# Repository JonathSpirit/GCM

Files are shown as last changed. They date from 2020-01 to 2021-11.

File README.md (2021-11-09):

# GCM - GCardMother

Copyright (C) 2021 Guillaume Guillet\
Licensed under CERN-OHL-W v2 or later

<table border="0px">
<tr>
<td>
This source describes Open Hardware and is licensed under the CERN-OHL-W v2 or later.
</td>
</tr>
<tr>
<td>
You may redistribute and modify this documentation and make products
using it under the terms of the CERN-OHL-W v2 (https:/cern.ch/cern-ohl).
This documentation is distributed WITHOUT ANY EXPRESS OR IMPLIED
WARRANTY, INCLUDING OF MERCHANTABILITY, SATISFACTORY QUALITY
AND FITNESS FOR A PARTICULAR PURPOSE. Please see the CERN-OHL-W v2
for applicable conditions.
</td>
</tr>
</table>

Made with [Kicad](https://kicad.org/)

## Description
G_CardMother is a homemade without any microcontroller motherboard for 8bits processor compatible with the [MOM1_SPS1 standard](https://github.com/JonathSpirit/GComputer_standard) like [GP8B](https://github.com/JonathSpirit/GP8B)

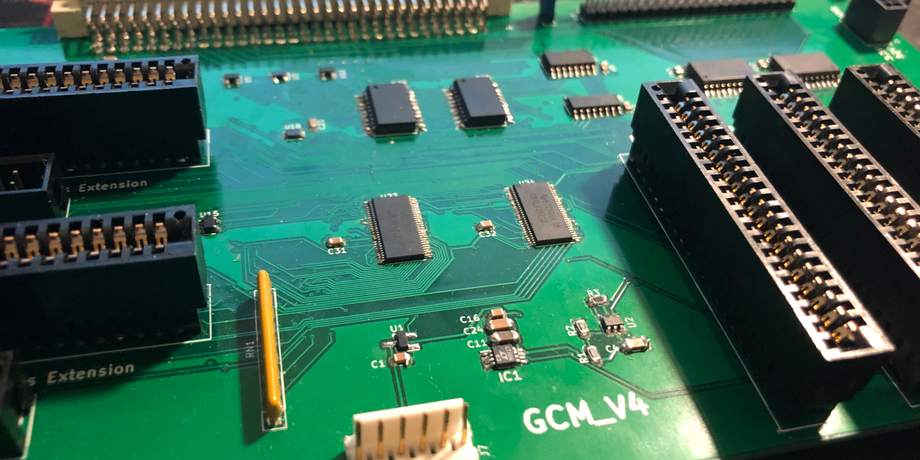
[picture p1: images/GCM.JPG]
GCM_image
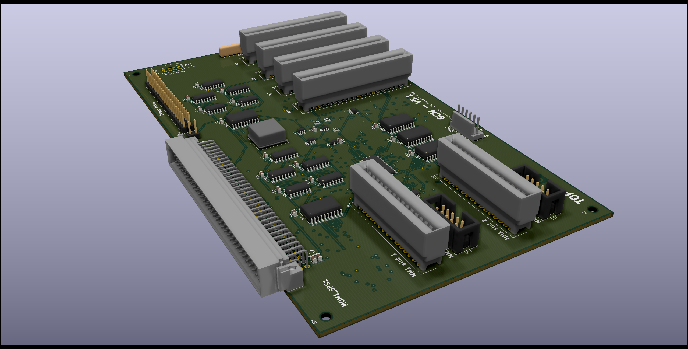
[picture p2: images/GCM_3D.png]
GCM_3D_image
 
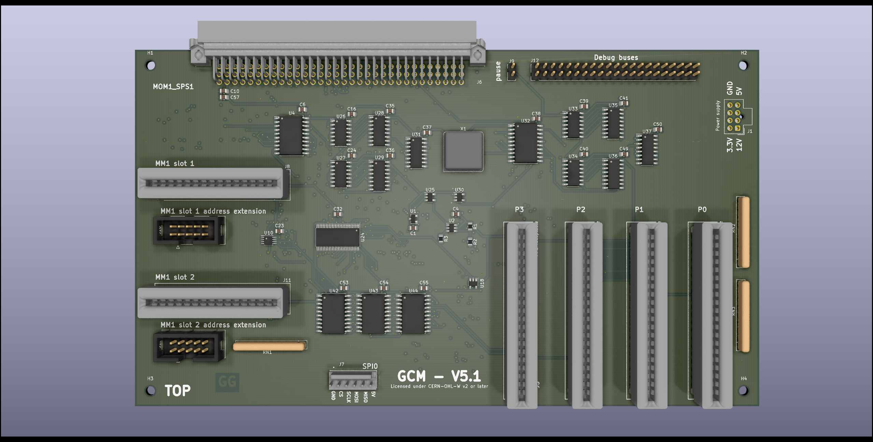
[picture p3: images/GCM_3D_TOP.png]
GCM_3D_TOP_image
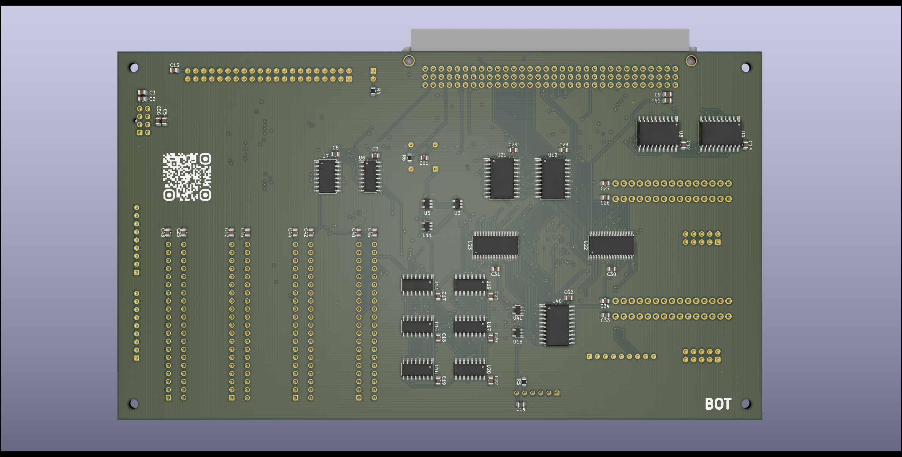
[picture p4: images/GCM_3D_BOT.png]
GCM_3D_BOT_image
 

## Stats





\
\
\


## Block diagram

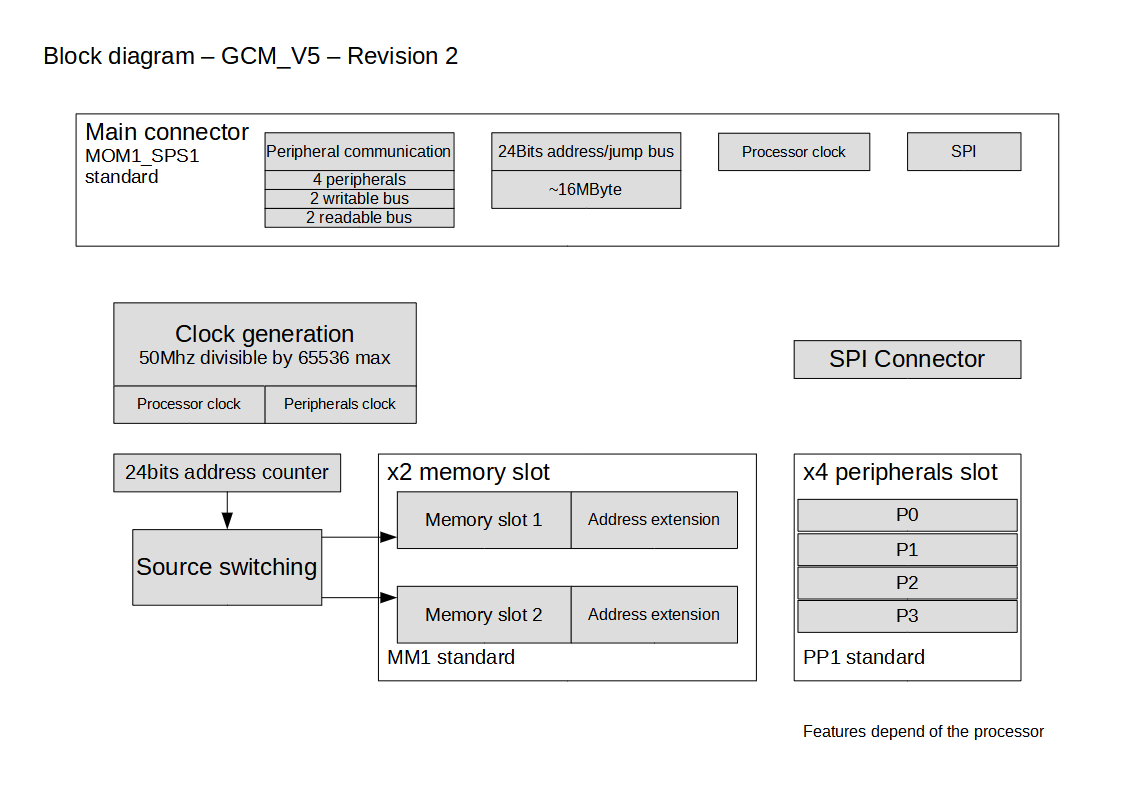
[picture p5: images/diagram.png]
Image of diagram


## Main features

- Follow the [MOM1_SPS1](https://github.com/JonathSpirit/GComputer_standard) standard.

- A max frequency of 50Mhz divisible by multiples of two (up to a division of 65536).
  For the processor and a seperated line for peripherals.

- 4 [PP1](https://github.com/JonathSpirit/GComputer_standard) peripherals slot.

- 2 [MM1](https://github.com/JonathSpirit/GComputer_standard) memory slot with address extension.

- Code execution from the memory slot 1 and switchable with the memory slot 2.

- Redirection of the writing buses (can be used as buffer).

- Accessible debug pins.

## Motherboard standard
This motherboard, follow the [MOM1_SPS1](https://github.com/JonathSpirit/GComputer_standard) standard

## Compatibility
Should be compatible with all processor following the [SPS1](https://github.com/JonathSpirit/GComputer_standard) standard

| Processor | Compatibility |
| --- | --- |
| [GP8B_V4.x](https://github.com/JonathSpirit/GP8B/tree/V4.0)  |   |
| [GP8B_V5.0](https://github.com/JonathSpirit/GP8B/tree/V5.0)  |   |
| [GP8B_V5.1+](https://github.com/JonathSpirit/GP8B/tree/V5.1)  |   |





## Documents
[Block diagram (.pdf)](documents/blockDiagram/GCM_blockDiagram.pdf)

[Schematics (.pdf)](documents/GCM_schematics.pdf)

[Materials (.pdf)](documents/GCM_materials.pdf)

[Datasheet (.pdf)](documents/GCM_datasheet.pdf)

## Contributing / Questions
Please see [Contributing file](CONTRIBUTING.md)

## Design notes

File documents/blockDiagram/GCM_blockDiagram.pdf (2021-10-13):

## x4 peripherals slot

### PP1 standard

## Clock generation

50Mhz divisible by 65536 max | SPI Connector

P0

## Block diagram – GCM_V5 – Revision 2

P1
P2
P3

## x2 memory slot

### MM1 standard

Memory slot 1 | Address extension
Memory slot 2 | Address extension

## Source switching

### 24bits address counter

## Main connector

MOM1_SPS1
standard
Peripheral communication | 24Bits address/jump bus | Processor clock
4 peripherals

2 readable bus

2 writable bus

SPI

| ~16MByte

Features depend of the processor

Processor clock Peripherals clock

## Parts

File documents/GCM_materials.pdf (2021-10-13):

1

GCM_materials.fods

GCM | V5.1
Author : Guillaume Guillet | Revision 1 | Licensed under CERN-OHL-W v2 or later
Type | Value | Q | References | Package | Manufacturer | Store | Store ID | Unit price* | Price
C | 10nF | 33 | C1, C6 to C8, C12, C13, C16 to C24, C28 to C32, C35 to C41, C49, C50, C52 to C55 | C_0805_2012Metric | KEMET | Mouser | 80-C0805C103J5R | 0.033 | 1.089
| 100nF | 20 | C3 to C5, C9 to C11, C14, C15, C25 to C27, C33, C34, C42 to C48 | C_0805_2012Metric | KEMET | Mouser | 80-C0805C104M3R | 0.032 | 0.64
| 1uF | 4 | C2, C51, C56, C57 | C_0805_2012Metric | KEMET | Mouser | 80-C0805C105K3R7210 | 0.132 | 0.528
X1 | ECS-2200BX-500 | 1 | X1 | Oscillator_DIP-8 | ECS | Mouser | 520-2200BX-500 | 2.92 | 2.92
U | 74AHC273 | 6 | U4, U32, U40, U42 to U44 | SOIC-20W_7.5x12.8mm_Pitch1.27mm | Texas Instruments | Mouser | 595-SN74AHC273DWR | 0.403 | 2.418
| LM810 | 1 | U1 | SOT-23-3 | Texas Instruments | Mouser | 926-LM810M3463NOPB | 0.696 | 0.696
| LTC6994-1 | 1 | U2 | SOT-23-6 | Analog Devices | Mouser | 584-C6994IS6-1TRMPBF | 3.65 | 3.65
| CD74AC161M | 6 | U13, U14, U16, U17, U19, U20 | SOP-16_3.9x9.9mm_P1.27mm | Texas Instruments | Mouser | 595-CD74AC161M | 0.751 | 4.506
| CD74AC151 | 6 | U28, U29, U31, U35 to U37 | SOP-16_3.9x9.9mm_P1.27mm | Texas Instruments | Mouser | 595-CD74AC151M96 | 0.823 | 4.938
| SN74LV393A | 4 | U26, U27, U33, U34 | SOIC-14_3.9x8.7mm_P1.27mm | Texas Instruments | Mouser | 595-SN74LV393ADR | 0.796 | 3.184
| CD74AC238 | 1 | U6 | SOP-16_3.9x9.9mm_P1.27mm | Texas Instruments | Mouser | 595-CD74AC238M96 | 0.549 | 0.549
| 74AHC244 | 3 | U8, U9, U12 | SOIC-20W_7.5x12.8mm_Pitch1.27mm | Texas Instruments | Mouser | 595-SN74AHC244DWR | 0.448 | 1.344
| 74AHCT244 | 1 | U21 | SOIC-20W_7.5x12.8mm_Pitch1.27mm | Texas Instruments | Mouser | 595-SN74AHCT244DWR | 0.448 | 0.448
| 74AHC138 | 1 | U7 | SOIC-16W_5.3x10.2mm_P1.27mm | Texas Instruments | Mouser | 595-SN74AHC138NSR | 0.494 | 0.494
| 74AHC1G04 | 4 | U5, U11, U18, U41 | SOT-23-5 | Texas Instruments | Mouser | 595-SN74AHC1G04DBVR | 0.266 | 1.064
| 74AHCT1G04 | 1 | U15 | SOT-23-5 | Texas Instruments | Mouser | 595-SN74AHCT1G04DBVR | 0.311 | 0.311
| 74AHC1G32 | 3 | U3, U25, U30 | SOT-23-5 | Texas Instruments | Mouser | 595-SN74AHC1G32DBVR | 0.266 | 0.798
| 74LVC1G74 | 1 | U10 | SM-8 | Texas Instruments | Mouser | 595-SN74LVC1G74DCTR | 0.604 | 0.604
| 74CBTLV16212 | 3 | U22 to U24 | TSSOP-56 | Texas Instruments | Mouser | 595-SN74CBTLV16212GR | 2.03 | 6.09
R | 523k | 1 | R1 | R_0805_2012Metric | Panasonic | Mouser | 667-ERJ-PB6D5233V | 0.256 | 0.256
| 1M | 1 | R2 | R_0805_2012Metric | Panasonic | Mouser | 667-ERJ-6RED1004V | 0.192 | 0.192

# Project :

2

GCM_materials.fods

| 305k | 1 | R3 | R_0805_2012Metric | Panasonic | Mouser | 667-ERA-6AED3093V | 0.229 | 0.229
| 10k | 3 | R4 to R6 | R_0805_2012Metric | Yageo | Mouser | 603-RT0805FRE0710KL | 0.11 | 0.33
RN | 8x10k | 3 | RN1 to RN3 | R_Array_SIP9 | Bourns | Mouser | 652-4609X-1LF-10K | 0.247 | 0.741
J | TE_Eurocard_96pole | 1 | J6 | Eurocard_5650473-5 Receptacle | TE connectivity | Mouser | 571-5650461-5 | 5.38 | 5.38
| Nano-Fit power connectors | 1 | J1 | Molex_1053102116 | Molex | Mouser | 538-105310-1108 | 1.6 | 1.6
| 5530843-2 | 2 | J8, J11 | TE_5530843-2 | TE connectivity | Mouser | 571-5530843-2 | 2.33 | 4.66
| 5-5530843-4 | 4 | J2 to J5 | 5-5530843-4 | TE connectivity | Mouser | 571-5-5530843-4 | 2.84 | 11.36
| 3-641124-6 | 1 | J7 | 3-641124-6 | TE connectivity | Mouser | 571-3-641124-6 | 1.36 | 1.36
| Header10p | 2 | J10, J13 | Header_10p_2.54 | Wurth Electronics | Mouser | 710-61201021621 | 0.411 | 0.822
| Conn_01x02_Male | 1 | J9 | PinHeader_1x02_P2.54mm_Vertical | TE connectivity | Mouser | 571-1037412 | 0.234 | 0.234
| Conn_02x21_Male | 1 | J12 | PinHeader_2x21_P2.54mm_Vertical | TE connectivity | Mouser | 571-9-146258-0 | 3.22 | 3.22
- | PCB_GCM_V5.x | 1 | - | - | G.Guillet | - | | | 0
Total price : | 66.655
*Depend of the quantity | Price is in CHF

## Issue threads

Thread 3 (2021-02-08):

Component J9 in the BOM is wrong

JonathSpirit, 2021-02-08:
The component J9, ref 571-6404524 from Mouser is wrong

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

Wanted :
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

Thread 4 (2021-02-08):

Component J12 must be a male connector

JonathSpirit, 2021-02-08:
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

(wrong footprint)

JonathSpirit, 2021-02-16:
And J9 too

JonathSpirit, 2021-02-16:
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

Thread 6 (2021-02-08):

Need another footprint for J7

JonathSpirit, 2021-02-08:
The actual footprint doesn't match the component in the BOM

JonathSpirit, 2021-02-16:
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

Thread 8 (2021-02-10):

Back a little the MM1 connectors

JonathSpirit, 2021-02-10:
the connectors are a little too close to the edge

JonathSpirit, 2021-02-16:
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

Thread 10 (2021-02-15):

Need 1uF or more power decoupling next to the nano-fit power connector

JonathSpirit, 2021-02-15:
I think that the motherboard need better and bigger decoupling capacitor next to the power connector

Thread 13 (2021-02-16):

For U22 U23 U24, replace the decoupling capacitor

JonathSpirit, 2021-02-16:
capa must be placed between pin 17 and 8

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

JonathSpirit, 2021-02-16:
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

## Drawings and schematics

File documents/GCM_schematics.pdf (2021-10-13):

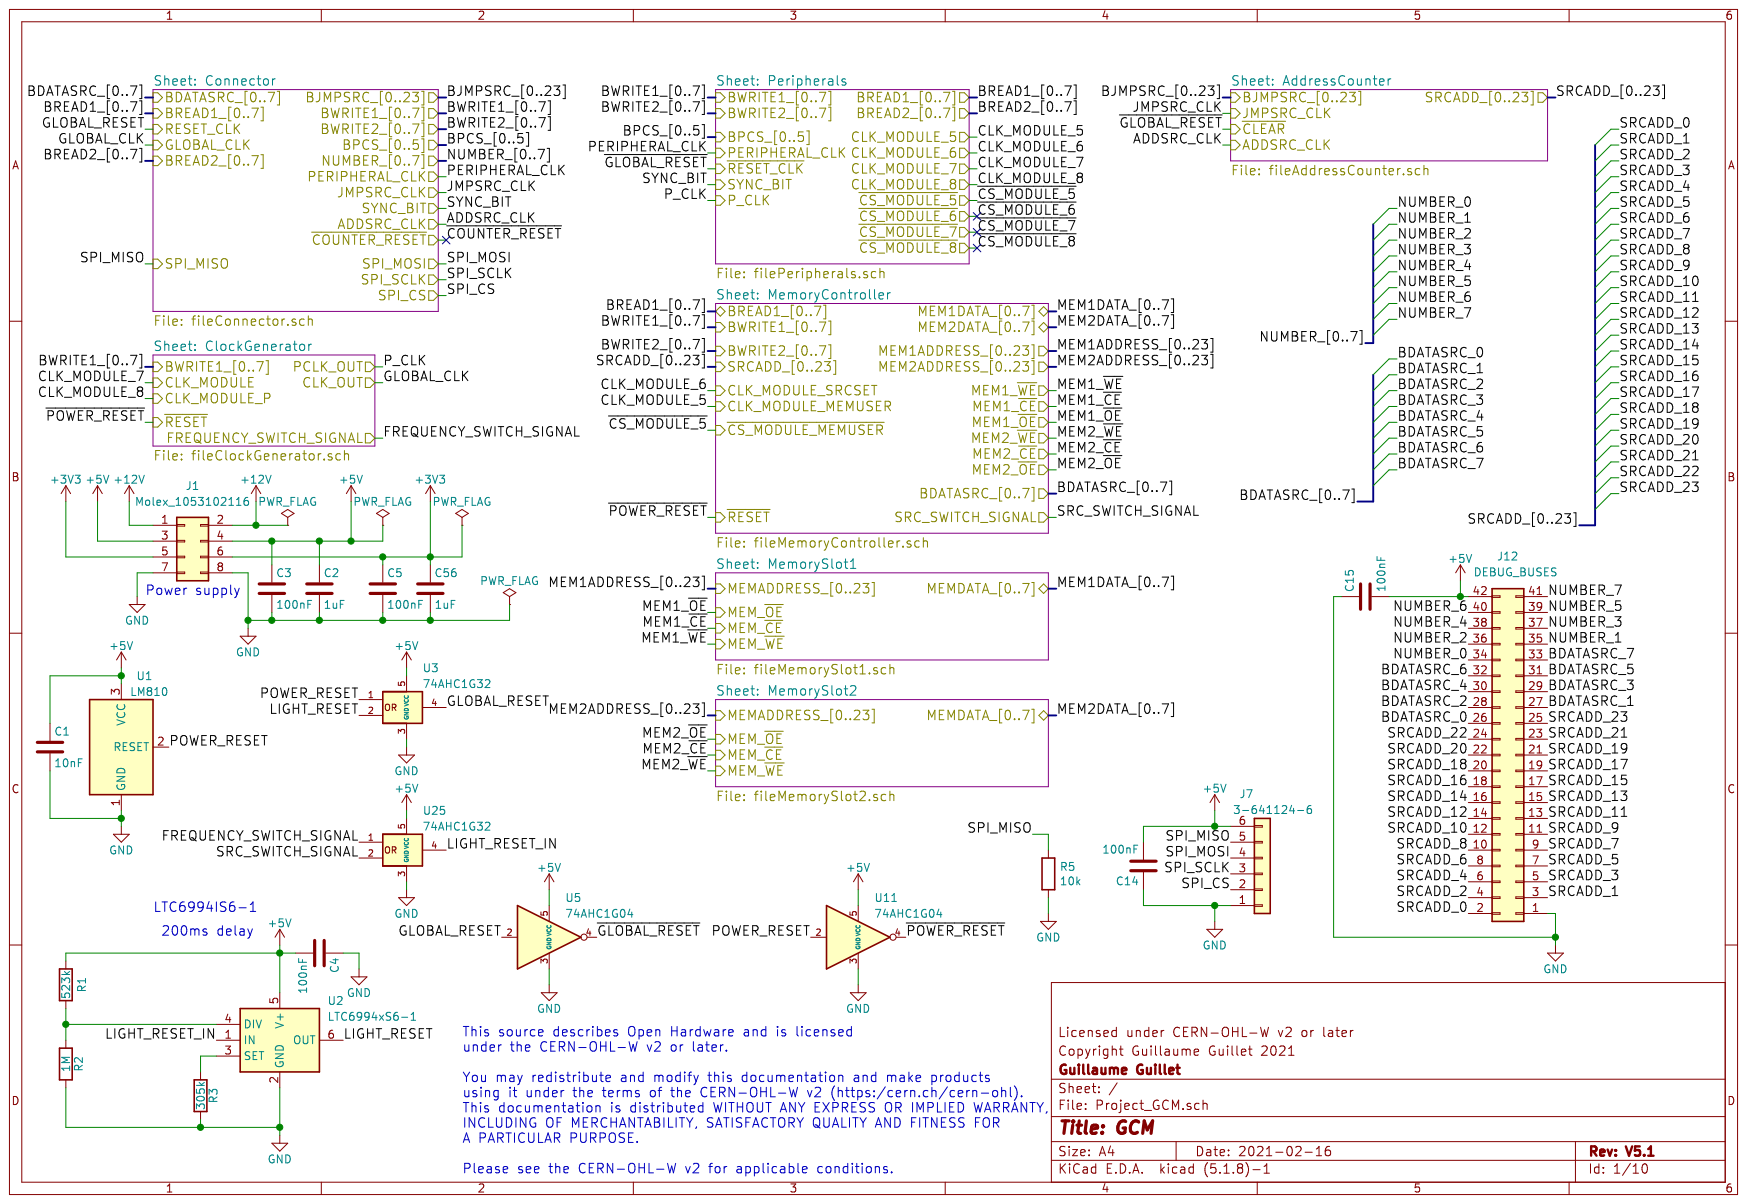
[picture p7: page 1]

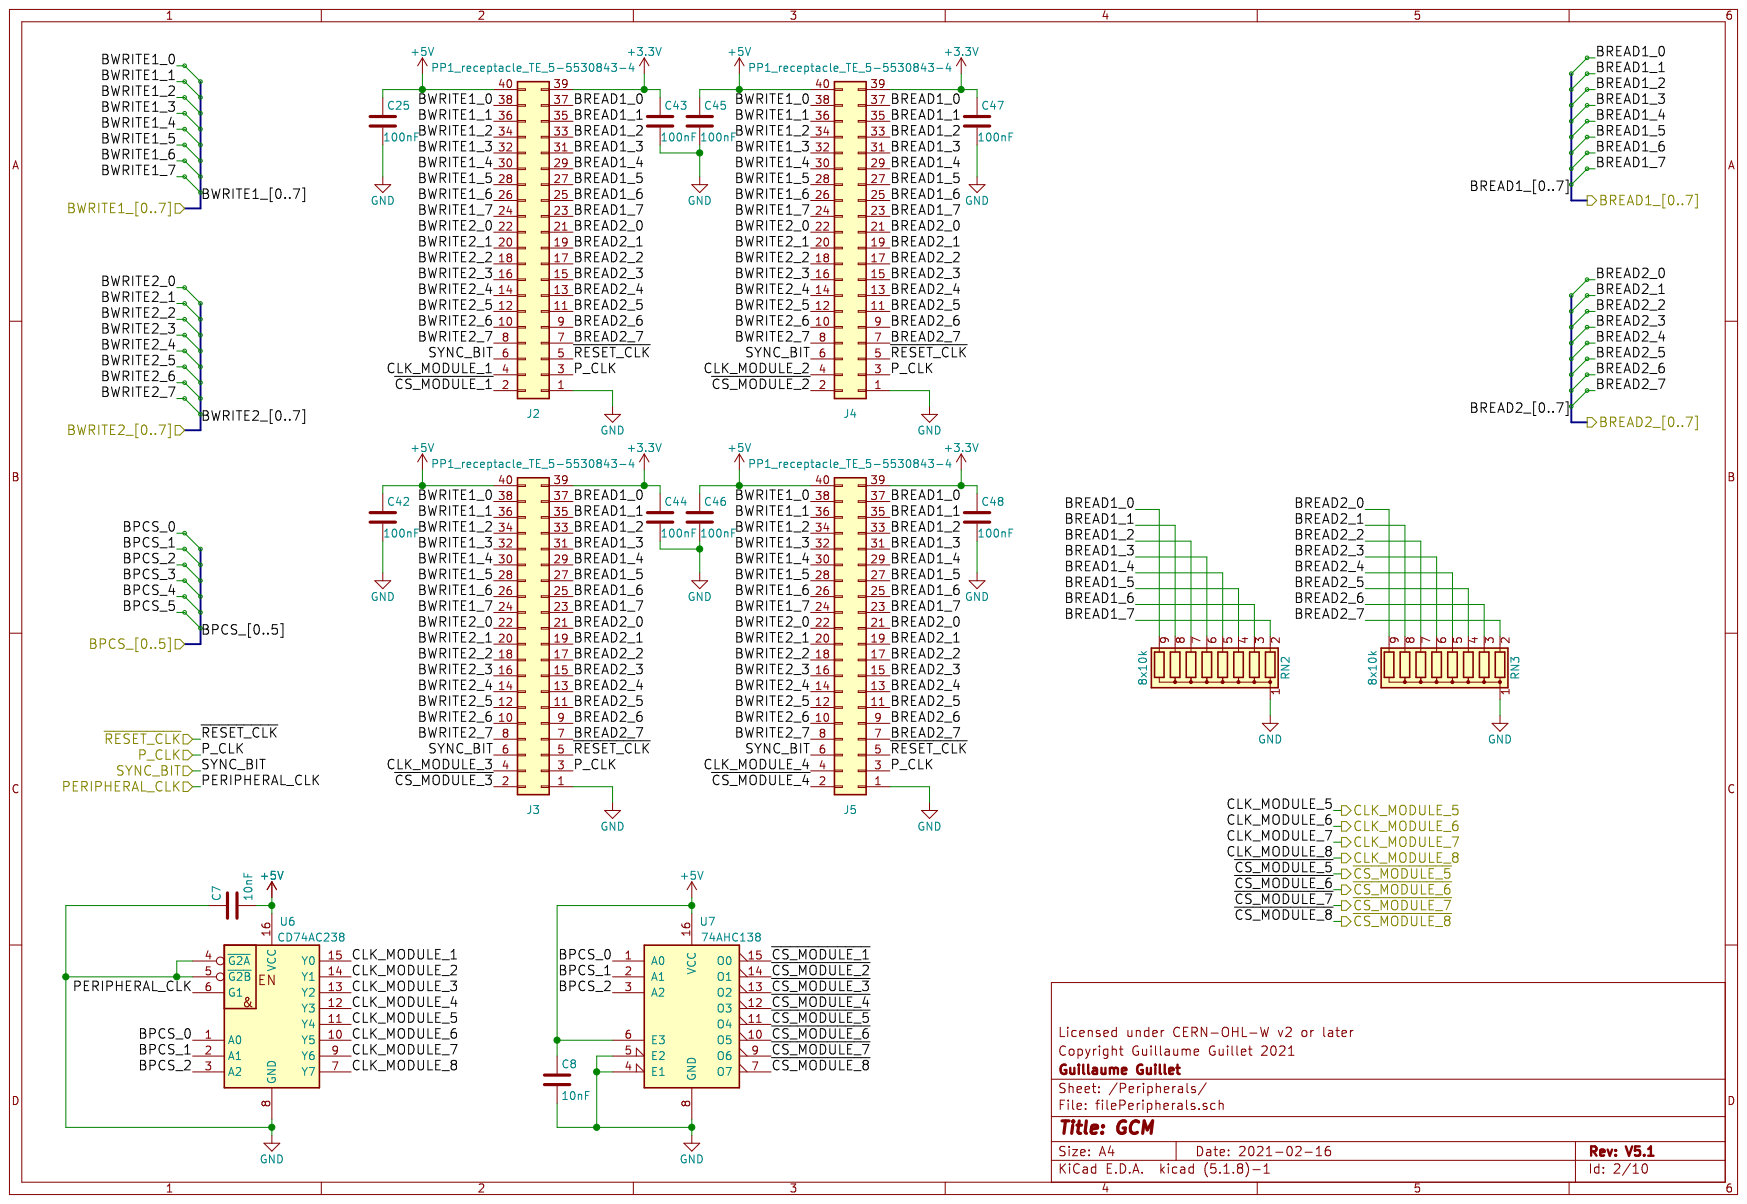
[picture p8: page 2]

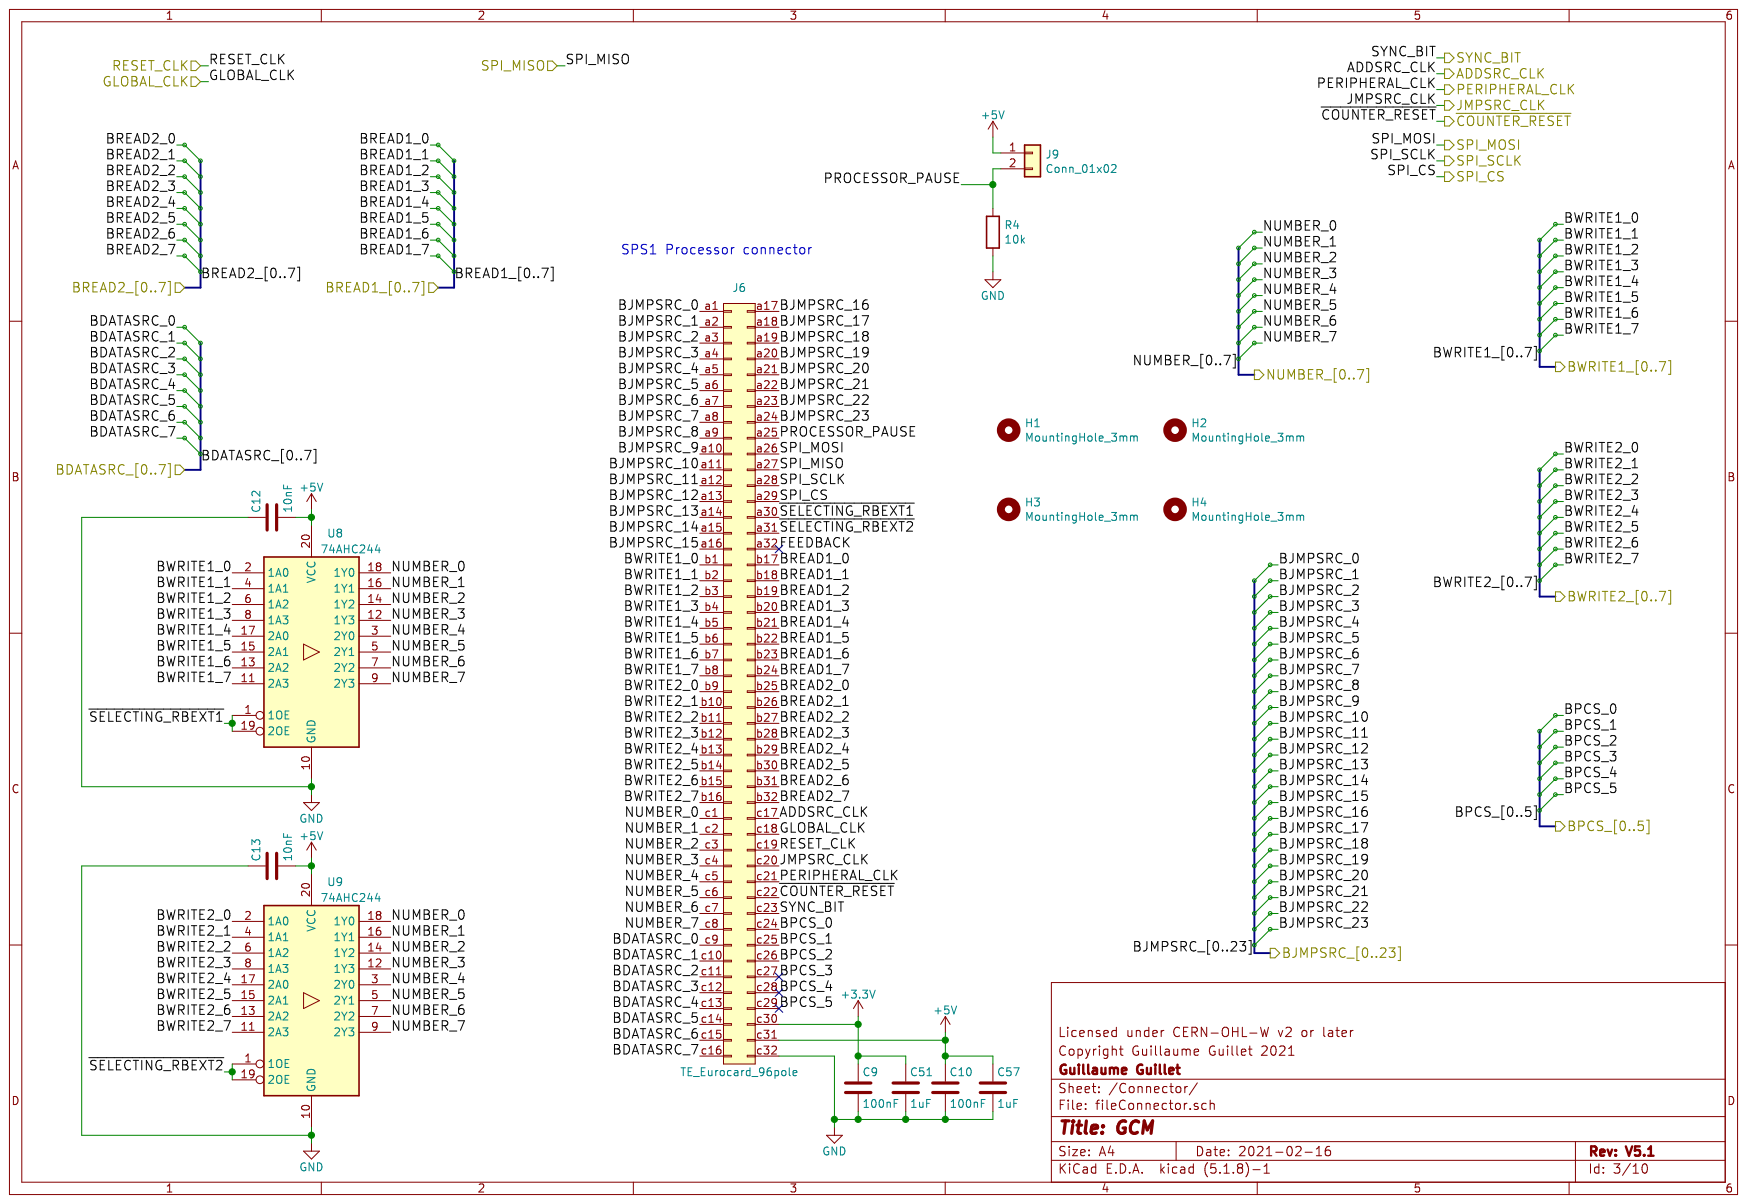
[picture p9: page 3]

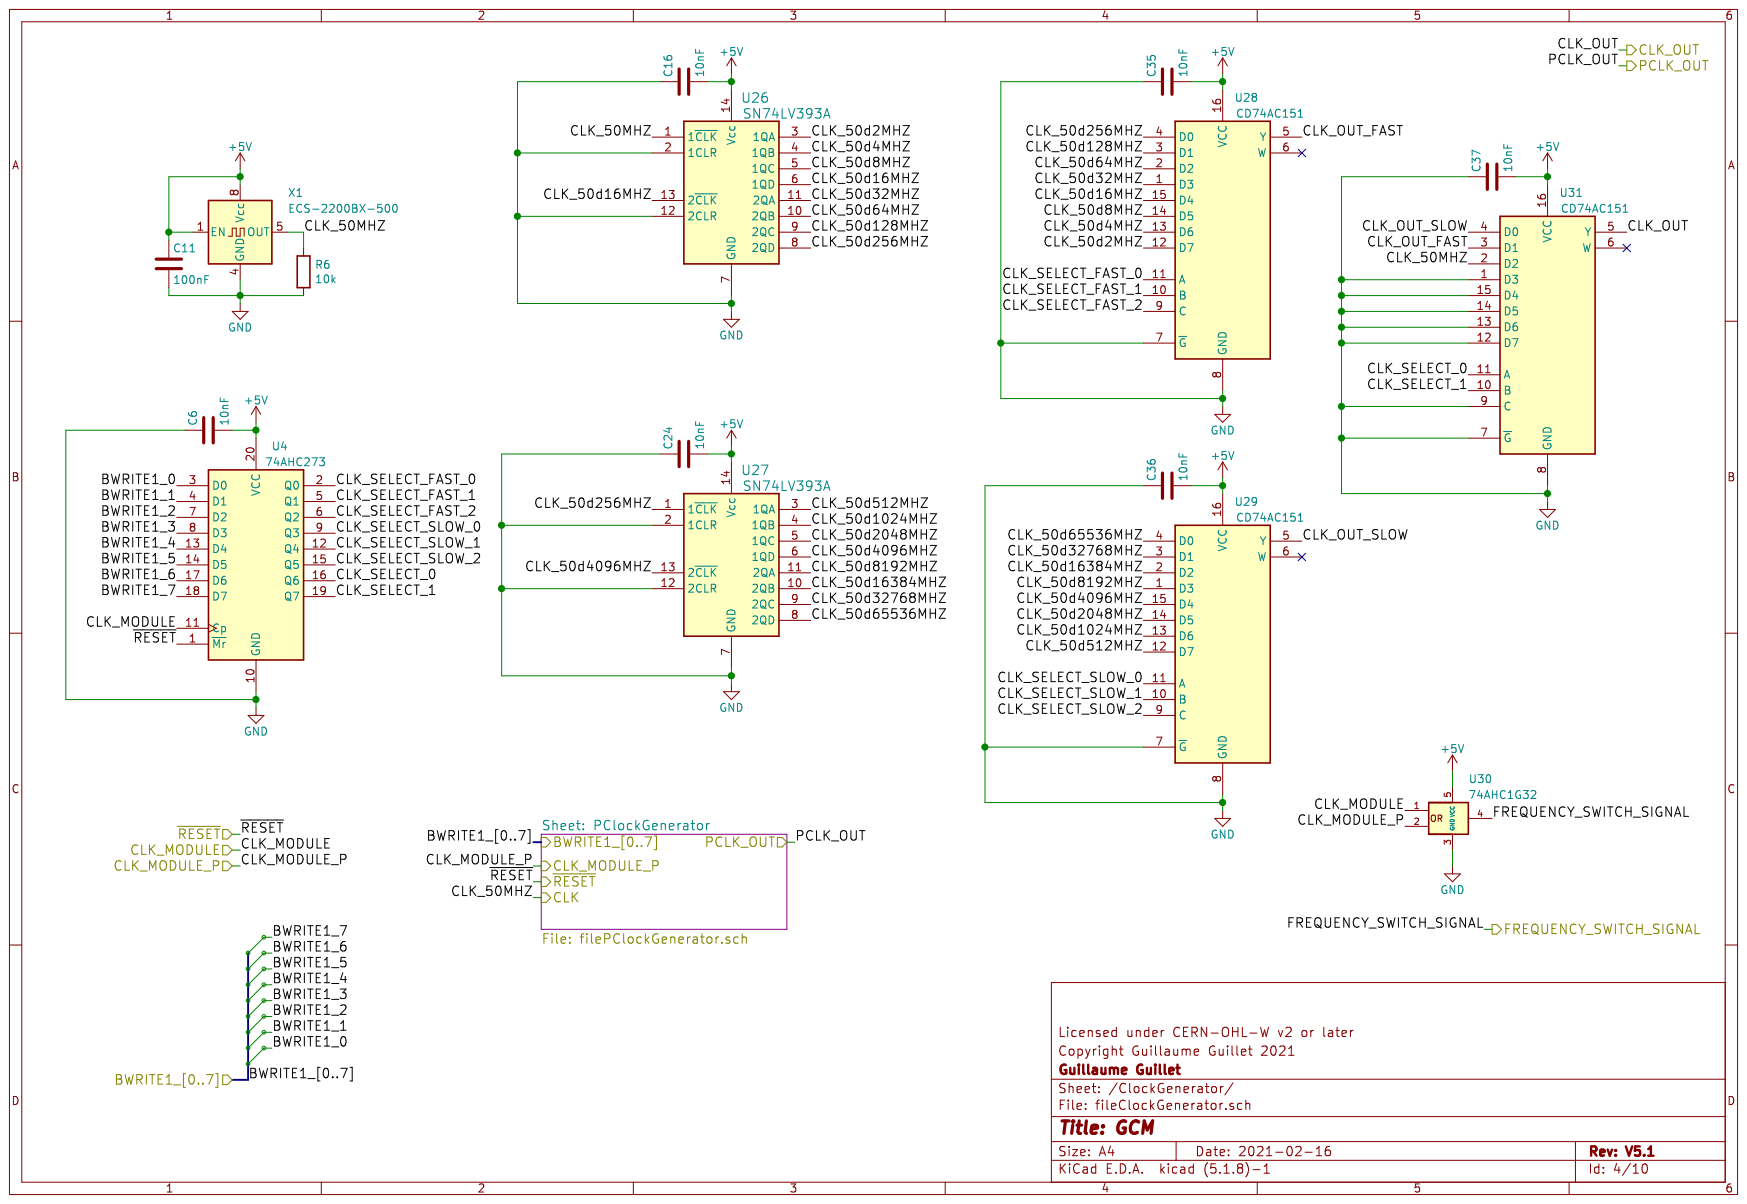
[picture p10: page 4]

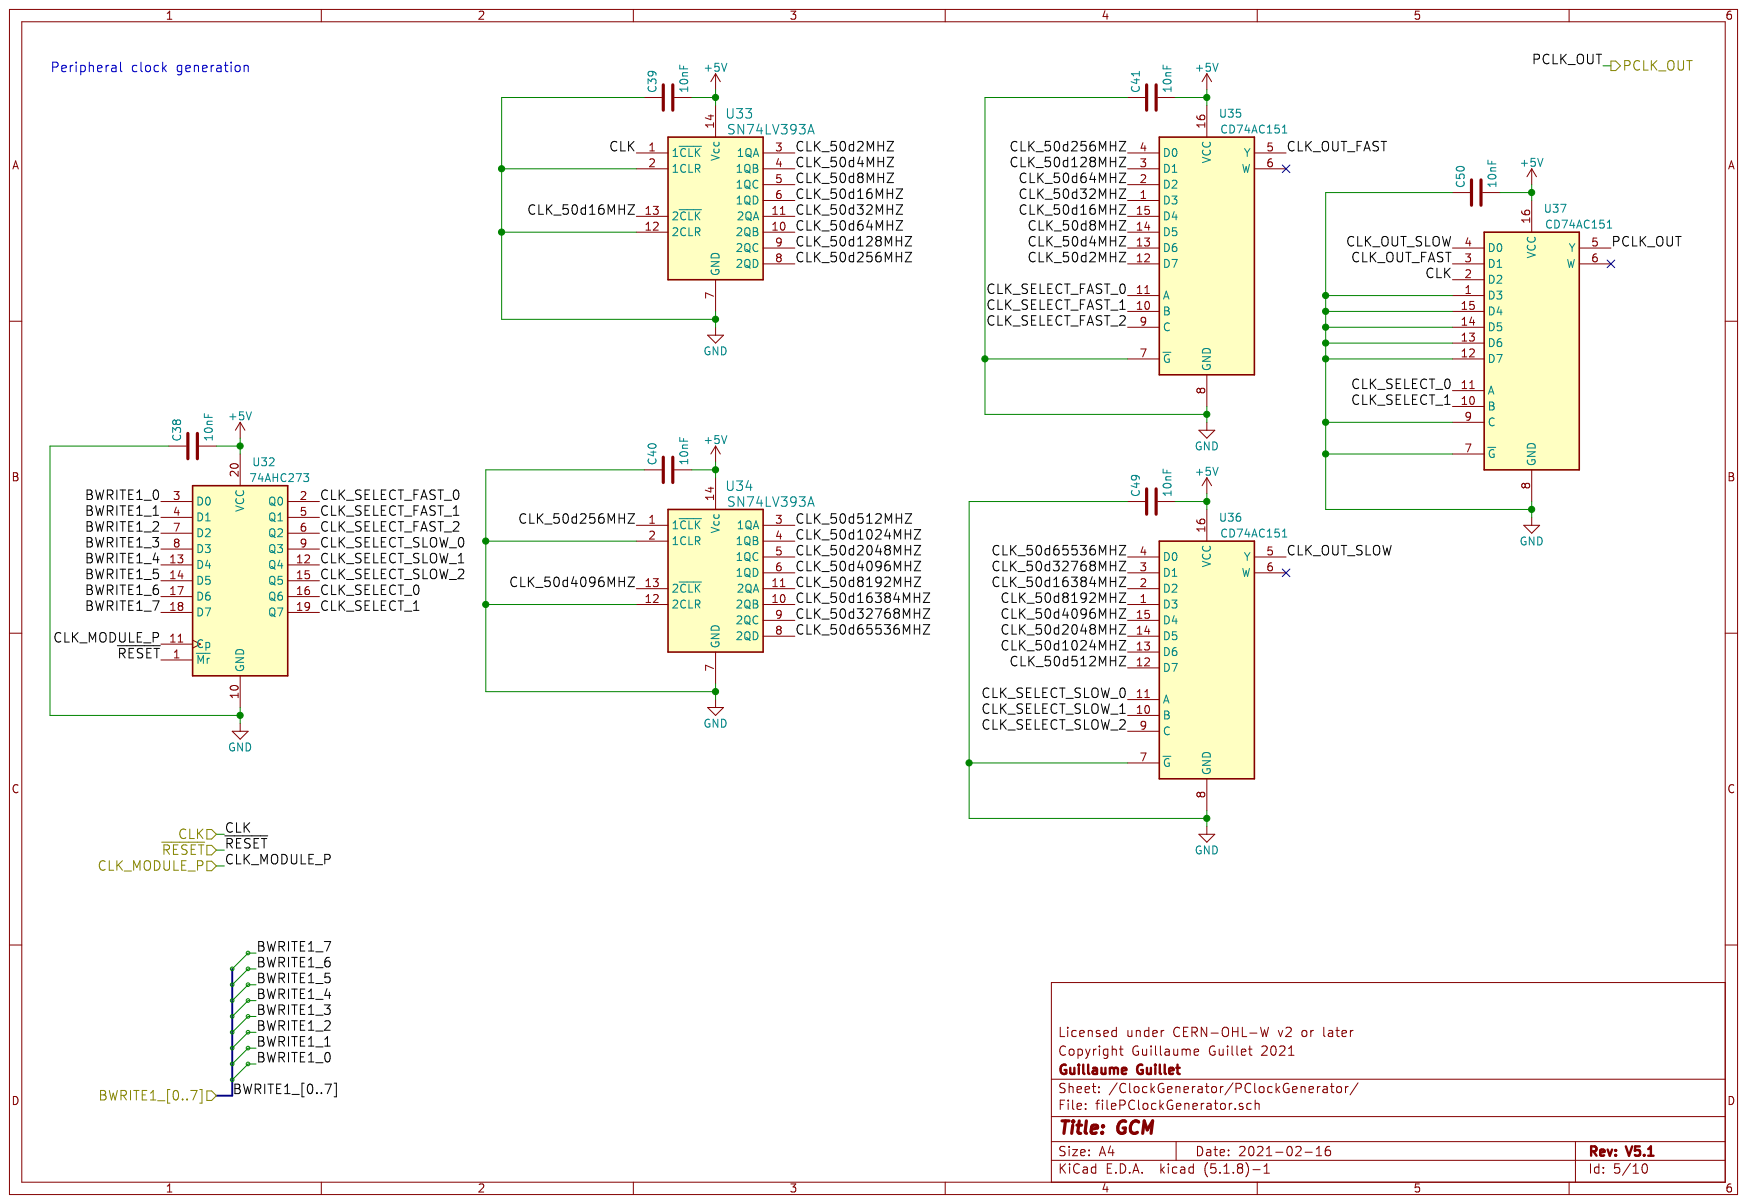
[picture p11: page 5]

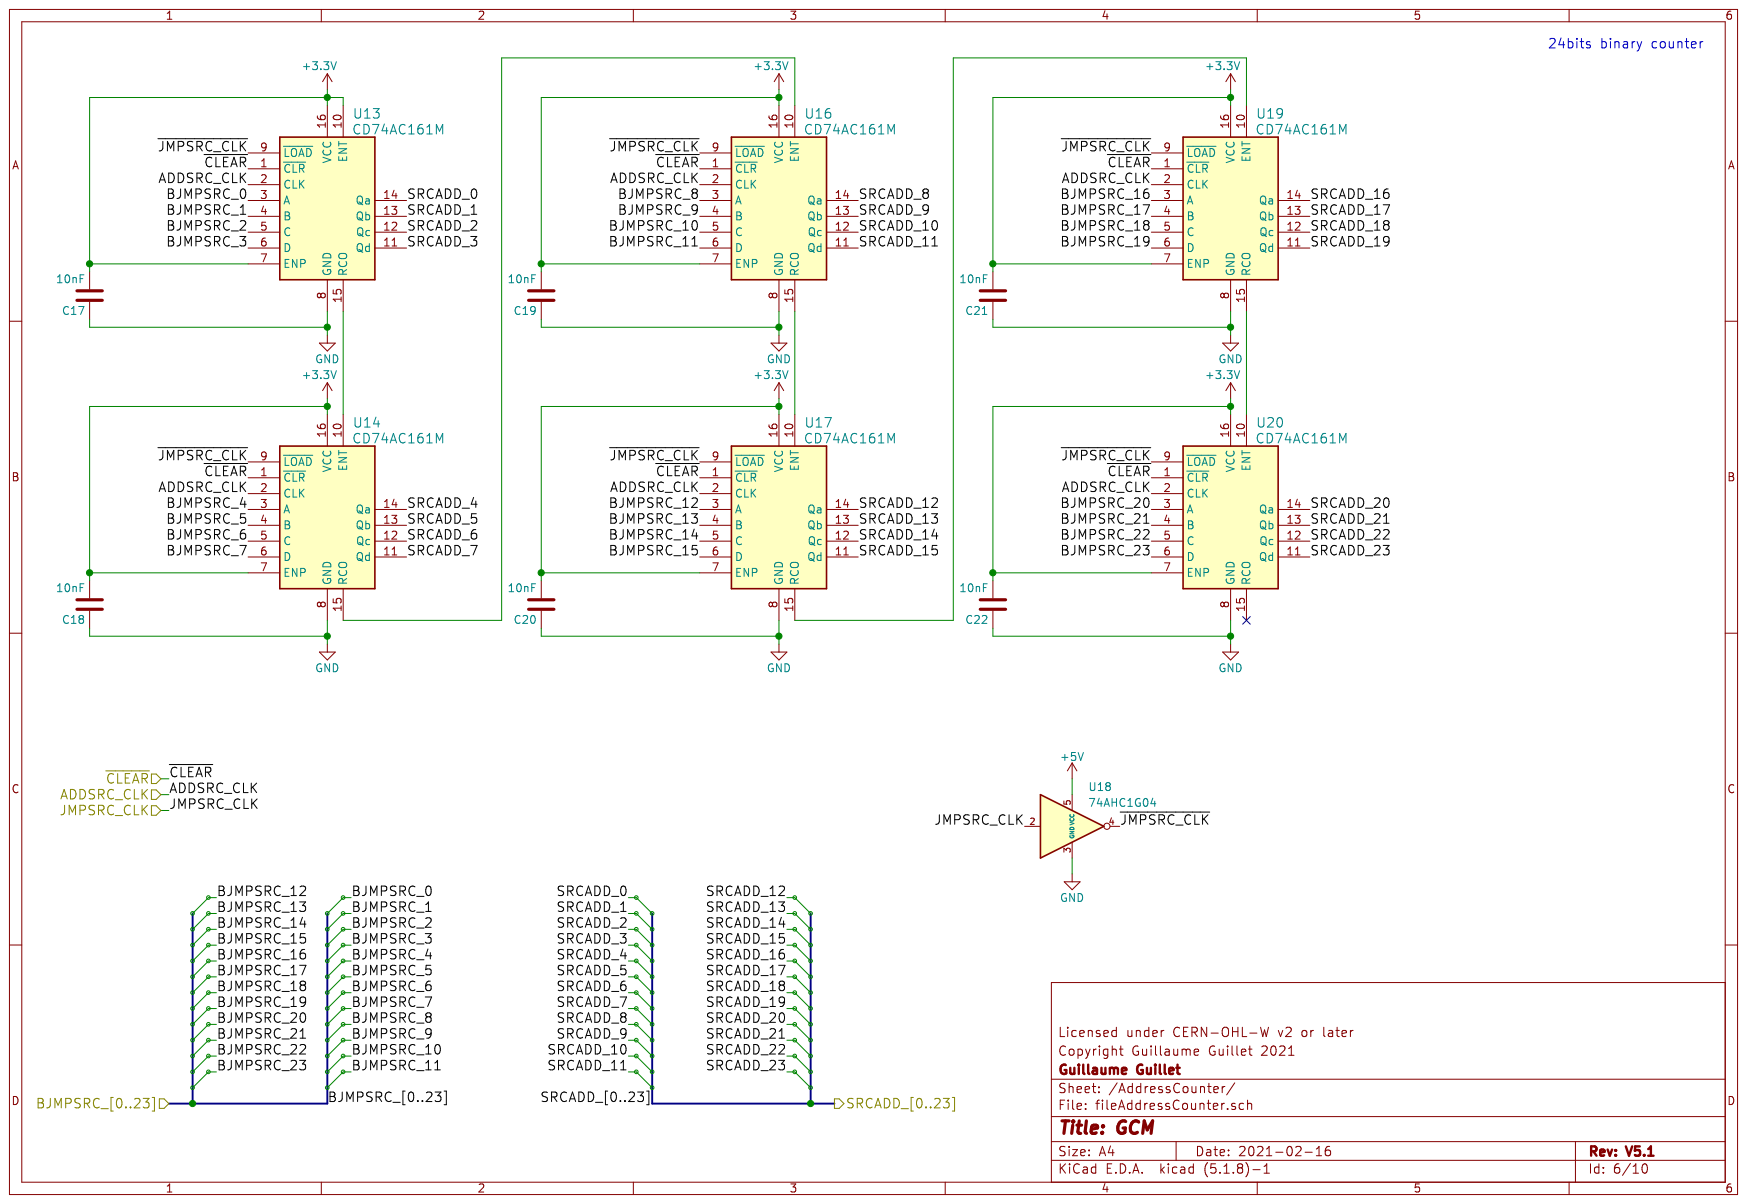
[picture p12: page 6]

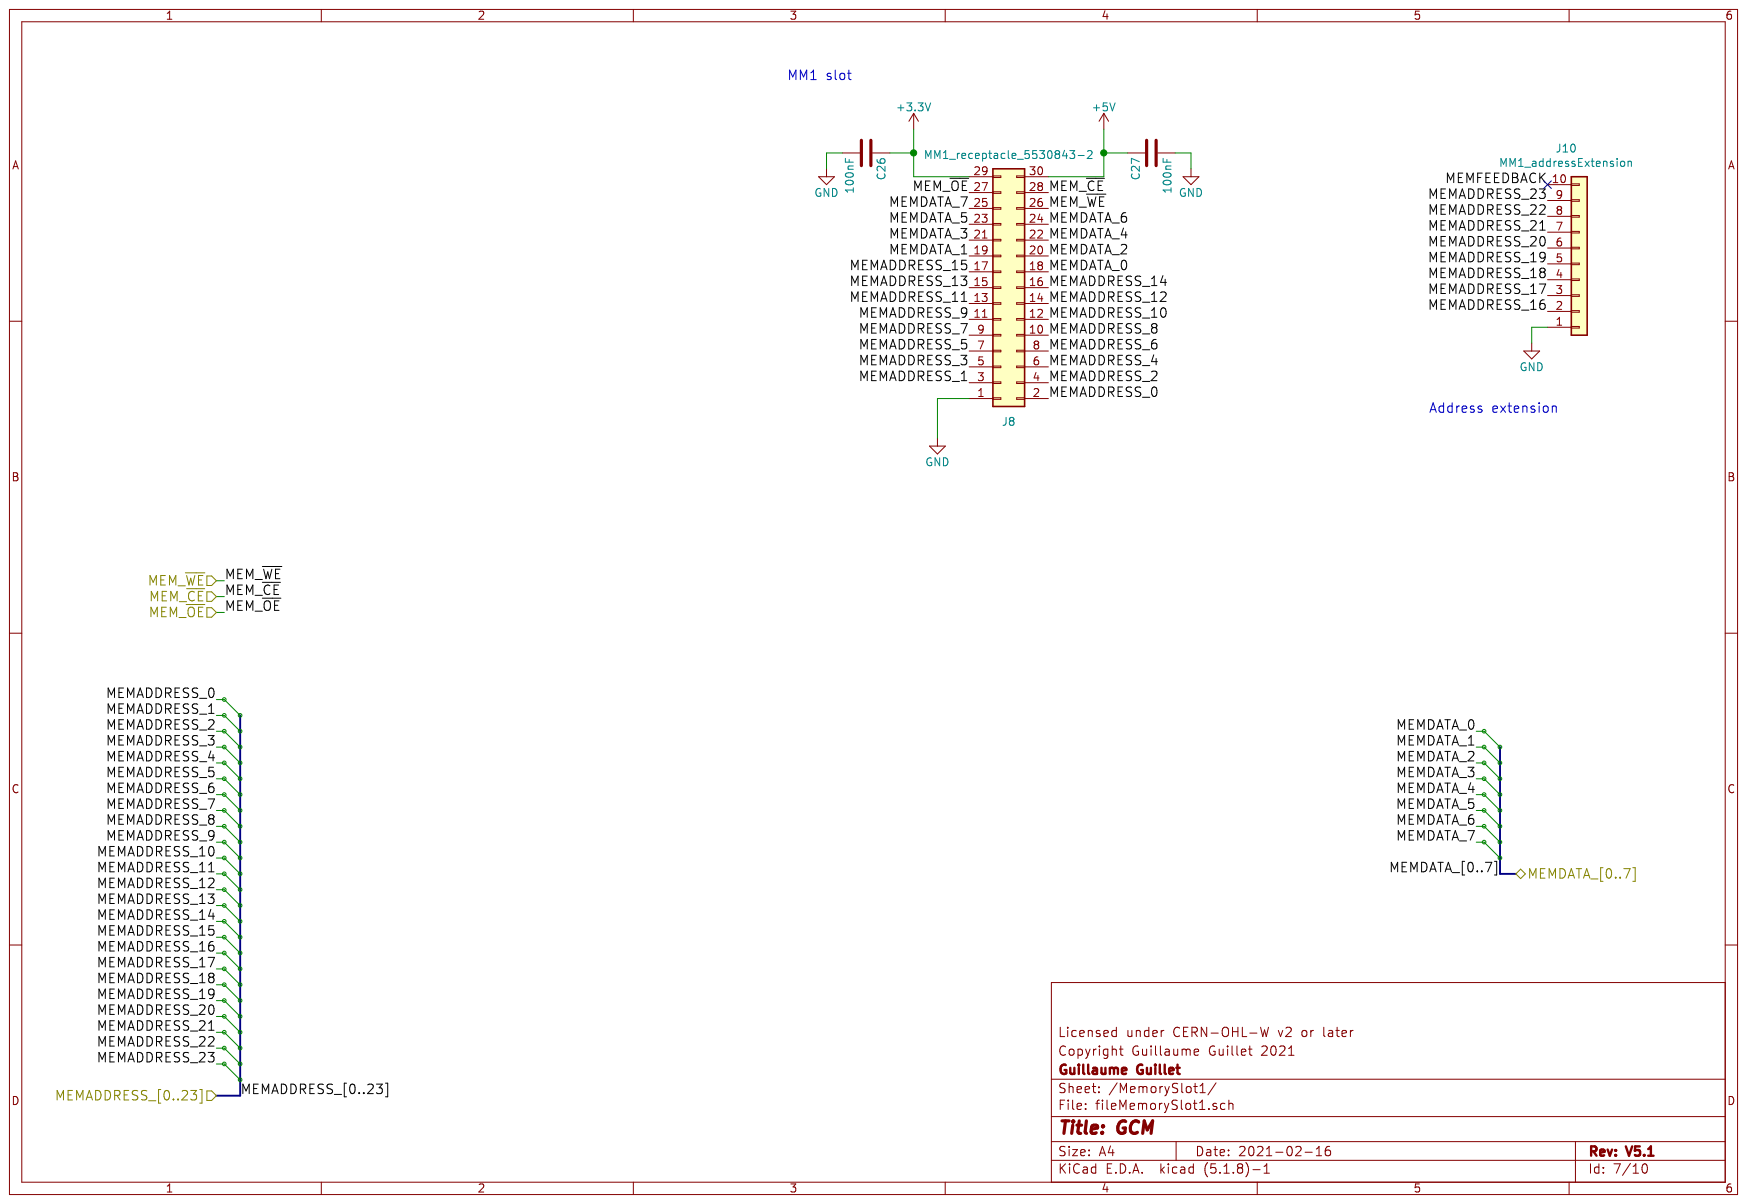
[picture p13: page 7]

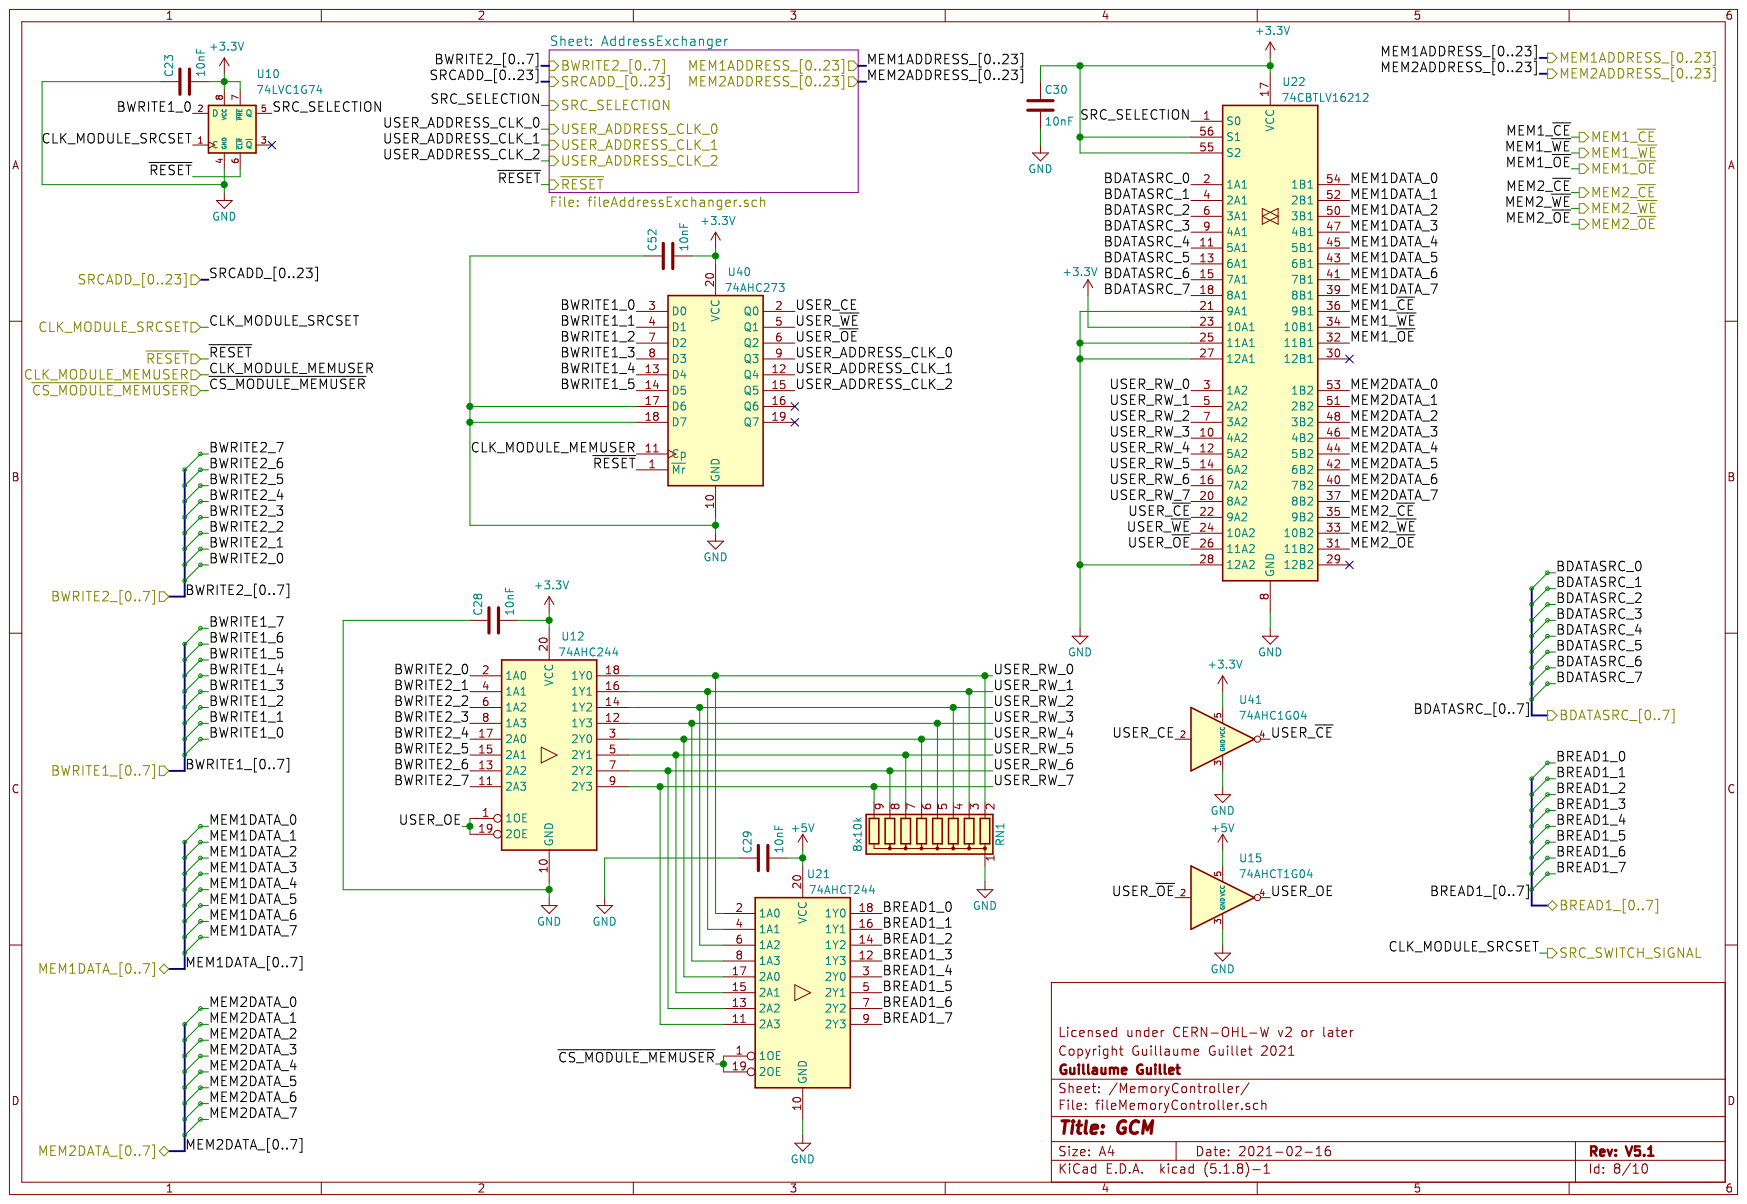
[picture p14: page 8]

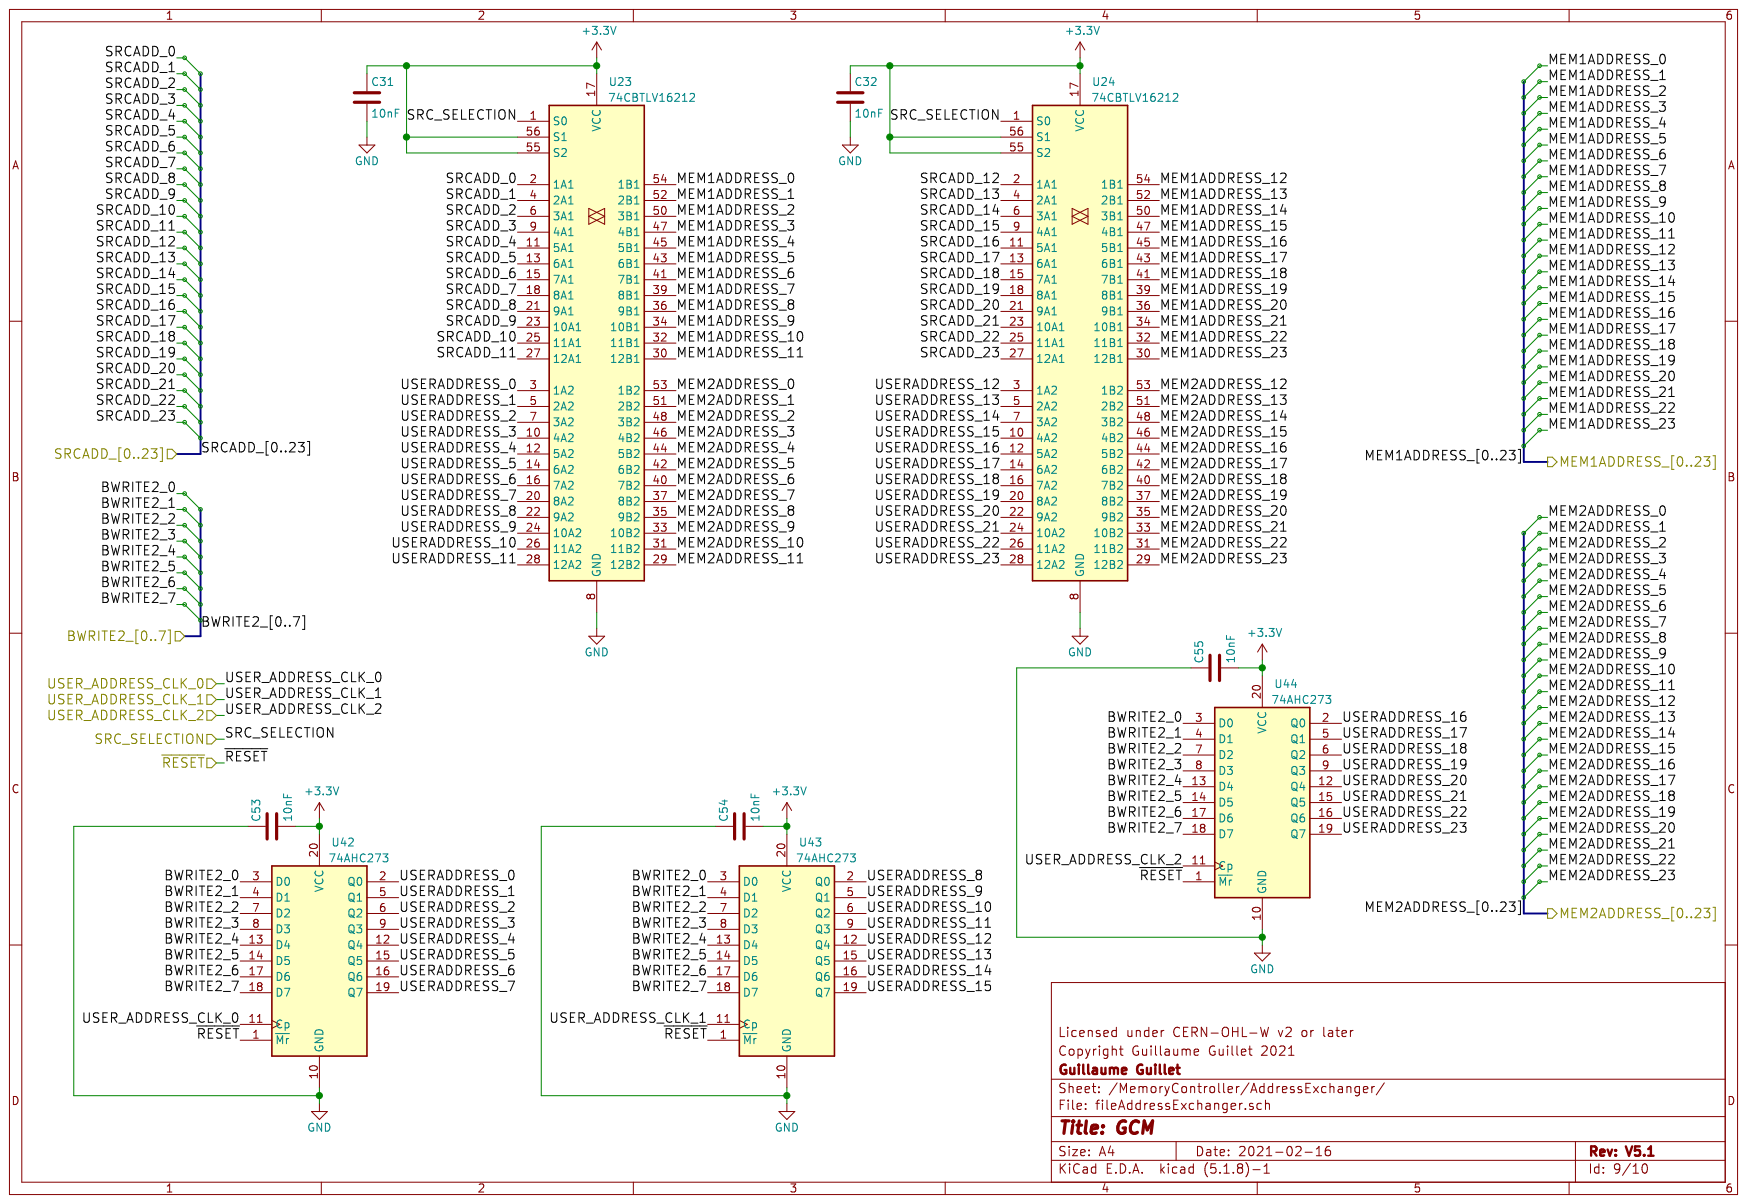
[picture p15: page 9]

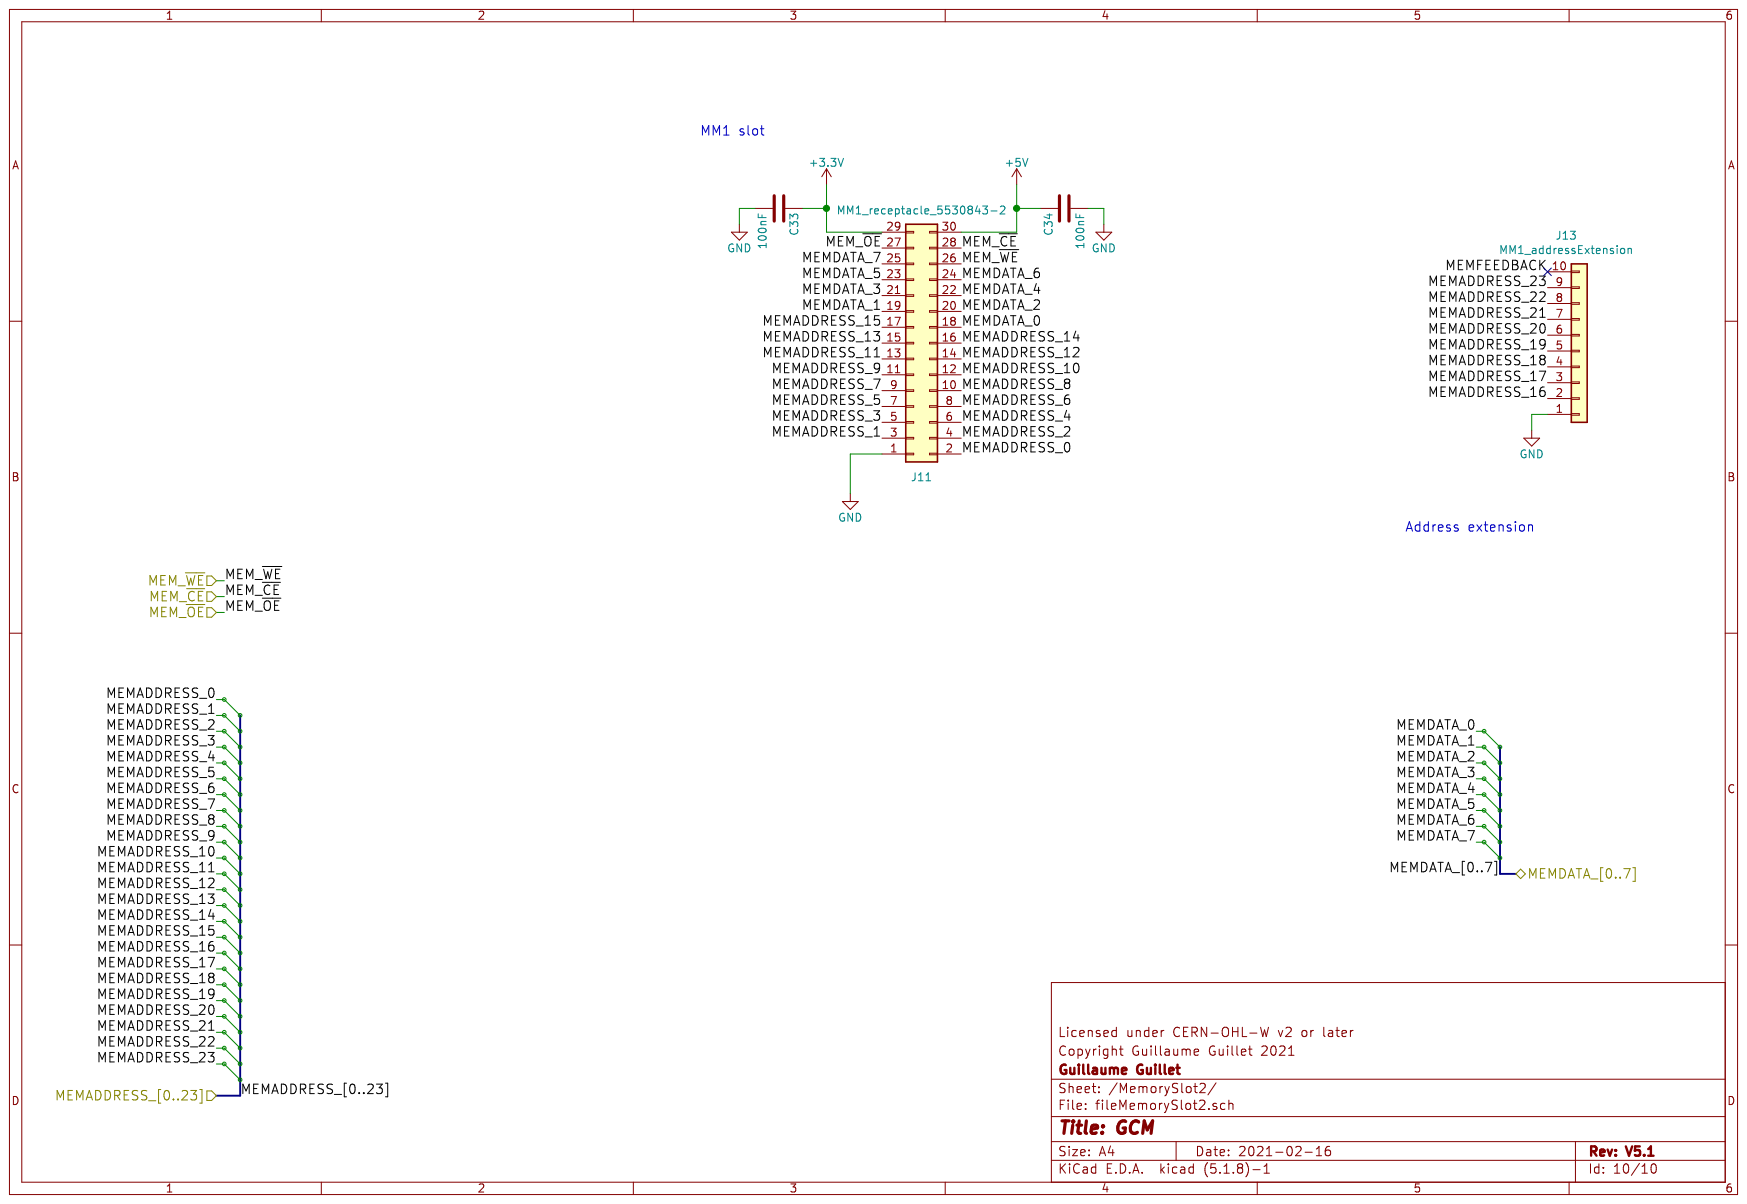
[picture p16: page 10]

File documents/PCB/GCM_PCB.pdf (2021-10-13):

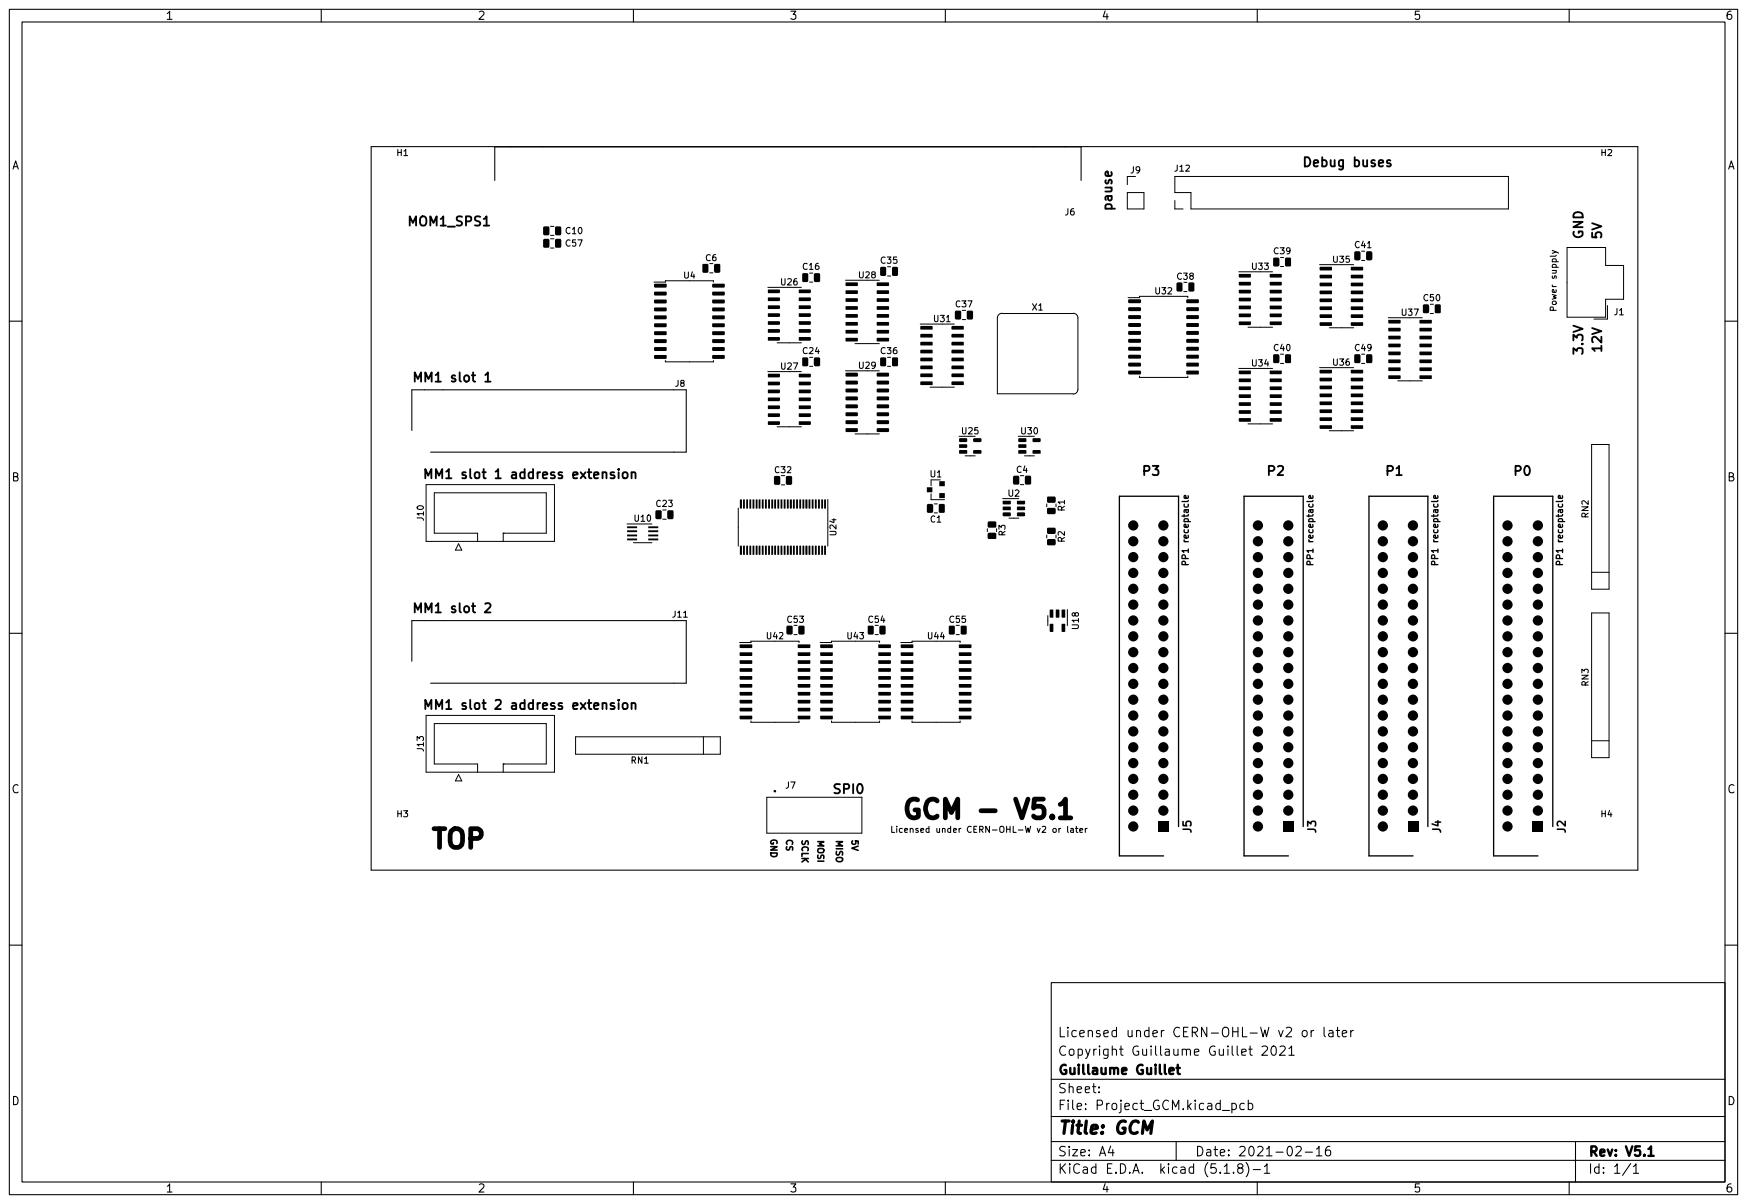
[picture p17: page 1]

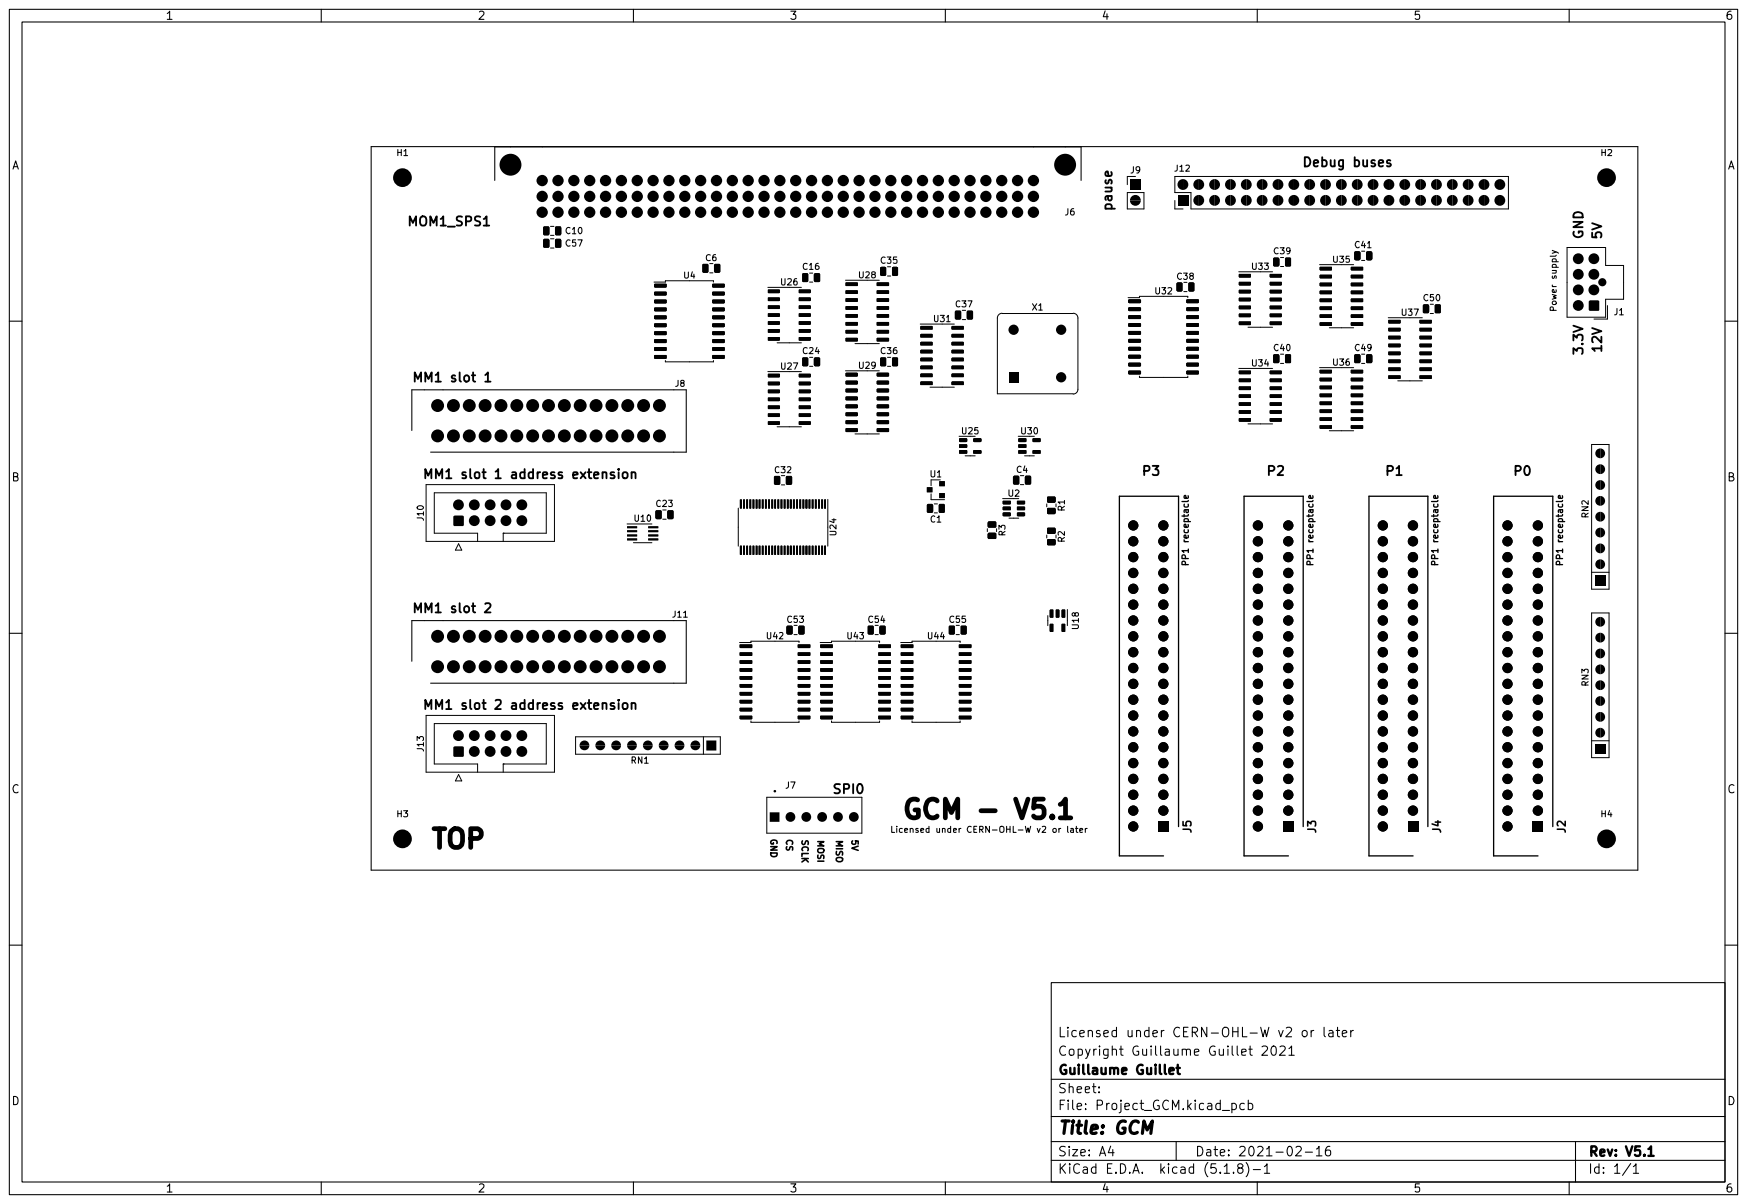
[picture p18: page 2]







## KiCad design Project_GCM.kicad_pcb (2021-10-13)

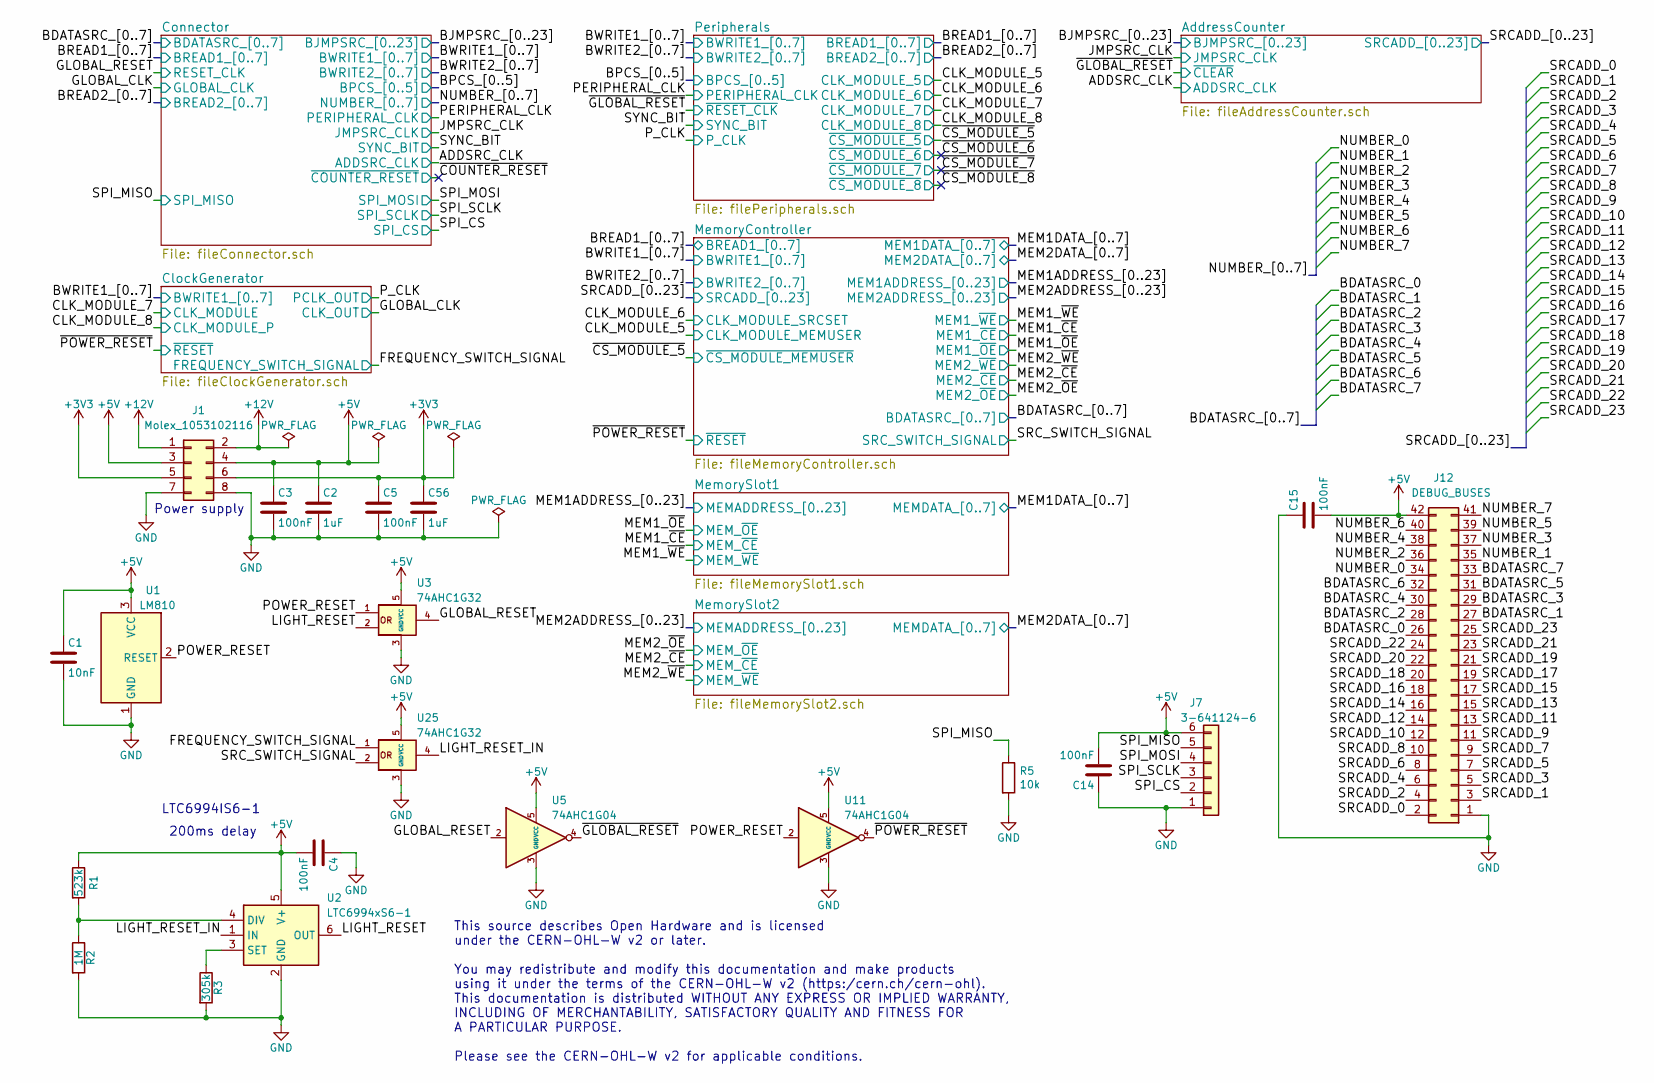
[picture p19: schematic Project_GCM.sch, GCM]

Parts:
C1: 10nF; C_0805_2012Metric
C2, C56: 1uF; C_0805_2012Metric
C3, C4, C5, C14, C15: 100nF; C_0805_2012Metric
J1: Molex_1053102116; Molex_Nano-Fit_105310-xx08_2x04_P2.50mm_Vertical
J7: 3-641124-6; TE_3-641124-6
J12: DEBUG_BUSES; PinHeader_2x21_P2.54mm_Vertical
R1: 523k; R_0805_2012Metric
R2: 1M; R_0805_2012Metric
R3: 305k; R_0805_2012Metric
R5: 10k; R_0805_2012Metric
U1: LM810; SOT-23
U2: LTC6994xS6-1; TSOT-23-6
U3, U25: 74AHC1G32; SOT-23-5
U5, U11: 74AHC1G04; SOT-23-5

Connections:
+5V: C1.1, C2.1, C3.1, C4.2, C14.2, C15.2, J1.3, J1.4, J7.6, J12.42, R1.1, U1.3 (VCC), U2.5 (V+), U3.5 (VCC), U5.5 (VCC), U11.5 (VCC), U25.5 (VCC); also elsewhere on the board
+12V: J1.1, J1.2
/BDATASRC_0: J12.26; also elsewhere on the board
/BDATASRC_1: J12.27; also elsewhere on the board
/BDATASRC_2: J12.28; also elsewhere on the board
/BDATASRC_3: J12.29; also elsewhere on the board
/BDATASRC_4: J12.30; also elsewhere on the board
/BDATASRC_5: J12.31; also elsewhere on the board
/BDATASRC_6: J12.32; also elsewhere on the board
/BDATASRC_7: J12.33; also elsewhere on the board
/CLK_MODULE_6: U25.2; also elsewhere on the board
/FREQUENCY_SWITCH_SIGNAL: U25.1; also elsewhere on the board
/GLOBAL_RESET: U3.4, U5.2; also elsewhere on the board
/LIGHT_RESET: U2.6 (OUT), U3.2
/LIGHT_RESET_IN: U2.1 (IN), U25.4
/NUMBER_0: J12.34; also elsewhere on the board
/NUMBER_1: J12.35; also elsewhere on the board
/NUMBER_2: J12.36; also elsewhere on the board
/NUMBER_3: J12.37; also elsewhere on the board
/NUMBER_4: J12.38; also elsewhere on the board
/NUMBER_5: J12.39; also elsewhere on the board
/NUMBER_6: J12.40; also elsewhere on the board
/NUMBER_7: J12.41; also elsewhere on the board
/POWER_RESET: U1.2 (RESET), U3.1, U11.2
/SPI_CS: J7.2; also elsewhere on the board
/SPI_MISO: J7.5, R5.1; also elsewhere on the board
/SPI_MOSI: J7.4; also elsewhere on the board
/SPI_SCLK: J7.3; also elsewhere on the board
/SRCADD_0: J12.2; also elsewhere on the board
/SRCADD_1: J12.3; also elsewhere on the board
/SRCADD_2: J12.4; also elsewhere on the board
/SRCADD_3: J12.5; also elsewhere on the board
/SRCADD_4: J12.6; also elsewhere on the board
/SRCADD_5: J12.7; also elsewhere on the board
/SRCADD_6: J12.8; also elsewhere on the board
/SRCADD_7: J12.9; also elsewhere on the board
/SRCADD_8: J12.10; also elsewhere on the board
/SRCADD_9: J12.11; also elsewhere on the board
/SRCADD_10: J12.12; also elsewhere on the board
/SRCADD_11: J12.13; also elsewhere on the board
/SRCADD_12: J12.14; also elsewhere on the board
/SRCADD_13: J12.15; also elsewhere on the board
/SRCADD_14: J12.16; also elsewhere on the board
/SRCADD_15: J12.17; also elsewhere on the board
/SRCADD_16: J12.18; also elsewhere on the board
/SRCADD_17: J12.19; also elsewhere on the board
/SRCADD_18: J12.20; also elsewhere on the board
/SRCADD_19: J12.21; also elsewhere on the board
/SRCADD_20: J12.22; also elsewhere on the board
/SRCADD_21: J12.23; also elsewhere on the board
/SRCADD_22: J12.24; also elsewhere on the board
/SRCADD_23: J12.25; also elsewhere on the board
/~GLOBAL_RESET: U5.4; also elsewhere on the board
/~POWER_RESET: U11.4; also elsewhere on the board
GND: C1.2, C2.2, C3.2, C4.1, C5.2, C14.1, C15.1, C56.2, J1.7, J1.8, J7.1, J12.1, R2.2, R3.2, R5.2, U1.1 (GND), U2.2 (GND), U3.3 (GND), U5.3 (GND), U11.3 (GND), U25.3 (GND); also elsewhere on the board
unnamed: R1.2, R2.1, U2.4 (DIV)
unnamed: R3.1, U2.3 (SET)

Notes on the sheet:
200ms delay
LTC6994IS6-1
This source describes Open Hardware and is licensed under the CERN-OHL-W v2 or later. You may redistribute and modify this documentation and make products using it under the terms of the CERN-OHL-W v2 (https:/cern.ch/cern-ohl). This documentation is distributed WITHOUT ANY EXPRESS OR IMPLIED WARRAN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
Power supply

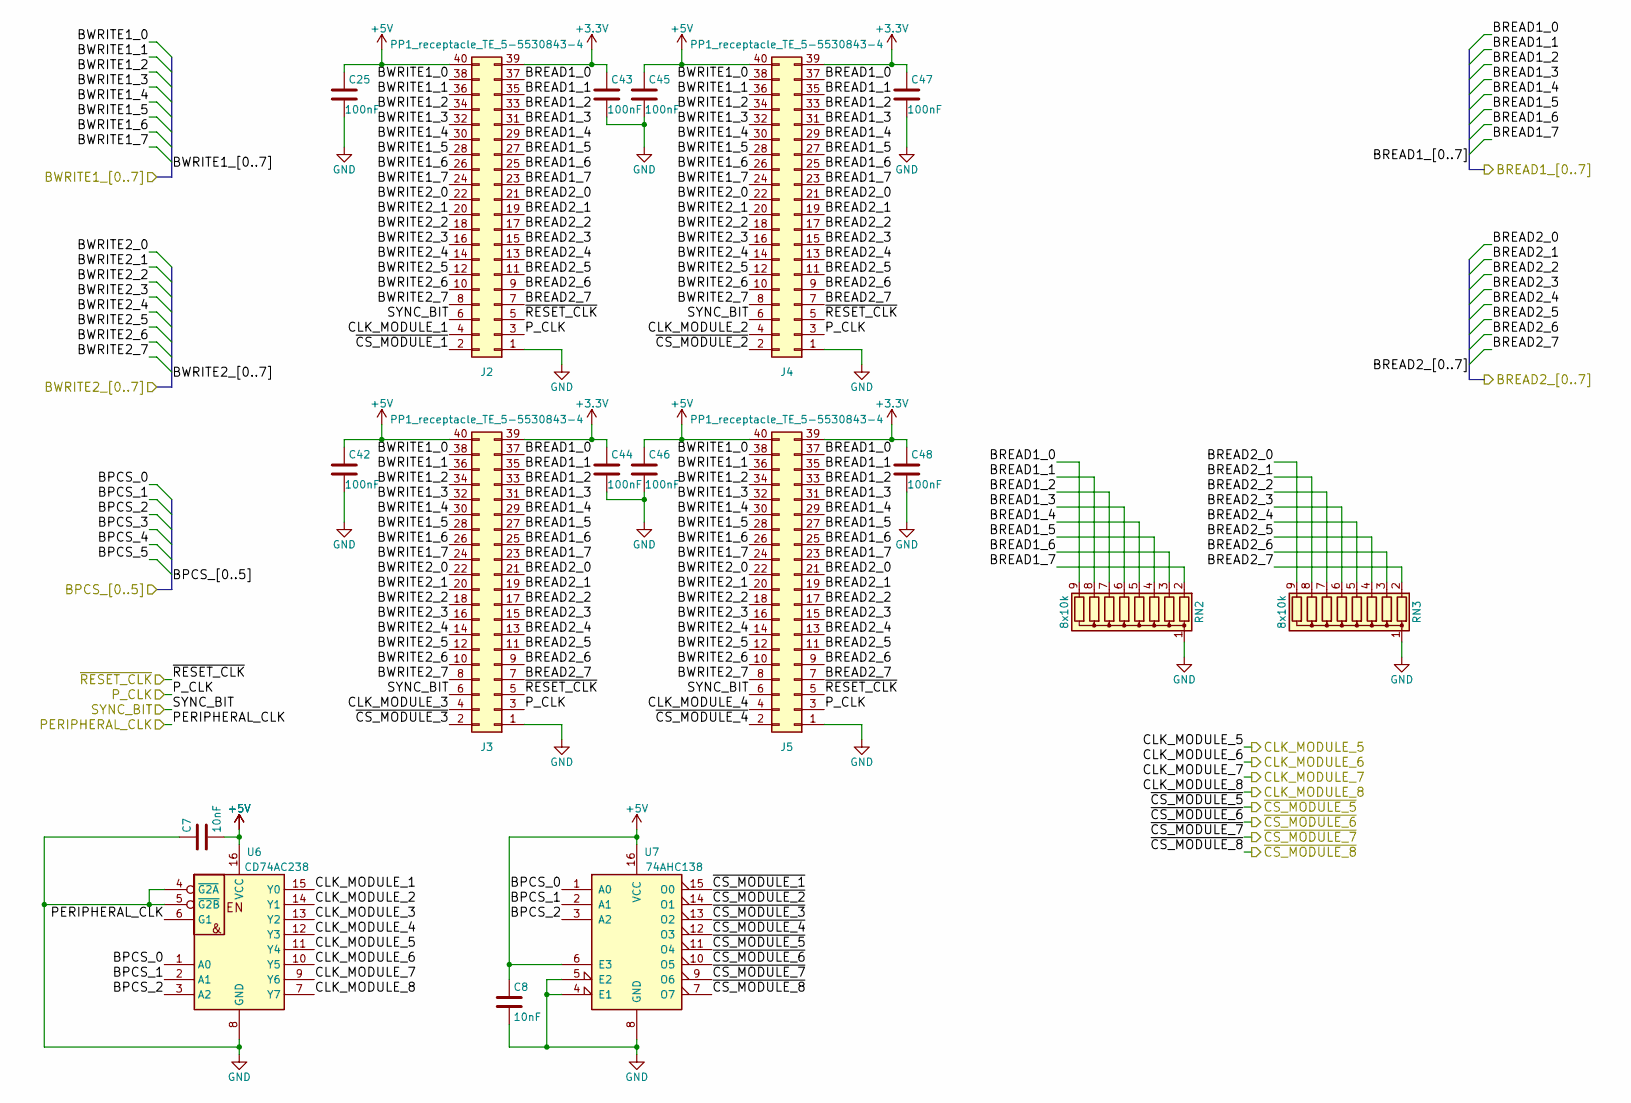
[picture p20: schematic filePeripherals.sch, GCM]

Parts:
C7, C8: 10nF; C_0805_2012Metric
C25, C42, C43, C44, C45, C46, C47, C48: 100nF; C_0805_2012Metric
J2, J3, J4, J5: PP1_receptacle_TE_5-5530843-4; TE_5-5530843-4
RN2, RN3: 8x10k; R_Array_SIP9
U6: CD74AC238; SOP-16_3.9x9.9mm_P1.27mm
U7: 74AHC138; SOIC-16W_5.3x10.2mm_P1.27mm

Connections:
+5V: C7.2, C8.1, C25.1, C42.1, C45.1, C46.1, J2.40, J3.40, J4.40, J5.40, U6.16 (VCC), U7.6 (E3), U7.16 (VCC); also elsewhere on the board
/CLK_MODULE_5: U6.11 (Y4); also elsewhere on the board
/CLK_MODULE_6: U6.10 (Y5); also elsewhere on the board
/CLK_MODULE_7: U6.9 (Y6); also elsewhere on the board
/CLK_MODULE_8: U6.7 (Y7); also elsewhere on the board
/ClockGenerator/BWRITE1_0: J2.38, J3.38, J4.38, J5.38; also elsewhere on the board
/ClockGenerator/BWRITE1_1: J2.36, J3.36, J4.36, J5.36; also elsewhere on the board
/ClockGenerator/BWRITE1_2: J2.34, J3.34, J4.34, J5.34; also elsewhere on the board
/ClockGenerator/BWRITE1_3: J2.32, J3.32, J4.32, J5.32; also elsewhere on the board
/ClockGenerator/BWRITE1_4: J2.30, J3.30, J4.30, J5.30; also elsewhere on the board
/ClockGenerator/BWRITE1_5: J2.28, J3.28, J4.28, J5.28; also elsewhere on the board
/ClockGenerator/BWRITE1_6: J2.26, J3.26, J4.26, J5.26; also elsewhere on the board
/ClockGenerator/BWRITE1_7: J2.24, J3.24, J4.24, J5.24; also elsewhere on the board
/Connector/BPCS_0: U6.1 (A0), U7.1 (A0); also elsewhere on the board
/Connector/BPCS_1: U6.2 (A1), U7.2 (A1); also elsewhere on the board
/Connector/BPCS_2: U6.3 (A2), U7.3 (A2); also elsewhere on the board
/Connector/BREAD1_0: J2.37, J3.37, J4.37, J5.37, RN2.9 (R8); also elsewhere on the board
/Connector/BREAD1_1: J2.35, J3.35, J4.35, J5.35, RN2.8 (R7); also elsewhere on the board
/Connector/BREAD1_2: J2.33, J3.33, J4.33, J5.33, RN2.7 (R6); also elsewhere on the board
/Connector/BREAD1_3: J2.31, J3.31, J4.31, J5.31, RN2.6 (R5); also elsewhere on the board
/Connector/BREAD1_4: J2.29, J3.29, J4.29, J5.29, RN2.5 (R4); also elsewhere on the board
/Connector/BREAD1_5: J2.27, J3.27, J4.27, J5.27, RN2.4 (R3); also elsewhere on the board
/Connector/BREAD1_6: J2.25, J3.25, J4.25, J5.25, RN2.3 (R2); also elsewhere on the board
/Connector/BREAD1_7: J2.23, J3.23, J4.23, J5.23, RN2.2 (R1); also elsewhere on the board
/Connector/BREAD2_0: J2.21, J3.21, J4.21, J5.21, RN3.9 (R8); also elsewhere on the board
/Connector/BREAD2_1: J2.19, J3.19, J4.19, J5.19, RN3.8 (R7); also elsewhere on the board
/Connector/BREAD2_2: J2.17, J3.17, J4.17, J5.17, RN3.7 (R6); also elsewhere on the board
/Connector/BREAD2_3: J2.15, J3.15, J4.15, J5.15, RN3.6 (R5); also elsewhere on the board
/Connector/BREAD2_4: J2.13, J3.13, J4.13, J5.13, RN3.5 (R4); also elsewhere on the board
/Connector/BREAD2_5: J2.11, J3.11, J4.11, J5.11, RN3.4 (R3); also elsewhere on the board
/Connector/BREAD2_6: J2.9, J3.9, J4.9, J5.9, RN3.3 (R2); also elsewhere on the board
/Connector/BREAD2_7: J2.7, J3.7, J4.7, J5.7, RN3.2 (R1); also elsewhere on the board
/Connector/BWRITE2_0: J2.22, J3.22, J4.22, J5.22; also elsewhere on the board
/Connector/BWRITE2_1: J2.20, J3.20, J4.20, J5.20; also elsewhere on the board
/Connector/BWRITE2_2: J2.18, J3.18, J4.18, J5.18; also elsewhere on the board
/Connector/BWRITE2_3: J2.16, J3.16, J4.16, J5.16; also elsewhere on the board
/Connector/BWRITE2_4: J2.14, J3.14, J4.14, J5.14; also elsewhere on the board
/Connector/BWRITE2_5: J2.12, J3.12, J4.12, J5.12; also elsewhere on the board
/Connector/BWRITE2_6: J2.10, J3.10, J4.10, J5.10; also elsewhere on the board
/Connector/BWRITE2_7: J2.8, J3.8, J4.8, J5.8; also elsewhere on the board
/PERIPHERAL_CLK: U6.6 (G1); also elsewhere on the board
/P_CLK: J2.3, J3.3, J4.3, J5.3; also elsewhere on the board
/Peripherals/CLK_MODULE_1: J2.4, U6.15 (Y0)
/Peripherals/CLK_MODULE_2: J4.4, U6.14 (Y1)
/Peripherals/CLK_MODULE_3: J3.4, U6.13 (Y2)
/Peripherals/CLK_MODULE_4: J5.4, U6.12 (Y3)
/Peripherals/~CS_MODULE_1: J2.2, U7.15 (O0)
/Peripherals/~CS_MODULE_2: J4.2, U7.14 (O1)
/Peripherals/~CS_MODULE_3: J3.2, U7.13 (O2)
/Peripherals/~CS_MODULE_4: J5.2, U7.12 (O3)
/SYNC_BIT: J2.6, J3.6, J4.6, J5.6; also elsewhere on the board
/~CS_MODULE_5: U7.11 (O4); also elsewhere on the board
/~CS_MODULE_6: U7.10 (O5)
/~CS_MODULE_7: U7.9 (O6)
/~CS_MODULE_8: U7.7 (O7)
/~GLOBAL_RESET: J2.5, J3.5, J4.5, J5.5; also elsewhere on the board
GND: C7.1, C8.2, C25.2, C42.2, C43.2, C44.2, C45.2, C46.2, C47.2, C48.2, J2.1, J3.1, J4.1, J5.1, RN2.1 (common), RN3.1 (common), U6.4 (~G2A), U6.5 (~G2B), U6.8 (GND), U7.4 (E1), U7.5 (E2), U7.8 (GND); also elsewhere on the board

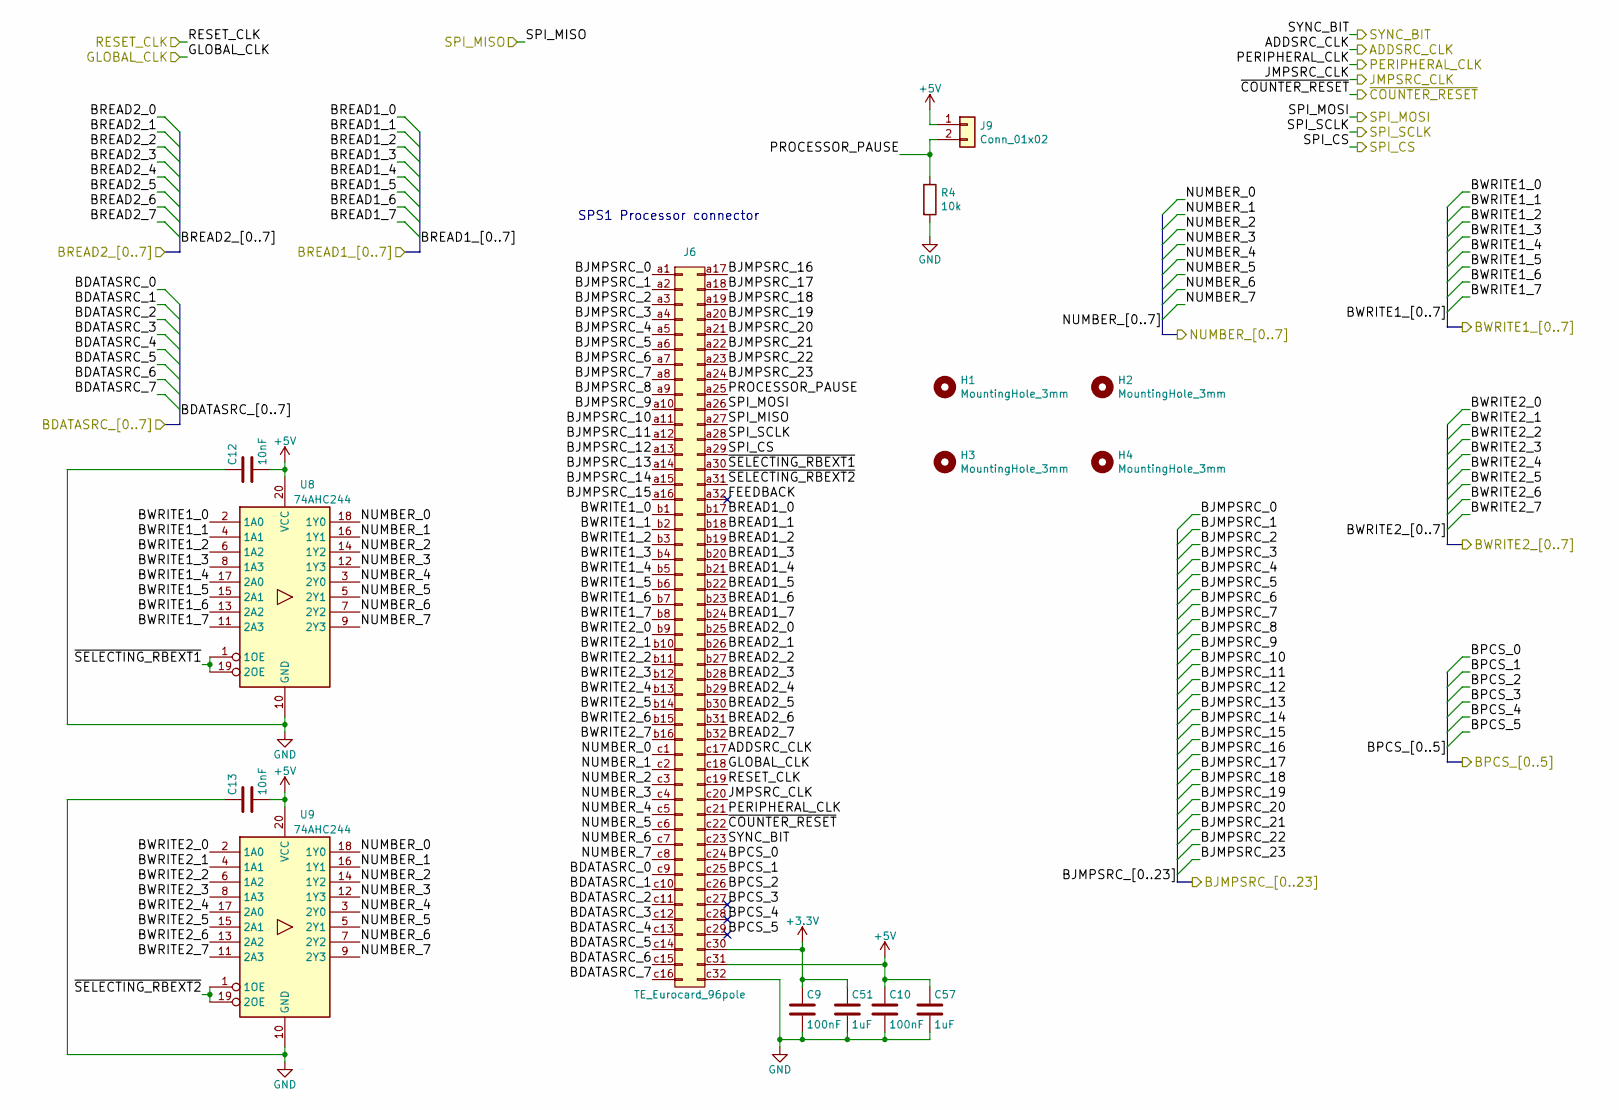
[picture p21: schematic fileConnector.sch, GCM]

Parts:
C9, C10: 100nF; C_0805_2012Metric
C12, C13: 10nF; C_0805_2012Metric
C51, C57: 1uF; C_0805_2012Metric
H1, H2, H3, H4: MountingHole_3mm
J6: TE_Eurocard_96pole; Eurocard_5536475-1_Inv
J9: Conn_01x02; PinHeader_1x02_P2.54mm_Vertical
R4: 10k; R_0805_2012Metric
U8, U9: 74AHC244; SOIC-20W_7.5x12.8mm_P1.27mm

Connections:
+5V: C10.1, C12.2, C13.2, C57.1, J6.c31, J9.1, U8.20 (VCC), U9.20 (VCC); also elsewhere on the board
/ADDSRC_CLK: J6.c17; also elsewhere on the board
/AddressCounter/BJMPSRC_0: J6.a1; also elsewhere on the board
/AddressCounter/BJMPSRC_1: J6.a2; also elsewhere on the board
/AddressCounter/BJMPSRC_2: J6.a3; also elsewhere on the board
/AddressCounter/BJMPSRC_3: J6.a4; also elsewhere on the board
/AddressCounter/BJMPSRC_4: J6.a5; also elsewhere on the board
/AddressCounter/BJMPSRC_5: J6.a6; also elsewhere on the board
/AddressCounter/BJMPSRC_6: J6.a7; also elsewhere on the board
/AddressCounter/BJMPSRC_7: J6.a8; also elsewhere on the board
/AddressCounter/BJMPSRC_8: J6.a9; also elsewhere on the board
/AddressCounter/BJMPSRC_9: J6.a10; also elsewhere on the board
/AddressCounter/BJMPSRC_10: J6.a11; also elsewhere on the board
/AddressCounter/BJMPSRC_11: J6.a12; also elsewhere on the board
/AddressCounter/BJMPSRC_12: J6.a13; also elsewhere on the board
/AddressCounter/BJMPSRC_13: J6.a14; also elsewhere on the board
/AddressCounter/BJMPSRC_14: J6.a15; also elsewhere on the board
/AddressCounter/BJMPSRC_15: J6.a16; also elsewhere on the board
/AddressCounter/BJMPSRC_16: J6.a17; also elsewhere on the board
/AddressCounter/BJMPSRC_17: J6.a18; also elsewhere on the board
/AddressCounter/BJMPSRC_18: J6.a19; also elsewhere on the board
/AddressCounter/BJMPSRC_19: J6.a20; also elsewhere on the board
/AddressCounter/BJMPSRC_20: J6.a21; also elsewhere on the board
/AddressCounter/BJMPSRC_21: J6.a22; also elsewhere on the board
/AddressCounter/BJMPSRC_22: J6.a23; also elsewhere on the board
/AddressCounter/BJMPSRC_23: J6.a24; also elsewhere on the board
/BDATASRC_0: J6.c9; also elsewhere on the board
/BDATASRC_1: J6.c10; also elsewhere on the board
/BDATASRC_2: J6.c11; also elsewhere on the board
/BDATASRC_3: J6.c12; also elsewhere on the board
/BDATASRC_4: J6.c13; also elsewhere on the board
/BDATASRC_5: J6.c14; also elsewhere on the board
/BDATASRC_6: J6.c15; also elsewhere on the board
/BDATASRC_7: J6.c16; also elsewhere on the board
/ClockGenerator/BWRITE1_0: J6.b1, U8.2 (1A0); also elsewhere on the board
/ClockGenerator/BWRITE1_1: J6.b2, U8.4 (1A1); also elsewhere on the board
/ClockGenerator/BWRITE1_2: J6.b3, U8.6 (1A2); also elsewhere on the board
/ClockGenerator/BWRITE1_3: J6.b4, U8.8 (1A3); also elsewhere on the board
/ClockGenerator/BWRITE1_4: J6.b5, U8.17 (2A0); also elsewhere on the board
/ClockGenerator/BWRITE1_5: J6.b6, U8.15 (2A1); also elsewhere on the board
/ClockGenerator/BWRITE1_6: J6.b7, U8.13 (2A2); also elsewhere on the board
/ClockGenerator/BWRITE1_7: J6.b8, U8.11 (2A3); also elsewhere on the board
/Connector/BPCS_0: J6.c24; also elsewhere on the board
/Connector/BPCS_1: J6.c25; also elsewhere on the board
/Connector/BPCS_2: J6.c26; also elsewhere on the board
/Connector/BPCS_3: J6.c27
/Connector/BPCS_4: J6.c28
/Connector/BPCS_5: J6.c29
/Connector/BREAD1_0: J6.b17; also elsewhere on the board
/Connector/BREAD1_1: J6.b18; also elsewhere on the board
/Connector/BREAD1_2: J6.b19; also elsewhere on the board
/Connector/BREAD1_3: J6.b20; also elsewhere on the board
/Connector/BREAD1_4: J6.b21; also elsewhere on the board
/Connector/BREAD1_5: J6.b22; also elsewhere on the board
/Connector/BREAD1_6: J6.b23; also elsewhere on the board
/Connector/BREAD1_7: J6.b24; also elsewhere on the board
/Connector/BREAD2_0: J6.b25; also elsewhere on the board
/Connector/BREAD2_1: J6.b26; also elsewhere on the board
/Connector/BREAD2_2: J6.b27; also elsewhere on the board
/Connector/BREAD2_3: J6.b28; also elsewhere on the board
/Connector/BREAD2_4: J6.b29; also elsewhere on the board
/Connector/BREAD2_5: J6.b30; also elsewhere on the board
/Connector/BREAD2_6: J6.b31; also elsewhere on the board
/Connector/BREAD2_7: J6.b32; also elsewhere on the board
/Connector/BWRITE2_0: J6.b9, U9.2 (1A0); also elsewhere on the board
/Connector/BWRITE2_1: J6.b10, U9.4 (1A1); also elsewhere on the board
/Connector/BWRITE2_2: J6.b11, U9.6 (1A2); also elsewhere on the board
/Connector/BWRITE2_3: J6.b12, U9.8 (1A3); also elsewhere on the board
/Connector/BWRITE2_4: J6.b13, U9.17 (2A0); also elsewhere on the board
/Connector/BWRITE2_5: J6.b14, U9.15 (2A1); also elsewhere on the board
/Connector/BWRITE2_6: J6.b15, U9.13 (2A2); also elsewhere on the board
/Connector/BWRITE2_7: J6.b16, U9.11 (2A3); also elsewhere on the board
/Connector/FEEDBACK: J6.a32
/Connector/PROCESSOR_PAUSE: J6.a25, J9.2, R4.1
/Connector/~SELECTING_RBEXT1: J6.a30, U8.1 (1OE), U8.19 (2OE)
/Connector/~SELECTING_RBEXT2: J6.a31, U9.1 (1OE), U9.19 (2OE)
/GLOBAL_CLK: J6.c18; also elsewhere on the board
/GLOBAL_RESET: J6.c19; also elsewhere on the board
/JMPSRC_CLK: J6.c20; also elsewhere on the board
/NUMBER_0: J6.c1, U8.18 (1Y0), U9.18 (1Y0); also elsewhere on the board
/NUMBER_1: J6.c2, U8.16 (1Y1), U9.16 (1Y1); also elsewhere on the board
/NUMBER_2: J6.c3, U8.14 (1Y2), U9.14 (1Y2); also elsewhere on the board
/NUMBER_3: J6.c4, U8.12 (1Y3), U9.12 (1Y3); also elsewhere on the board
/NUMBER_4: J6.c5, U8.3 (2Y0), U9.3 (2Y0); also elsewhere on the board
/NUMBER_5: J6.c6, U8.5 (2Y1), U9.5 (2Y1); also elsewhere on the board
/NUMBER_6: J6.c7, U8.7 (2Y2), U9.7 (2Y2); also elsewhere on the board
/NUMBER_7: J6.c8, U8.9 (2Y3), U9.9 (2Y3); also elsewhere on the board
/PERIPHERAL_CLK: J6.c21; also elsewhere on the board
/SPI_CS: J6.a29; also elsewhere on the board
/SPI_MISO: J6.a27; also elsewhere on the board
/SPI_MOSI: J6.a26; also elsewhere on the board
/SPI_SCLK: J6.a28; also elsewhere on the board
/SYNC_BIT: J6.c23; also elsewhere on the board
/~COUNTER_RESET: J6.c22
GND: C9.2, C10.2, C12.1, C13.1, C51.2, C57.2, J6.c32, R4.2, U8.10 (GND), U9.10 (GND); also elsewhere on the board

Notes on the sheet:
SPS1 Processor connector

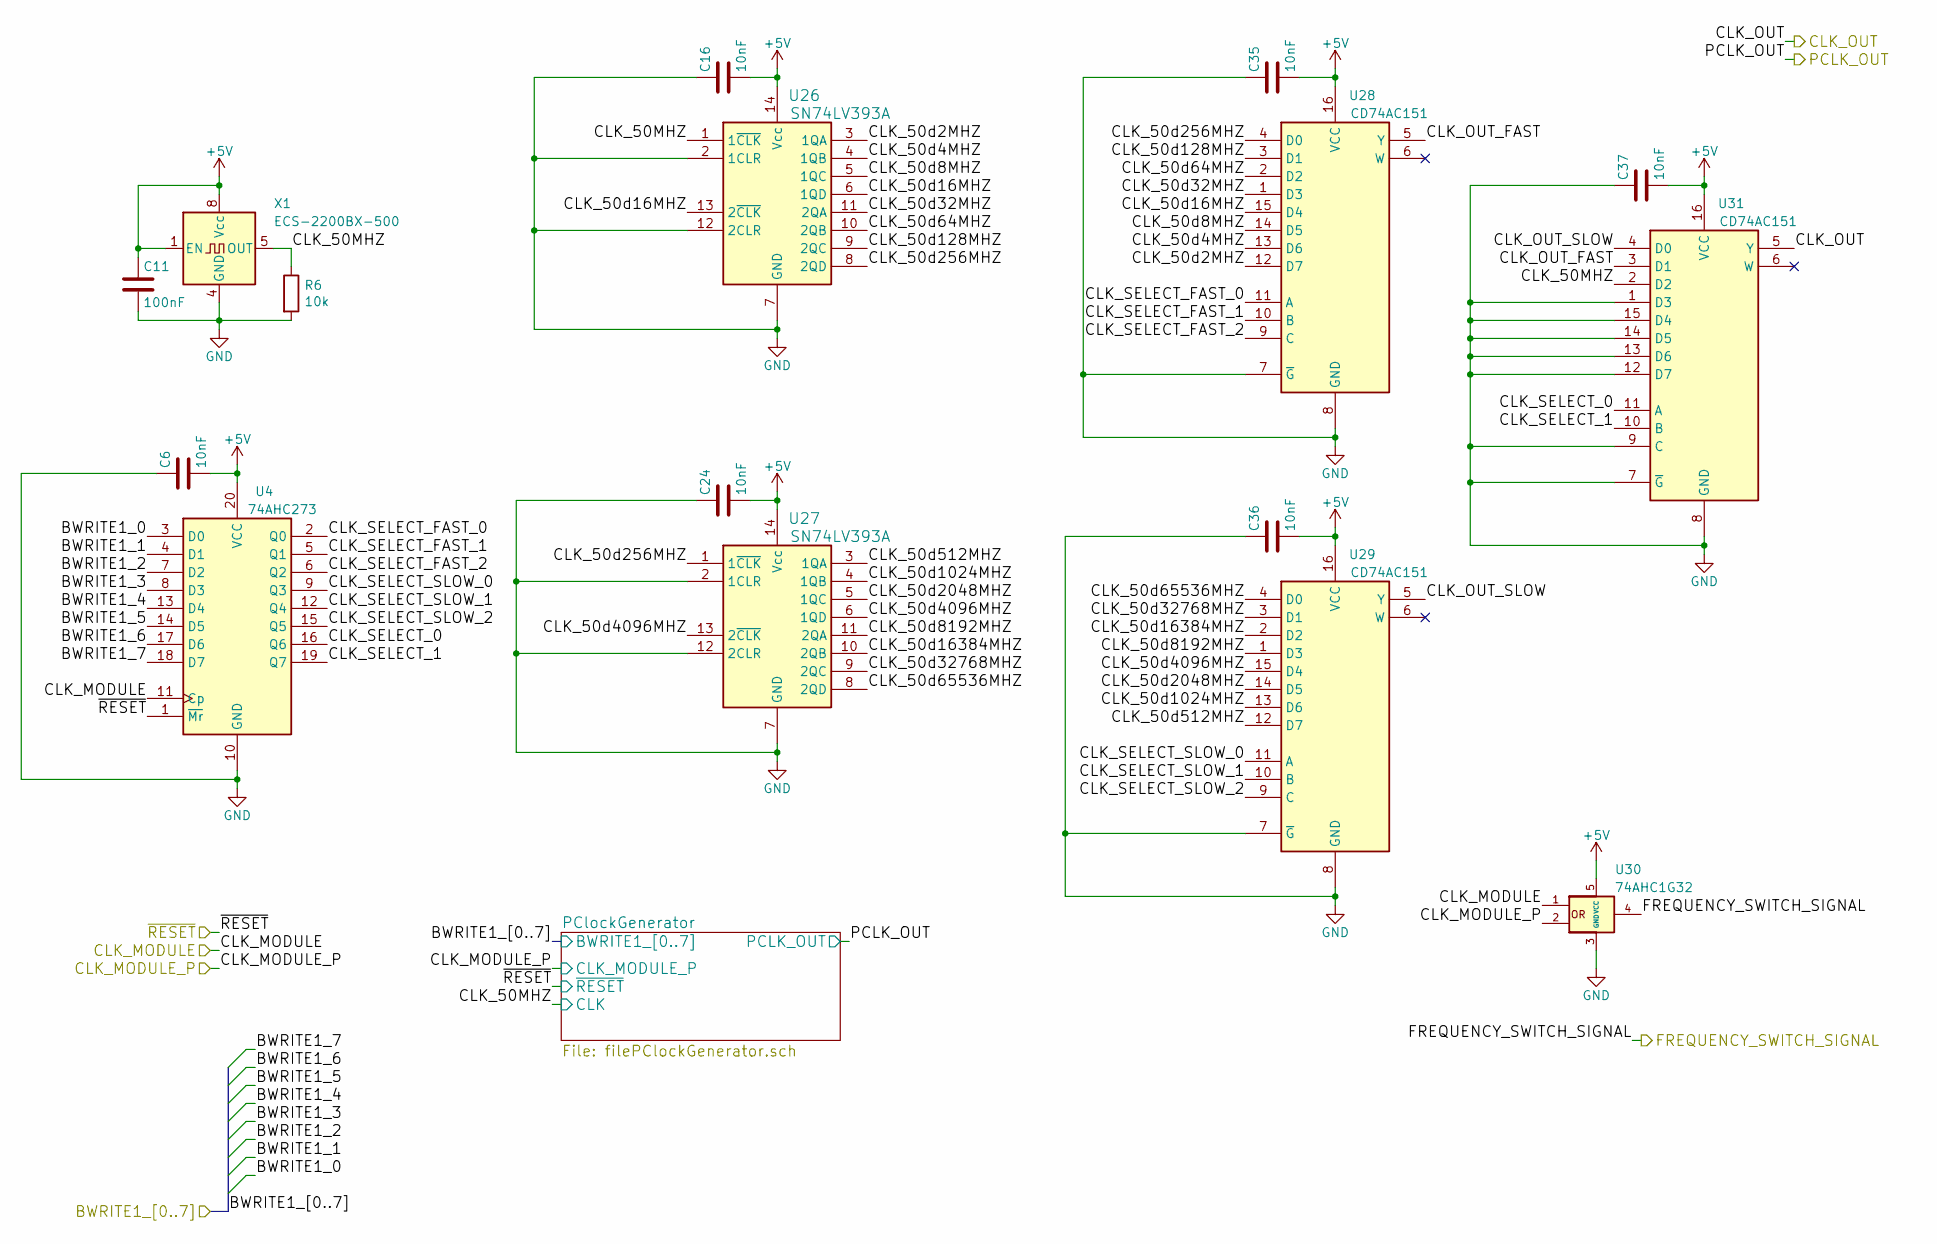
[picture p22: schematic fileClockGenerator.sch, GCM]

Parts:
C6, C16, C24, C35, C36, C37: 10nF; C_0805_2012Metric
C11: 100nF; C_0805_2012Metric
R6: 10k; R_0805_2012Metric
U4: 74AHC273; SOIC-20W_7.5x12.8mm_P1.27mm
U26, U27: SN74LV393A; SOIC-14_3.9x8.7mm_P1.27mm
U28, U29, U31: CD74AC151; SOP-16_3.9x9.9mm_P1.27mm
U30: 74AHC1G32; SOT-23-5
X1: ECS-2200BX-500; Oscillator_DIP-8

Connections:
+5V: C6.2, C11.1, C16.2, C24.2, C35.2, C36.2, C37.2, U4.20 (VCC), U26.14 (Vcc), U27.14 (Vcc), U28.16 (VCC), U29.16 (VCC), U30.5 (VCC), U31.16 (VCC), X1.1 (EN), X1.8 (Vcc); also elsewhere on the board
/CLK_MODULE_7: U4.11 (Cp), U30.1; also elsewhere on the board
/CLK_MODULE_8: U30.2; also elsewhere on the board
/ClockGenerator/BWRITE1_0: U4.3 (D0); also elsewhere on the board
/ClockGenerator/BWRITE1_1: U4.4 (D1); also elsewhere on the board
/ClockGenerator/BWRITE1_2: U4.7 (D2); also elsewhere on the board
/ClockGenerator/BWRITE1_3: U4.8 (D3); also elsewhere on the board
/ClockGenerator/BWRITE1_4: U4.13 (D4); also elsewhere on the board
/ClockGenerator/BWRITE1_5: U4.14 (D5); also elsewhere on the board
/ClockGenerator/BWRITE1_6: U4.17 (D6); also elsewhere on the board
/ClockGenerator/BWRITE1_7: U4.18 (D7); also elsewhere on the board
/ClockGenerator/CLK_50MHZ: R6.1, U26.1 (1~CLK), U31.2 (D2), X1.5 (OUT); also elsewhere on the board
/ClockGenerator/CLK_50d2MHZ: U26.3 (1QA), U28.12 (D7)
/ClockGenerator/CLK_50d4MHZ: U26.4 (1QB), U28.13 (D6)
/ClockGenerator/CLK_50d8MHZ: U26.5 (1QC), U28.14 (D5)
/ClockGenerator/CLK_50d16MHZ: U26.6 (1QD), U26.13 (2~CLK), U28.15 (D4)
/ClockGenerator/CLK_50d32MHZ: U26.11 (2QA), U28.1 (D3)
/ClockGenerator/CLK_50d64MHZ: U26.10 (2QB), U28.2 (D2)
/ClockGenerator/CLK_50d128MHZ: U26.9 (2QC), U28.3 (D1)
/ClockGenerator/CLK_50d256MHZ: U26.8 (2QD), U27.1 (1~CLK), U28.4 (D0)
/ClockGenerator/CLK_50d512MHZ: U27.3 (1QA), U29.12 (D7)
/ClockGenerator/CLK_50d1024MHZ: U27.4 (1QB), U29.13 (D6)
/ClockGenerator/CLK_50d2048MHZ: U27.5 (1QC), U29.14 (D5)
/ClockGenerator/CLK_50d4096MHZ: U27.6 (1QD), U27.13 (2~CLK), U29.15 (D4)
/ClockGenerator/CLK_50d8192MHZ: U27.11 (2QA), U29.1 (D3)
/ClockGenerator/CLK_50d16384MHZ: U27.10 (2QB), U29.2 (D2)
/ClockGenerator/CLK_50d32768MHZ: U27.9 (2QC), U29.3 (D1)
/ClockGenerator/CLK_50d65536MHZ: U27.8 (2QD), U29.4 (D0)
/ClockGenerator/CLK_OUT_FAST: U28.5 (Y), U31.3 (D1)
/ClockGenerator/CLK_OUT_SLOW: U29.5 (Y), U31.4 (D0)
/ClockGenerator/CLK_SELECT_0: U4.16 (Q6), U31.11 (A)
/ClockGenerator/CLK_SELECT_1: U4.19 (Q7), U31.10 (B)
/ClockGenerator/CLK_SELECT_FAST_0: U4.2 (Q0), U28.11 (A)
/ClockGenerator/CLK_SELECT_FAST_1: U4.5 (Q1), U28.10 (B)
/ClockGenerator/CLK_SELECT_FAST_2: U4.6 (Q2), U28.9 (C)
/ClockGenerator/CLK_SELECT_SLOW_0: U4.9 (Q3), U29.11 (A)
/ClockGenerator/CLK_SELECT_SLOW_1: U4.12 (Q4), U29.10 (B)
/ClockGenerator/CLK_SELECT_SLOW_2: U4.15 (Q5), U29.9 (C)
/FREQUENCY_SWITCH_SIGNAL: U30.4; also elsewhere on the board
/GLOBAL_CLK: U31.5 (Y); also elsewhere on the board
/~POWER_RESET: U4.1 (~Mr); also elsewhere on the board
GND: C6.1, C11.2, C16.1, C24.1, C35.1, C36.1, C37.1, R6.2, U4.10 (GND), U26.2 (1CLR), U26.7 (GND), U26.12 (2CLR), U27.2 (1CLR), U27.7 (GND), U27.12 (2CLR), U28.7 (~G), U28.8 (GND), U29.7 (~G), U29.8 (GND), U30.3 (GND), U31.1 (D3), U31.7 (~G), U31.8 (GND), U31.9 (C), U31.12 (D7), U31.13 (D6), U31.14 (D5), U31.15 (D4), X1.4 (GND); also elsewhere on the board

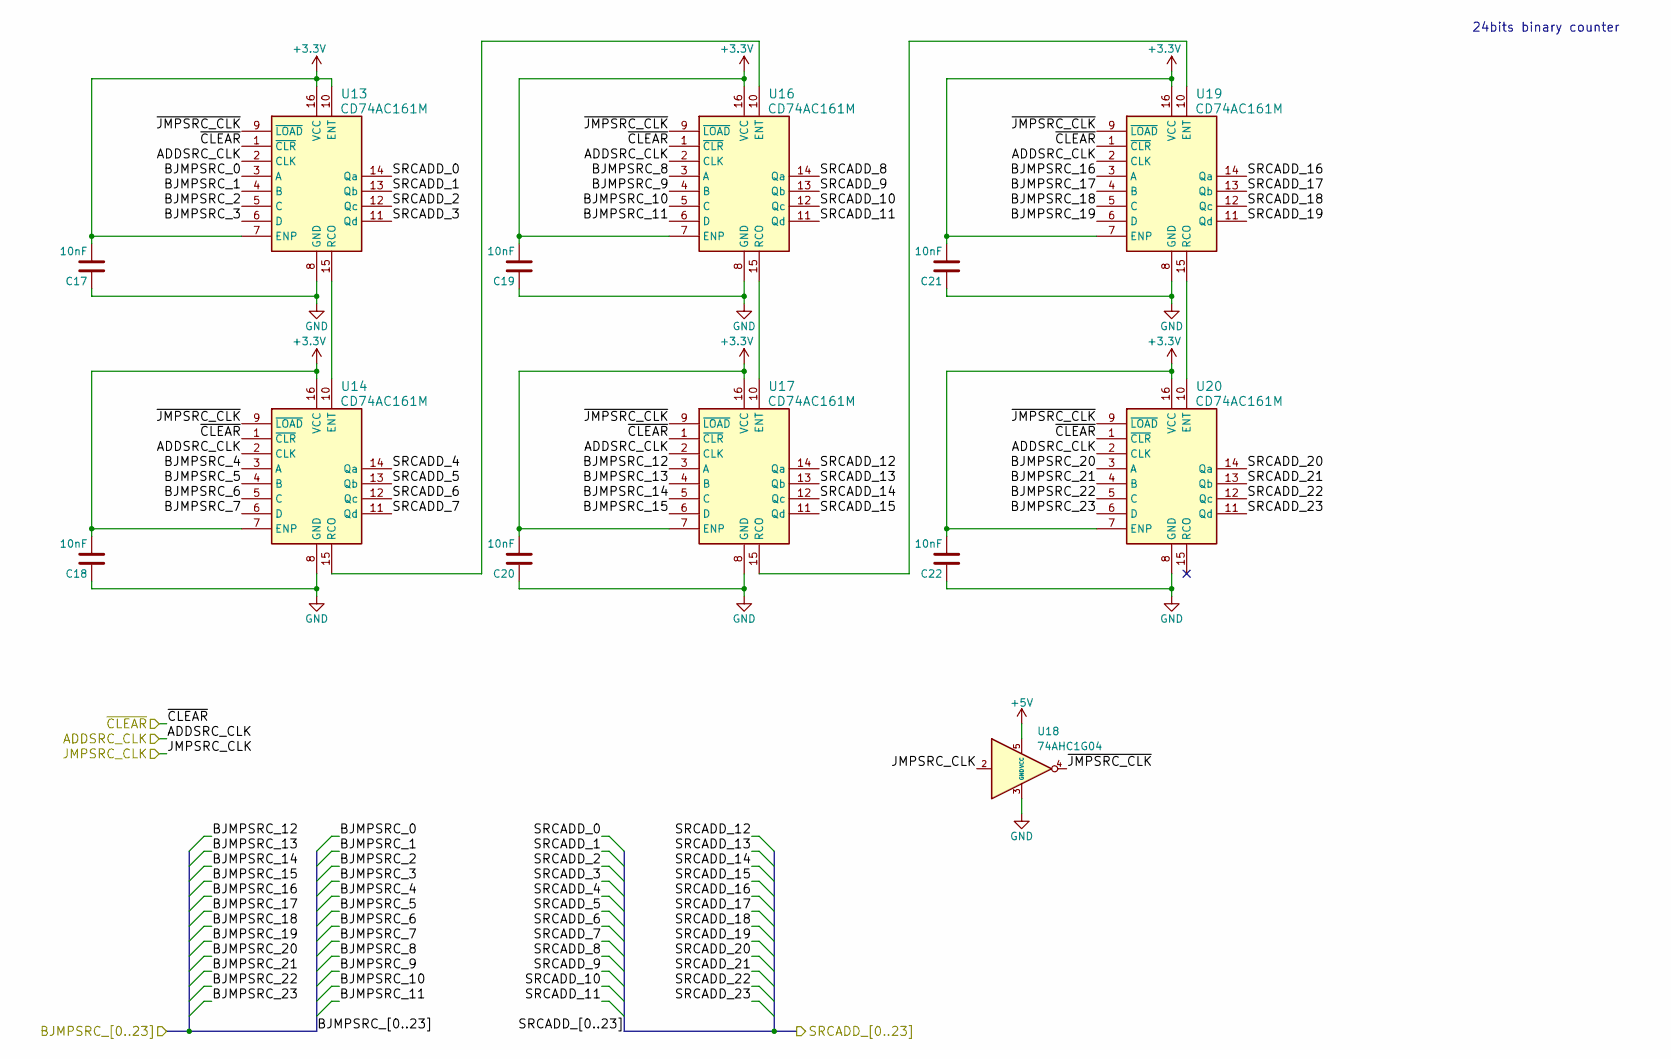
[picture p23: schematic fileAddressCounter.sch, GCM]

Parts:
C17, C18, C19, C20, C21, C22: 10nF; C_0805_2012Metric
U13, U14, U16, U17, U19, U20: CD74AC161M; SOP-16_3.9x9.9mm_P1.27mm
U18: 74AHC1G04; SOT-23-5

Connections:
+5V: U18.5 (VCC); also elsewhere on the board
/ADDSRC_CLK: U13.2 (CLK), U14.2 (CLK), U16.2 (CLK), U17.2 (CLK), U19.2 (CLK), U20.2 (CLK); also elsewhere on the board
/AddressCounter/BJMPSRC_0: U13.3 (A); also elsewhere on the board
/AddressCounter/BJMPSRC_1: U13.4 (B); also elsewhere on the board
/AddressCounter/BJMPSRC_2: U13.5 (C); also elsewhere on the board
/AddressCounter/BJMPSRC_3: U13.6 (D); also elsewhere on the board
/AddressCounter/BJMPSRC_4: U14.3 (A); also elsewhere on the board
/AddressCounter/BJMPSRC_5: U14.4 (B); also elsewhere on the board
/AddressCounter/BJMPSRC_6: U14.5 (C); also elsewhere on the board
/AddressCounter/BJMPSRC_7: U14.6 (D); also elsewhere on the board
/AddressCounter/BJMPSRC_8: U16.3 (A); also elsewhere on the board
/AddressCounter/BJMPSRC_9: U16.4 (B); also elsewhere on the board
/AddressCounter/BJMPSRC_10: U16.5 (C); also elsewhere on the board
/AddressCounter/BJMPSRC_11: U16.6 (D); also elsewhere on the board
/AddressCounter/BJMPSRC_12: U17.3 (A); also elsewhere on the board
/AddressCounter/BJMPSRC_13: U17.4 (B); also elsewhere on the board
/AddressCounter/BJMPSRC_14: U17.5 (C); also elsewhere on the board
/AddressCounter/BJMPSRC_15: U17.6 (D); also elsewhere on the board
/AddressCounter/BJMPSRC_16: U19.3 (A); also elsewhere on the board
/AddressCounter/BJMPSRC_17: U19.4 (B); also elsewhere on the board
/AddressCounter/BJMPSRC_18: U19.5 (C); also elsewhere on the board
/AddressCounter/BJMPSRC_19: U19.6 (D); also elsewhere on the board
/AddressCounter/BJMPSRC_20: U20.3 (A); also elsewhere on the board
/AddressCounter/BJMPSRC_21: U20.4 (B); also elsewhere on the board
/AddressCounter/BJMPSRC_22: U20.5 (C); also elsewhere on the board
/AddressCounter/BJMPSRC_23: U20.6 (D); also elsewhere on the board
/AddressCounter/~JMPSRC_CLK: U13.9 (~LOAD), U14.9 (~LOAD), U16.9 (~LOAD), U17.9 (~LOAD), U18.4, U19.9 (~LOAD), U20.9 (~LOAD)
/JMPSRC_CLK: U18.2; also elsewhere on the board
/SRCADD_0: U13.14 (Qa); also elsewhere on the board
/SRCADD_1: U13.13 (Qb); also elsewhere on the board
/SRCADD_2: U13.12 (Qc); also elsewhere on the board
/SRCADD_3: U13.11 (Qd); also elsewhere on the board
/SRCADD_4: U14.14 (Qa); also elsewhere on the board
/SRCADD_5: U14.13 (Qb); also elsewhere on the board
/SRCADD_6: U14.12 (Qc); also elsewhere on the board
/SRCADD_7: U14.11 (Qd); also elsewhere on the board
/SRCADD_8: U16.14 (Qa); also elsewhere on the board
/SRCADD_9: U16.13 (Qb); also elsewhere on the board
/SRCADD_10: U16.12 (Qc); also elsewhere on the board
/SRCADD_11: U16.11 (Qd); also elsewhere on the board
/SRCADD_12: U17.14 (Qa); also elsewhere on the board
/SRCADD_13: U17.13 (Qb); also elsewhere on the board
/SRCADD_14: U17.12 (Qc); also elsewhere on the board
/SRCADD_15: U17.11 (Qd); also elsewhere on the board
/SRCADD_16: U19.14 (Qa); also elsewhere on the board
/SRCADD_17: U19.13 (Qb); also elsewhere on the board
/SRCADD_18: U19.12 (Qc); also elsewhere on the board
/SRCADD_19: U19.11 (Qd); also elsewhere on the board
/SRCADD_20: U20.14 (Qa); also elsewhere on the board
/SRCADD_21: U20.13 (Qb); also elsewhere on the board
/SRCADD_22: U20.12 (Qc); also elsewhere on the board
/SRCADD_23: U20.11 (Qd); also elsewhere on the board
/~GLOBAL_RESET: U13.1 (~CLR), U14.1 (~CLR), U16.1 (~CLR), U17.1 (~CLR), U19.1 (~CLR), U20.1 (~CLR); also elsewhere on the board
GND: C17.1, C18.1, C19.1, C20.1, C21.1, C22.1, U13.8 (GND), U14.8 (GND), U16.8 (GND), U17.8 (GND), U18.3 (GND), U19.8 (GND), U20.8 (GND); also elsewhere on the board
unnamed: U13.15 (RCO), U14.10 (ENT)
unnamed: U14.15 (RCO), U16.10 (ENT)
unnamed: U16.15 (RCO), U17.10 (ENT)
unnamed: U17.15 (RCO), U19.10 (ENT)
unnamed: U19.15 (RCO), U20.10 (ENT)

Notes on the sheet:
24bits binary counter

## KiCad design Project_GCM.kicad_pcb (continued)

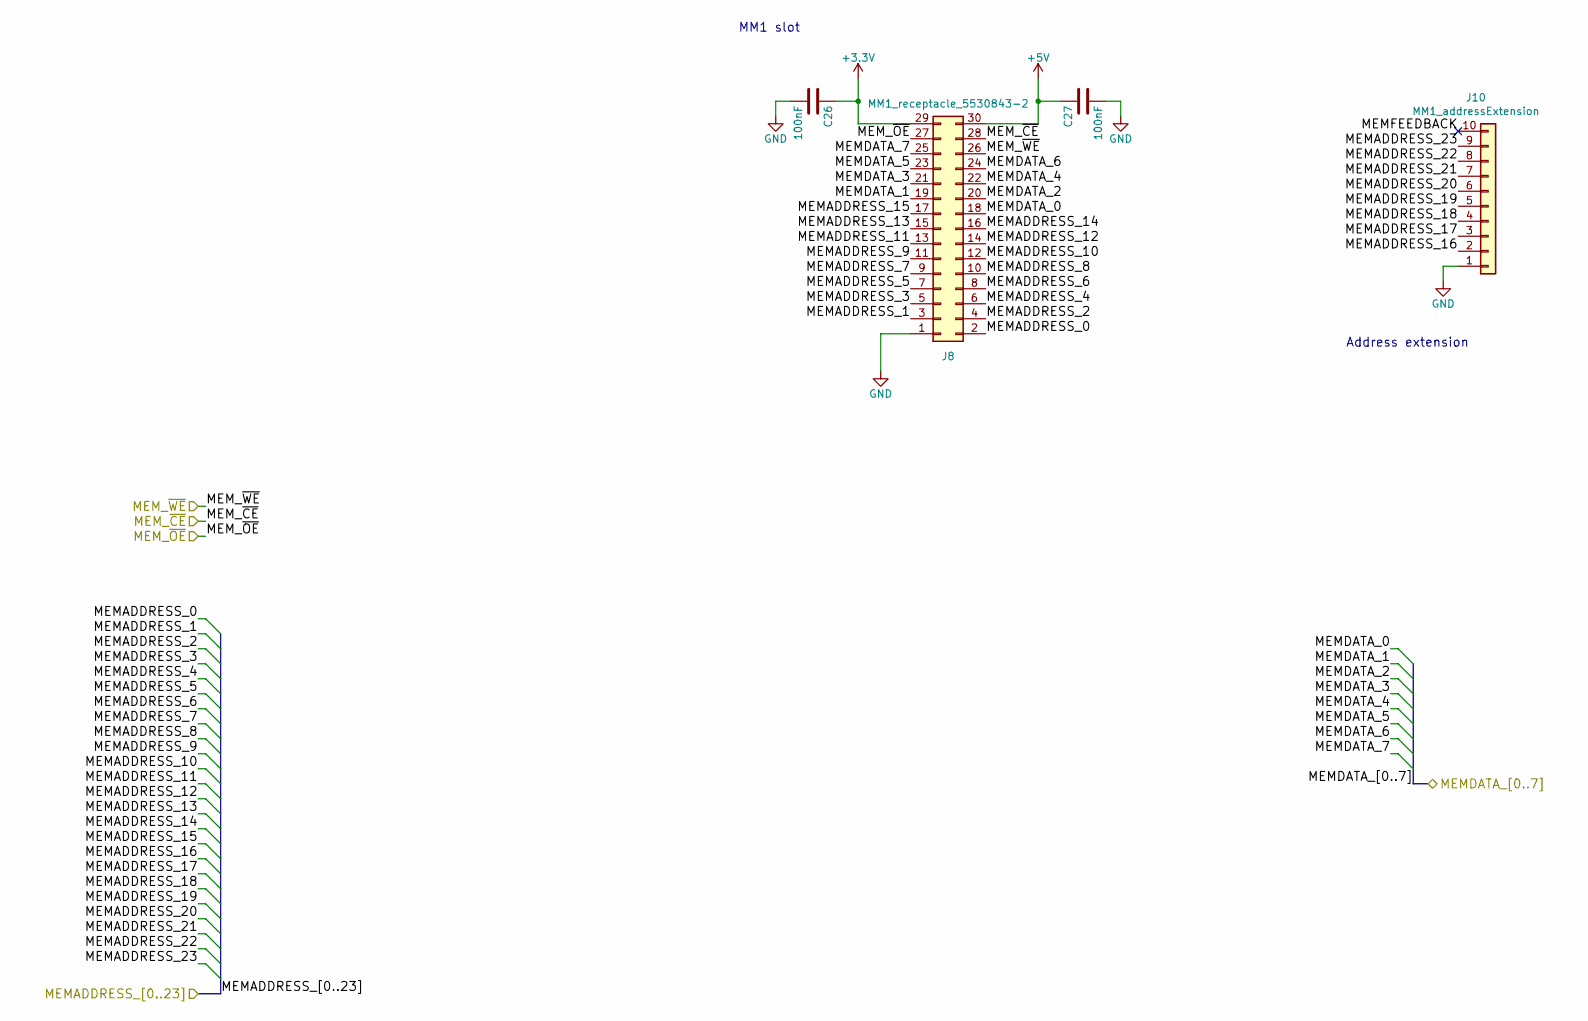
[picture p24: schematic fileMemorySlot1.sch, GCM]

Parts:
C26, C27: 100nF; C_0805_2012Metric
J8: MM1_receptacle_5530843-2; TE_5530843-2
J10: MM1_addressExtension; IDC-Header_2x05_P2.54mm_Vertical

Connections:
+5V: C27.1, J8.30; also elsewhere on the board
/MEM1_~CE: J8.28; also elsewhere on the board
/MEM1_~OE: J8.27; also elsewhere on the board
/MEM1_~WE: J8.26; also elsewhere on the board
/MemoryController/MEM1DATA_0: J8.18; also elsewhere on the board
/MemoryController/MEM1DATA_1: J8.19; also elsewhere on the board
/MemoryController/MEM1DATA_2: J8.20; also elsewhere on the board
/MemoryController/MEM1DATA_3: J8.21; also elsewhere on the board
/MemoryController/MEM1DATA_4: J8.22; also elsewhere on the board
/MemoryController/MEM1DATA_5: J8.23; also elsewhere on the board
/MemoryController/MEM1DATA_6: J8.24; also elsewhere on the board
/MemoryController/MEM1DATA_7: J8.25; also elsewhere on the board
/MemorySlot1/MEMADDRESS_0: J8.2; also elsewhere on the board
/MemorySlot1/MEMADDRESS_1: J8.3; also elsewhere on the board
/MemorySlot1/MEMADDRESS_2: J8.4; also elsewhere on the board
/MemorySlot1/MEMADDRESS_3: J8.5; also elsewhere on the board
/MemorySlot1/MEMADDRESS_4: J8.6; also elsewhere on the board
/MemorySlot1/MEMADDRESS_5: J8.7; also elsewhere on the board
/MemorySlot1/MEMADDRESS_6: J8.8; also elsewhere on the board
/MemorySlot1/MEMADDRESS_7: J8.9; also elsewhere on the board
/MemorySlot1/MEMADDRESS_8: J8.10; also elsewhere on the board
/MemorySlot1/MEMADDRESS_9: J8.11; also elsewhere on the board
/MemorySlot1/MEMADDRESS_10: J8.12; also elsewhere on the board
/MemorySlot1/MEMADDRESS_11: J8.13; also elsewhere on the board
/MemorySlot1/MEMADDRESS_12: J8.14; also elsewhere on the board
/MemorySlot1/MEMADDRESS_13: J8.15; also elsewhere on the board
/MemorySlot1/MEMADDRESS_14: J8.16; also elsewhere on the board
/MemorySlot1/MEMADDRESS_15: J8.17; also elsewhere on the board
/MemorySlot1/MEMADDRESS_16: J10.2; also elsewhere on the board
/MemorySlot1/MEMADDRESS_17: J10.3; also elsewhere on the board
/MemorySlot1/MEMADDRESS_18: J10.4; also elsewhere on the board
/MemorySlot1/MEMADDRESS_19: J10.5; also elsewhere on the board
/MemorySlot1/MEMADDRESS_20: J10.6; also elsewhere on the board
/MemorySlot1/MEMADDRESS_21: J10.7; also elsewhere on the board
/MemorySlot1/MEMADDRESS_22: J10.8; also elsewhere on the board
/MemorySlot1/MEMADDRESS_23: J10.9; also elsewhere on the board
/MemorySlot1/MEMFEEDBACK: J10.10
GND: C26.2, C27.2, J8.1, J10.1; also elsewhere on the board

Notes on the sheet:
Address extension
MM1 slot

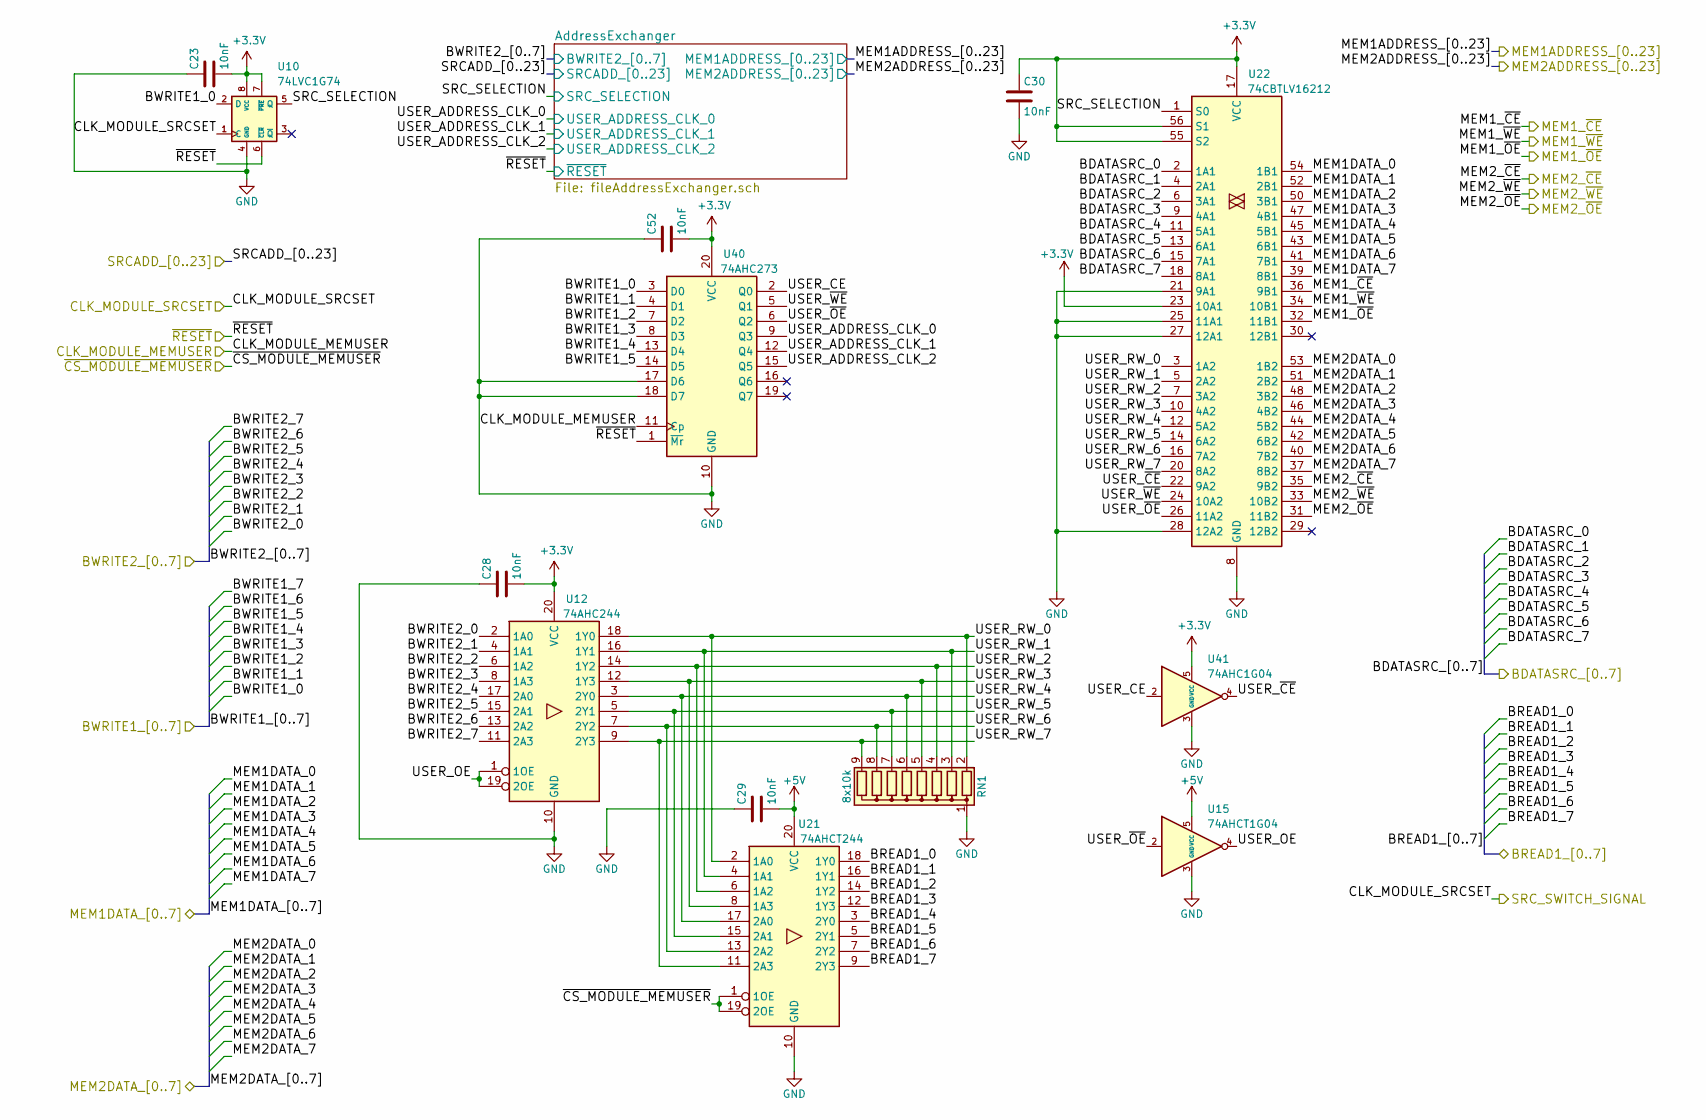
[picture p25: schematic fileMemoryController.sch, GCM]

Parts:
C23, C28, C29, C30, C52: 10nF; C_0805_2012Metric
RN1: 8x10k; R_Array_SIP9
U10: 74LVC1G74; SSOP-8_2.95x2.8mm_P0.65mm
U12: 74AHC244; SOIC-20W_7.5x12.8mm_P1.27mm
U15: 74AHCT1G04; SOT-23-5
U21: 74AHCT244; SOIC-20W_7.5x12.8mm_P1.27mm
U22: 74CBTLV16212; TSSOP-56_6.1x14mm_P0.5mm
U40: 74AHC273; SOIC-20W_7.5x12.8mm_P1.27mm
U41: 74AHC1G04; SOT-23-5

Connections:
+5V: C29.2, U15.5 (VCC), U21.20 (VCC); also elsewhere on the board
/BDATASRC_0: U22.2 (1A1); also elsewhere on the board
/BDATASRC_1: U22.4 (2A1); also elsewhere on the board
/BDATASRC_2: U22.6 (3A1); also elsewhere on the board
/BDATASRC_3: U22.9 (4A1); also elsewhere on the board
/BDATASRC_4: U22.11 (5A1); also elsewhere on the board
/BDATASRC_5: U22.13 (6A1); also elsewhere on the board
/BDATASRC_6: U22.15 (7A1); also elsewhere on the board
/BDATASRC_7: U22.18 (8A1); also elsewhere on the board
/CLK_MODULE_5: U40.11 (Cp); also elsewhere on the board
/CLK_MODULE_6: U10.1 (C); also elsewhere on the board
/ClockGenerator/BWRITE1_0: U10.2 (D), U40.3 (D0); also elsewhere on the board
/ClockGenerator/BWRITE1_1: U40.4 (D1); also elsewhere on the board
/ClockGenerator/BWRITE1_2: U40.7 (D2); also elsewhere on the board
/ClockGenerator/BWRITE1_3: U40.8 (D3); also elsewhere on the board
/ClockGenerator/BWRITE1_4: U40.13 (D4); also elsewhere on the board
/ClockGenerator/BWRITE1_5: U40.14 (D5); also elsewhere on the board
/Connector/BREAD1_0: U21.18 (1Y0); also elsewhere on the board
/Connector/BREAD1_1: U21.16 (1Y1); also elsewhere on the board
/Connector/BREAD1_2: U21.14 (1Y2); also elsewhere on the board
/Connector/BREAD1_3: U21.12 (1Y3); also elsewhere on the board
/Connector/BREAD1_4: U21.3 (2Y0); also elsewhere on the board
/Connector/BREAD1_5: U21.5 (2Y1); also elsewhere on the board
/Connector/BREAD1_6: U21.7 (2Y2); also elsewhere on the board
/Connector/BREAD1_7: U21.9 (2Y3); also elsewhere on the board
/Connector/BWRITE2_0: U12.2 (1A0); also elsewhere on the board
/Connector/BWRITE2_1: U12.4 (1A1); also elsewhere on the board
/Connector/BWRITE2_2: U12.6 (1A2); also elsewhere on the board
/Connector/BWRITE2_3: U12.8 (1A3); also elsewhere on the board
/Connector/BWRITE2_4: U12.17 (2A0); also elsewhere on the board
/Connector/BWRITE2_5: U12.15 (2A1); also elsewhere on the board
/Connector/BWRITE2_6: U12.13 (2A2); also elsewhere on the board
/Connector/BWRITE2_7: U12.11 (2A3); also elsewhere on the board
/MEM1_~CE: U22.36 (9B1); also elsewhere on the board
/MEM1_~OE: U22.32 (11B1); also elsewhere on the board
/MEM1_~WE: U22.34 (10B1); also elsewhere on the board
/MEM2_~CE: U22.35 (9B2); also elsewhere on the board
/MEM2_~OE: U22.31 (11B2); also elsewhere on the board
/MEM2_~WE: U22.33 (10B2); also elsewhere on the board
/MemoryController/MEM1DATA_0: U22.54 (1B1); also elsewhere on the board
/MemoryController/MEM1DATA_1: U22.52 (2B1); also elsewhere on the board
/MemoryController/MEM1DATA_2: U22.50 (3B1); also elsewhere on the board
/MemoryController/MEM1DATA_3: U22.47 (4B1); also elsewhere on the board
/MemoryController/MEM1DATA_4: U22.45 (5B1); also elsewhere on the board
/MemoryController/MEM1DATA_5: U22.43 (6B1); also elsewhere on the board
/MemoryController/MEM1DATA_6: U22.41 (7B1); also elsewhere on the board
/MemoryController/MEM1DATA_7: U22.39 (8B1); also elsewhere on the board
/MemoryController/MEM2DATA_0: U22.53 (1B2); also elsewhere on the board
/MemoryController/MEM2DATA_1: U22.51 (2B2); also elsewhere on the board
/MemoryController/MEM2DATA_2: U22.48 (3B2); also elsewhere on the board
/MemoryController/MEM2DATA_3: U22.46 (4B2); also elsewhere on the board
/MemoryController/MEM2DATA_4: U22.44 (5B2); also elsewhere on the board
/MemoryController/MEM2DATA_5: U22.42 (6B2); also elsewhere on the board
/MemoryController/MEM2DATA_6: U22.40 (7B2); also elsewhere on the board
/MemoryController/MEM2DATA_7: U22.37 (8B2); also elsewhere on the board
/MemoryController/SRC_SELECTION: U10.5 (Q), U22.1 (S0); also elsewhere on the board
/MemoryController/USER_ADDRESS_CLK_0: U40.9 (Q3); also elsewhere on the board
/MemoryController/USER_ADDRESS_CLK_1: U40.12 (Q4); also elsewhere on the board
/MemoryController/USER_ADDRESS_CLK_2: U40.15 (Q5); also elsewhere on the board
/MemoryController/USER_CE: U40.2 (Q0), U41.2
/MemoryController/USER_OE: U12.1 (1OE), U12.19 (2OE), U15.4
/MemoryController/USER_RW_0: RN1.2 (R1), U12.18 (1Y0), U21.2 (1A0), U22.3 (1A2)
/MemoryController/USER_RW_1: RN1.3 (R2), U12.16 (1Y1), U21.4 (1A1), U22.5 (2A2)
/MemoryController/USER_RW_2: RN1.4 (R3), U12.14 (1Y2), U21.6 (1A2), U22.7 (3A2)
/MemoryController/USER_RW_3: RN1.5 (R4), U12.12 (1Y3), U21.8 (1A3), U22.10 (4A2)
/MemoryController/USER_RW_4: RN1.6 (R5), U12.3 (2Y0), U21.17 (2A0), U22.12 (5A2)
/MemoryController/USER_RW_5: RN1.7 (R6), U12.5 (2Y1), U21.15 (2A1), U22.14 (6A2)
/MemoryController/USER_RW_6: RN1.8 (R7), U12.7 (2Y2), U21.13 (2A2), U22.16 (7A2)
/MemoryController/USER_RW_7: RN1.9 (R8), U12.9 (2Y3), U21.11 (2A3), U22.20 (8A2)
/MemoryController/USER_~CE: U22.22 (9A2), U41.4
/MemoryController/USER_~OE: U15.2, U22.26 (11A2), U40.6 (Q2)
/MemoryController/USER_~WE: U22.24 (10A2), U40.5 (Q1)
/~CS_MODULE_5: U21.1 (1OE), U21.19 (2OE); also elsewhere on the board
/~POWER_RESET: U10.6 (~CLR), U40.1 (~Mr); also elsewhere on the board
GND: C23.1, C28.1, C29.1, C30.2, C52.1, RN1.1 (common), U10.4 (GND), U12.10 (GND), U15.3 (GND), U21.10 (GND), U22.8 (GND), U22.19 (GND), U22.21 (9A1), U22.25 (11A1), U22.27 (12A1), U22.28 (12A2), U22.38 (GND), U22.49 (GND), U40.10 (GND), U40.17 (D6), U40.18 (D7), U41.3 (GND); also elsewhere on the board

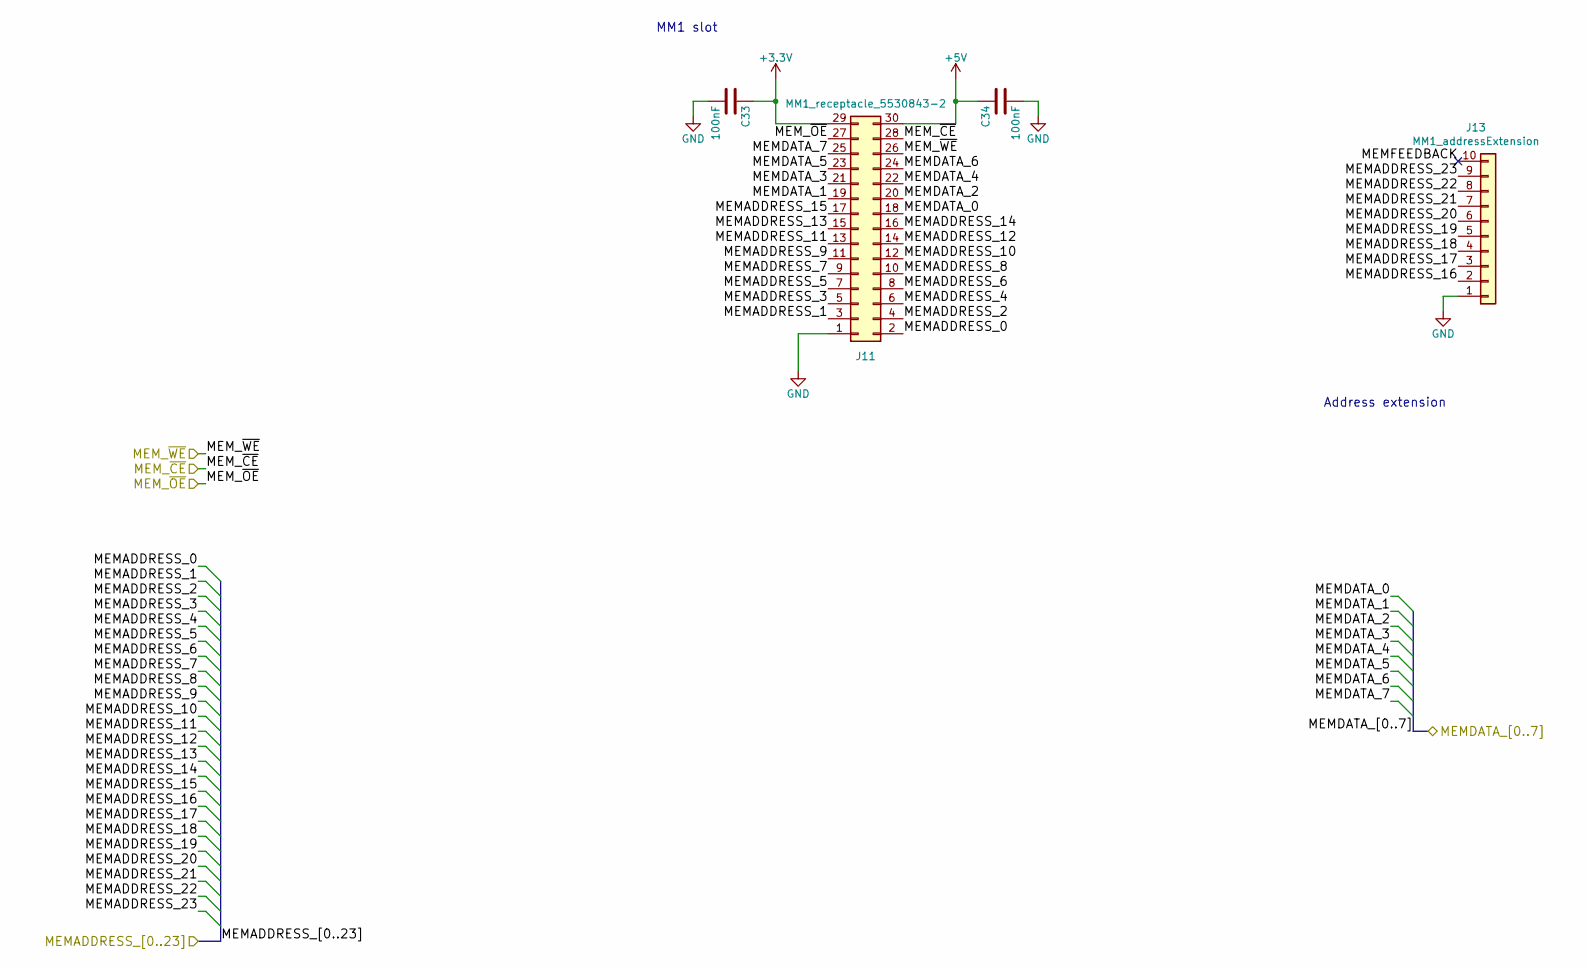
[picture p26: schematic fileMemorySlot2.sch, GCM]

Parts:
C26, C27: 100nF; C_0805_2012Metric
J8: MM1_receptacle_5530843-2; TE_5530843-2
J13: MM1_addressExtension; IDC-Header_2x05_P2.54mm_Vertical

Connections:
+5V: C27.1, J8.30; also elsewhere on the board
/MEM1_~CE: J8.28; also elsewhere on the board
/MEM1_~OE: J8.27; also elsewhere on the board
/MEM1_~WE: J8.26; also elsewhere on the board
/MemoryController/MEM1DATA_0: J8.18; also elsewhere on the board
/MemoryController/MEM1DATA_1: J8.19; also elsewhere on the board
/MemoryController/MEM1DATA_2: J8.20; also elsewhere on the board
/MemoryController/MEM1DATA_3: J8.21; also elsewhere on the board
/MemoryController/MEM1DATA_4: J8.22; also elsewhere on the board
/MemoryController/MEM1DATA_5: J8.23; also elsewhere on the board
/MemoryController/MEM1DATA_6: J8.24; also elsewhere on the board
/MemoryController/MEM1DATA_7: J8.25; also elsewhere on the board
/MemorySlot1/MEMADDRESS_0: J8.2; also elsewhere on the board
/MemorySlot1/MEMADDRESS_1: J8.3; also elsewhere on the board
/MemorySlot1/MEMADDRESS_2: J8.4; also elsewhere on the board
/MemorySlot1/MEMADDRESS_3: J8.5; also elsewhere on the board
/MemorySlot1/MEMADDRESS_4: J8.6; also elsewhere on the board
/MemorySlot1/MEMADDRESS_5: J8.7; also elsewhere on the board
/MemorySlot1/MEMADDRESS_6: J8.8; also elsewhere on the board
/MemorySlot1/MEMADDRESS_7: J8.9; also elsewhere on the board
/MemorySlot1/MEMADDRESS_8: J8.10; also elsewhere on the board
/MemorySlot1/MEMADDRESS_9: J8.11; also elsewhere on the board
/MemorySlot1/MEMADDRESS_10: J8.12; also elsewhere on the board
/MemorySlot1/MEMADDRESS_11: J8.13; also elsewhere on the board
/MemorySlot1/MEMADDRESS_12: J8.14; also elsewhere on the board
/MemorySlot1/MEMADDRESS_13: J8.15; also elsewhere on the board
/MemorySlot1/MEMADDRESS_14: J8.16; also elsewhere on the board
/MemorySlot1/MEMADDRESS_15: J8.17; also elsewhere on the board
/MemorySlot2/MEMADDRESS_16: J13.2; also elsewhere on the board
/MemorySlot2/MEMADDRESS_17: J13.3; also elsewhere on the board
/MemorySlot2/MEMADDRESS_18: J13.4; also elsewhere on the board
/MemorySlot2/MEMADDRESS_19: J13.5; also elsewhere on the board
/MemorySlot2/MEMADDRESS_20: J13.6; also elsewhere on the board
/MemorySlot2/MEMADDRESS_21: J13.7; also elsewhere on the board
/MemorySlot2/MEMADDRESS_22: J13.8; also elsewhere on the board
/MemorySlot2/MEMADDRESS_23: J13.9; also elsewhere on the board
/MemorySlot2/MEMFEEDBACK: J13.10
GND: C26.2, C27.2, J8.1, J13.1; also elsewhere on the board

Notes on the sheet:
Address extension
MM1 slot

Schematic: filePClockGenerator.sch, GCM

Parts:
C38, C39, C40, C41, C49, C50: 10nF; C_0805_2012Metric
U32: 74AHC273; SOIC-20W_7.5x12.8mm_P1.27mm
U33, U34: SN74LV393A; SOIC-14_3.9x8.7mm_P1.27mm
U35, U36, U37: CD74AC151; SOP-16_3.9x9.9mm_P1.27mm

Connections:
+5V: C38.2, C39.2, C40.2, C41.2, C49.2, C50.2, U32.20 (VCC), U33.14 (Vcc), U34.14 (Vcc), U35.16 (VCC), U36.16 (VCC), U37.16 (VCC); also elsewhere on the board
/CLK_MODULE_8: U32.11 (Cp); also elsewhere on the board
/ClockGenerator/BWRITE1_0: U32.3 (D0); also elsewhere on the board
/ClockGenerator/BWRITE1_1: U32.4 (D1); also elsewhere on the board
/ClockGenerator/BWRITE1_2: U32.7 (D2); also elsewhere on the board
/ClockGenerator/BWRITE1_3: U32.8 (D3); also elsewhere on the board
/ClockGenerator/BWRITE1_4: U32.13 (D4); also elsewhere on the board
/ClockGenerator/BWRITE1_5: U32.14 (D5); also elsewhere on the board
/ClockGenerator/BWRITE1_6: U32.17 (D6); also elsewhere on the board
/ClockGenerator/BWRITE1_7: U32.18 (D7); also elsewhere on the board
/ClockGenerator/CLK_50MHZ: U33.1 (1~CLK), U37.2 (D2); also elsewhere on the board
/ClockGenerator/PClockGenerator/CLK_50d2MHZ: U33.3 (1QA), U35.12 (D7)
/ClockGenerator/PClockGenerator/CLK_50d4MHZ: U33.4 (1QB), U35.13 (D6)
/ClockGenerator/PClockGenerator/CLK_50d8MHZ: U33.5 (1QC), U35.14 (D5)
/ClockGenerator/PClockGenerator/CLK_50d16MHZ: U33.6 (1QD), U33.13 (2~CLK), U35.15 (D4)
/ClockGenerator/PClockGenerator/CLK_50d32MHZ: U33.11 (2QA), U35.1 (D3)
/ClockGenerator/PClockGenerator/CLK_50d64MHZ: U33.10 (2QB), U35.2 (D2)
/ClockGenerator/PClockGenerator/CLK_50d128MHZ: U33.9 (2QC), U35.3 (D1)
/ClockGenerator/PClockGenerator/CLK_50d256MHZ: U33.8 (2QD), U34.1 (1~CLK), U35.4 (D0)
/ClockGenerator/PClockGenerator/CLK_50d512MHZ: U34.3 (1QA), U36.12 (D7)
/ClockGenerator/PClockGenerator/CLK_50d1024MHZ: U34.4 (1QB), U36.13 (D6)
/ClockGenerator/PClockGenerator/CLK_50d2048MHZ: U34.5 (1QC), U36.14 (D5)
/ClockGenerator/PClockGenerator/CLK_50d4096MHZ: U34.6 (1QD), U34.13 (2~CLK), U36.15 (D4)
/ClockGenerator/PClockGenerator/CLK_50d8192MHZ: U34.11 (2QA), U36.1 (D3)
/ClockGenerator/PClockGenerator/CLK_50d16384MHZ: U34.10 (2QB), U36.2 (D2)
/ClockGenerator/PClockGenerator/CLK_50d32768MHZ: U34.9 (2QC), U36.3 (D1)
/ClockGenerator/PClockGenerator/CLK_50d65536MHZ: U34.8 (2QD), U36.4 (D0)
/ClockGenerator/PClockGenerator/CLK_OUT_FAST: U35.5 (Y), U37.3 (D1)
/ClockGenerator/PClockGenerator/CLK_OUT_SLOW: U36.5 (Y), U37.4 (D0)
/ClockGenerator/PClockGenerator/CLK_SELECT_0: U32.16 (Q6), U37.11 (A)
/ClockGenerator/PClockGenerator/CLK_SELECT_1: U32.19 (Q7), U37.10 (B)
/ClockGenerator/PClockGenerator/CLK_SELECT_FAST_0: U32.2 (Q0), U35.11 (A)
/ClockGenerator/PClockGenerator/CLK_SELECT_FAST_1: U32.5 (Q1), U35.10 (B)
/ClockGenerator/PClockGenerator/CLK_SELECT_FAST_2: U32.6 (Q2), U35.9 (C)
/ClockGenerator/PClockGenerator/CLK_SELECT_SLOW_0: U32.9 (Q3), U36.11 (A)
/ClockGenerator/PClockGenerator/CLK_SELECT_SLOW_1: U32.12 (Q4), U36.10 (B)
/ClockGenerator/PClockGenerator/CLK_SELECT_SLOW_2: U32.15 (Q5), U36.9 (C)
/P_CLK: U37.5 (Y); also elsewhere on the board
/~POWER_RESET: U32.1 (~Mr); also elsewhere on the board
GND: C38.1, C39.1, C40.1, C41.1, C49.1, C50.1, U32.10 (GND), U33.2 (1CLR), U33.7 (GND), U33.12 (2CLR), U34.2 (1CLR), U34.7 (GND), U34.12 (2CLR), U35.7 (~G), U35.8 (GND), U36.7 (~G), U36.8 (GND), U37.1 (D3), U37.7 (~G), U37.8 (GND), U37.9 (C), U37.12 (D7), U37.13 (D6), U37.14 (D5), U37.15 (D4); also elsewhere on the board

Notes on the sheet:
Peripheral clock generation

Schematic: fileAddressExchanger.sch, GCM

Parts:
C31, C32, C53, C54, C55: 10nF; C_0805_2012Metric
U23, U24: 74CBTLV16212; TSSOP-56_6.1x14mm_P0.5mm
U42, U43, U44: 74AHC273; SOIC-20W_7.5x12.8mm_P1.27mm

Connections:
/Connector/BWRITE2_0: U42.3 (D0), U43.3 (D0), U44.3 (D0); also elsewhere on the board
/Connector/BWRITE2_1: U42.4 (D1), U43.4 (D1), U44.4 (D1); also elsewhere on the board
/Connector/BWRITE2_2: U42.7 (D2), U43.7 (D2), U44.7 (D2); also elsewhere on the board
/Connector/BWRITE2_3: U42.8 (D3), U43.8 (D3), U44.8 (D3); also elsewhere on the board
/Connector/BWRITE2_4: U42.13 (D4), U43.13 (D4), U44.13 (D4); also elsewhere on the board
/Connector/BWRITE2_5: U42.14 (D5), U43.14 (D5), U44.14 (D5); also elsewhere on the board
/Connector/BWRITE2_6: U42.17 (D6), U43.17 (D6), U44.17 (D6); also elsewhere on the board
/Connector/BWRITE2_7: U42.18 (D7), U43.18 (D7), U44.18 (D7); also elsewhere on the board
/MemoryController/AddressExchanger/USERADDRESS_0: U23.3 (1A2), U42.2 (Q0)
/MemoryController/AddressExchanger/USERADDRESS_1: U23.5 (2A2), U42.5 (Q1)
/MemoryController/AddressExchanger/USERADDRESS_2: U23.7 (3A2), U42.6 (Q2)
/MemoryController/AddressExchanger/USERADDRESS_3: U23.10 (4A2), U42.9 (Q3)
/MemoryController/AddressExchanger/USERADDRESS_4: U23.12 (5A2), U42.12 (Q4)
/MemoryController/AddressExchanger/USERADDRESS_5: U23.14 (6A2), U42.15 (Q5)
/MemoryController/AddressExchanger/USERADDRESS_6: U23.16 (7A2), U42.16 (Q6)
/MemoryController/AddressExchanger/USERADDRESS_7: U23.20 (8A2), U42.19 (Q7)
/MemoryController/AddressExchanger/USERADDRESS_8: U23.22 (9A2), U43.2 (Q0)
/MemoryController/AddressExchanger/USERADDRESS_9: U23.24 (10A2), U43.5 (Q1)
/MemoryController/AddressExchanger/USERADDRESS_10: U23.26 (11A2), U43.6 (Q2)
/MemoryController/AddressExchanger/USERADDRESS_11: U23.28 (12A2), U43.9 (Q3)
/MemoryController/AddressExchanger/USERADDRESS_12: U24.3 (1A2), U43.12 (Q4)
/MemoryController/AddressExchanger/USERADDRESS_13: U24.5 (2A2), U43.15 (Q5)
/MemoryController/AddressExchanger/USERADDRESS_14: U24.7 (3A2), U43.16 (Q6)
/MemoryController/AddressExchanger/USERADDRESS_15: U24.10 (4A2), U43.19 (Q7)
/MemoryController/AddressExchanger/USERADDRESS_16: U24.12 (5A2), U44.2 (Q0)
/MemoryController/AddressExchanger/USERADDRESS_17: U24.14 (6A2), U44.5 (Q1)
/MemoryController/AddressExchanger/USERADDRESS_18: U24.16 (7A2), U44.6 (Q2)
/MemoryController/AddressExchanger/USERADDRESS_19: U24.20 (8A2), U44.9 (Q3)
/MemoryController/AddressExchanger/USERADDRESS_20: U24.22 (9A2), U44.12 (Q4)
/MemoryController/AddressExchanger/USERADDRESS_21: U24.24 (10A2), U44.15 (Q5)
/MemoryController/AddressExchanger/USERADDRESS_22: U24.26 (11A2), U44.16 (Q6)
/MemoryController/AddressExchanger/USERADDRESS_23: U24.28 (12A2), U44.19 (Q7)
/MemoryController/SRC_SELECTION: U23.1 (S0), U24.1 (S0); also elsewhere on the board
/MemoryController/USER_ADDRESS_CLK_0: U42.11 (Cp); also elsewhere on the board
/MemoryController/USER_ADDRESS_CLK_1: U43.11 (Cp); also elsewhere on the board
/MemoryController/USER_ADDRESS_CLK_2: U44.11 (Cp); also elsewhere on the board
/MemorySlot1/MEMADDRESS_0: U23.54 (1B1); also elsewhere on the board
/MemorySlot1/MEMADDRESS_1: U23.52 (2B1); also elsewhere on the board
/MemorySlot1/MEMADDRESS_2: U23.50 (3B1); also elsewhere on the board
/MemorySlot1/MEMADDRESS_3: U23.47 (4B1); also elsewhere on the board
/MemorySlot1/MEMADDRESS_4: U23.45 (5B1); also elsewhere on the board
/MemorySlot1/MEMADDRESS_5: U23.43 (6B1); also elsewhere on the board
/MemorySlot1/MEMADDRESS_6: U23.41 (7B1); also elsewhere on the board
/MemorySlot1/MEMADDRESS_7: U23.39 (8B1); also elsewhere on the board
/MemorySlot1/MEMADDRESS_8: U23.36 (9B1); also elsewhere on the board
/MemorySlot1/MEMADDRESS_9: U23.34 (10B1); also elsewhere on the board
/MemorySlot1/MEMADDRESS_10: U23.32 (11B1); also elsewhere on the board
/MemorySlot1/MEMADDRESS_11: U23.30 (12B1); also elsewhere on the board
/MemorySlot1/MEMADDRESS_12: U24.54 (1B1); also elsewhere on the board
/MemorySlot1/MEMADDRESS_13: U24.52 (2B1); also elsewhere on the board
/MemorySlot1/MEMADDRESS_14: U24.50 (3B1); also elsewhere on the board
/MemorySlot1/MEMADDRESS_15: U24.47 (4B1); also elsewhere on the board
/MemorySlot1/MEMADDRESS_16: U24.45 (5B1); also elsewhere on the board
/MemorySlot1/MEMADDRESS_17: U24.43 (6B1); also elsewhere on the board
/MemorySlot1/MEMADDRESS_18: U24.41 (7B1); also elsewhere on the board
/MemorySlot1/MEMADDRESS_19: U24.39 (8B1); also elsewhere on the board
/MemorySlot1/MEMADDRESS_20: U24.36 (9B1); also elsewhere on the board
/MemorySlot1/MEMADDRESS_21: U24.34 (10B1); also elsewhere on the board
/MemorySlot1/MEMADDRESS_22: U24.32 (11B1); also elsewhere on the board
/MemorySlot1/MEMADDRESS_23: U24.30 (12B1); also elsewhere on the board
/MemorySlot2/MEMADDRESS_0: U23.53 (1B2); also elsewhere on the board
/MemorySlot2/MEMADDRESS_1: U23.51 (2B2); also elsewhere on the board
/MemorySlot2/MEMADDRESS_2: U23.48 (3B2); also elsewhere on the board
/MemorySlot2/MEMADDRESS_3: U23.46 (4B2); also elsewhere on the board
/MemorySlot2/MEMADDRESS_4: U23.44 (5B2); also elsewhere on the board
/MemorySlot2/MEMADDRESS_5: U23.42 (6B2); also elsewhere on the board
/MemorySlot2/MEMADDRESS_6: U23.40 (7B2); also elsewhere on the board
/MemorySlot2/MEMADDRESS_7: U23.37 (8B2); also elsewhere on the board
/MemorySlot2/MEMADDRESS_8: U23.35 (9B2); also elsewhere on the board
/MemorySlot2/MEMADDRESS_9: U23.33 (10B2); also elsewhere on the board
/MemorySlot2/MEMADDRESS_10: U23.31 (11B2); also elsewhere on the board
/MemorySlot2/MEMADDRESS_11: U23.29 (12B2); also elsewhere on the board
/MemorySlot2/MEMADDRESS_12: U24.53 (1B2); also elsewhere on the board
/MemorySlot2/MEMADDRESS_13: U24.51 (2B2); also elsewhere on the board
/MemorySlot2/MEMADDRESS_14: U24.48 (3B2); also elsewhere on the board
/MemorySlot2/MEMADDRESS_15: U24.46 (4B2); also elsewhere on the board
/MemorySlot2/MEMADDRESS_16: U24.44 (5B2); also elsewhere on the board
/MemorySlot2/MEMADDRESS_17: U24.42 (6B2); also elsewhere on the board
/MemorySlot2/MEMADDRESS_18: U24.40 (7B2); also elsewhere on the board
/MemorySlot2/MEMADDRESS_19: U24.37 (8B2); also elsewhere on the board
/MemorySlot2/MEMADDRESS_20: U24.35 (9B2); also elsewhere on the board
/MemorySlot2/MEMADDRESS_21: U24.33 (10B2); also elsewhere on the board
/MemorySlot2/MEMADDRESS_22: U24.31 (11B2); also elsewhere on the board
/MemorySlot2/MEMADDRESS_23: U24.29 (12B2); also elsewhere on the board
/SRCADD_0: U23.2 (1A1); also elsewhere on the board
/SRCADD_1: U23.4 (2A1); also elsewhere on the board
/SRCADD_2: U23.6 (3A1); also elsewhere on the board
/SRCADD_3: U23.9 (4A1); also elsewhere on the board
/SRCADD_4: U23.11 (5A1); also elsewhere on the board
/SRCADD_5: U23.13 (6A1); also elsewhere on the board
/SRCADD_6: U23.15 (7A1); also elsewhere on the board
/SRCADD_7: U23.18 (8A1); also elsewhere on the board
/SRCADD_8: U23.21 (9A1); also elsewhere on the board
/SRCADD_9: U23.23 (10A1); also elsewhere on the board
/SRCADD_10: U23.25 (11A1); also elsewhere on the board
/SRCADD_11: U23.27 (12A1); also elsewhere on the board
/SRCADD_12: U24.2 (1A1); also elsewhere on the board
/SRCADD_13: U24.4 (2A1); also elsewhere on the board
/SRCADD_14: U24.6 (3A1); also elsewhere on the board
/SRCADD_15: U24.9 (4A1); also elsewhere on the board
/SRCADD_16: U24.11 (5A1); also elsewhere on the board
/SRCADD_17: U24.13 (6A1); also elsewhere on the board
/SRCADD_18: U24.15 (7A1); also elsewhere on the board
/SRCADD_19: U24.18 (8A1); also elsewhere on the board
/SRCADD_20: U24.21 (9A1); also elsewhere on the board
/SRCADD_21: U24.23 (10A1); also elsewhere on the board
/SRCADD_22: U24.25 (11A1); also elsewhere on the board
/SRCADD_23: U24.27 (12A1); also elsewhere on the board
/~POWER_RESET: U42.1 (~Mr), U43.1 (~Mr), U44.1 (~Mr); also elsewhere on the board
GND: C31.2, C32.2, C53.1, C54.1, C55.1, U23.8 (GND), U23.19 (GND), U23.38 (GND), U23.49 (GND), U24.8 (GND), U24.19 (GND), U24.38 (GND), U24.49 (GND), U42.10 (GND), U43.10 (GND), U44.10 (GND); also elsewhere on the board

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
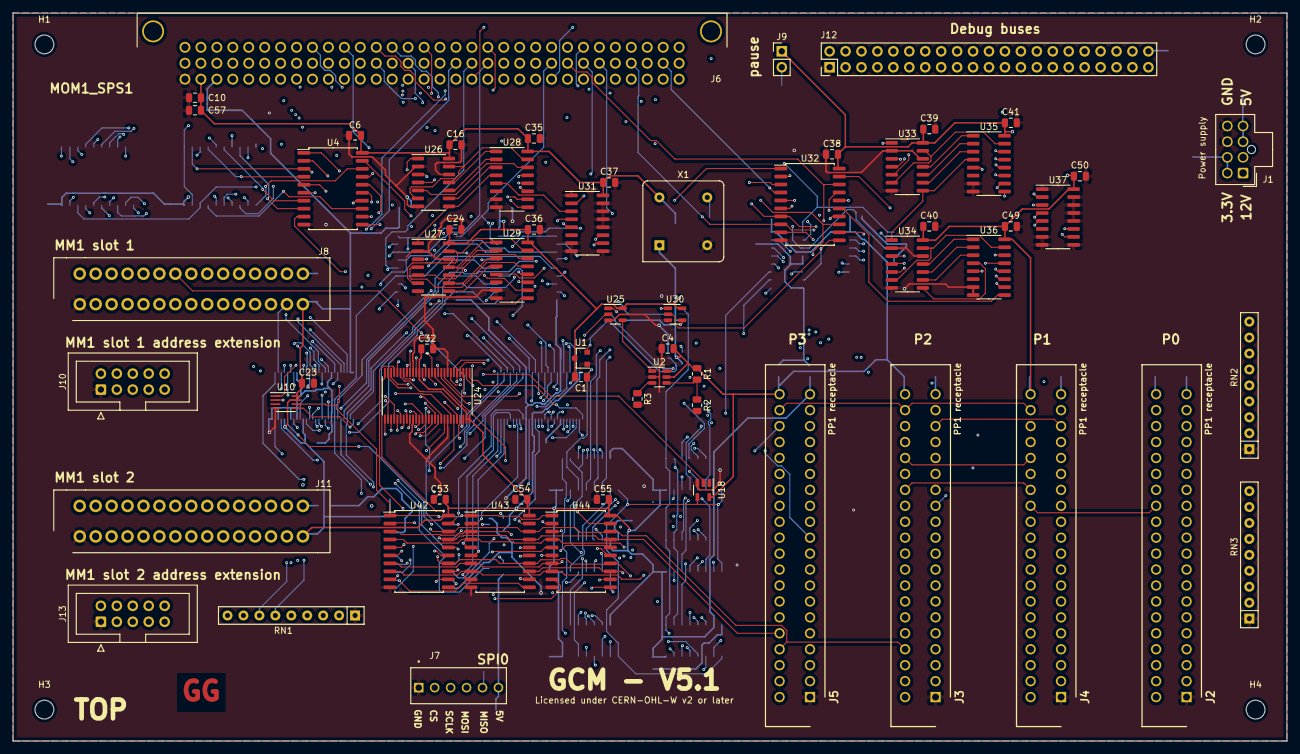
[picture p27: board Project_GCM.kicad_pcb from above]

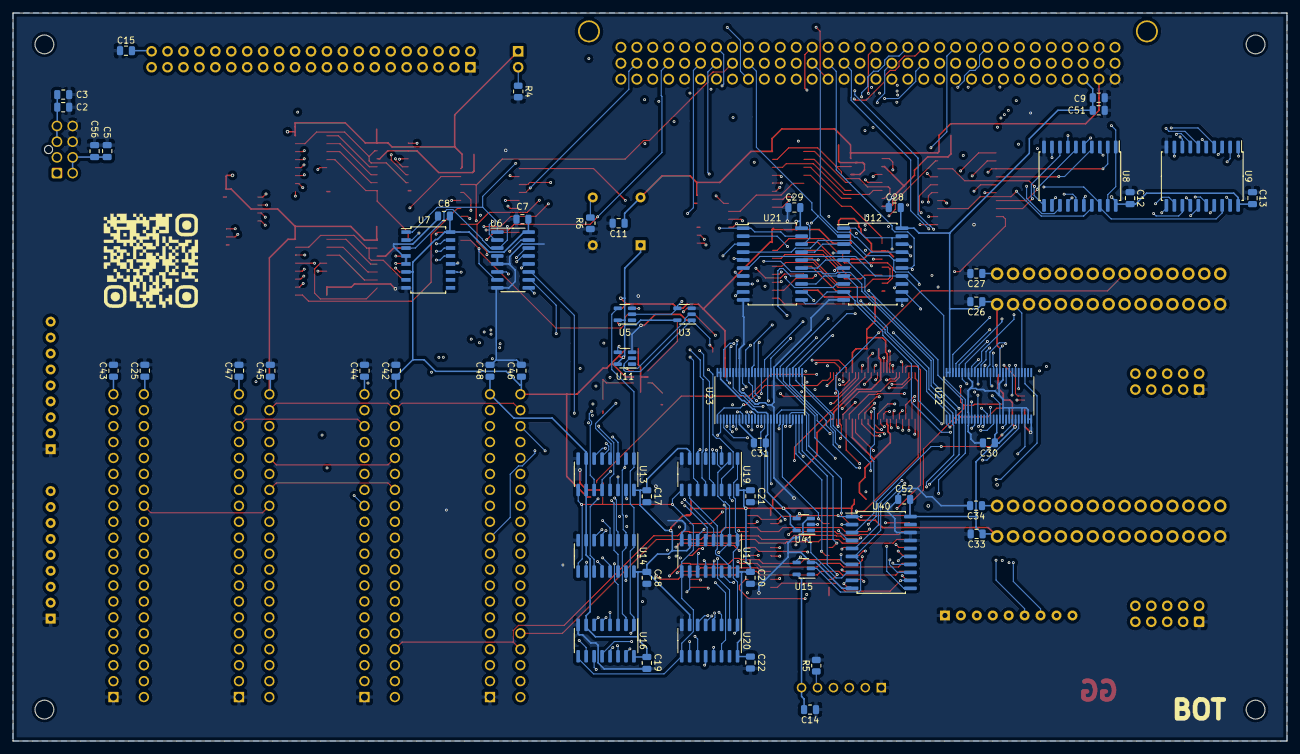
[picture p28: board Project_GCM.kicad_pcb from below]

Board: 4 copper layers, 203.0 x 116.0 mm, 127 parts (60 on the bottom side), 308 nets.

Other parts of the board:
C33, C34: 100nF; C_0805_2012Metric
GQR1: LOGO; QRCode
J11: MM1_receptacle_5530843-2; TE_5530843-2

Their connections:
+5V: C34.1, J11.30; also elsewhere on the board
/MEM2_~CE: J11.28; also elsewhere on the board
/MEM2_~OE: J11.27; also elsewhere on the board
/MEM2_~WE: J11.26; also elsewhere on the board
/MemoryController/MEM2DATA_0: J11.18; also elsewhere on the board
/MemoryController/MEM2DATA_1: J11.19; also elsewhere on the board
/MemoryController/MEM2DATA_2: J11.20; also elsewhere on the board
/MemoryController/MEM2DATA_3: J11.21; also elsewhere on the board
/MemoryController/MEM2DATA_4: J11.22; also elsewhere on the board
/MemoryController/MEM2DATA_5: J11.23; also elsewhere on the board
/MemoryController/MEM2DATA_6: J11.24; also elsewhere on the board
/MemoryController/MEM2DATA_7: J11.25; also elsewhere on the board
/MemorySlot2/MEMADDRESS_0: J11.2; also elsewhere on the board
/MemorySlot2/MEMADDRESS_1: J11.3; also elsewhere on the board
/MemorySlot2/MEMADDRESS_2: J11.4; also elsewhere on the board
/MemorySlot2/MEMADDRESS_3: J11.5; also elsewhere on the board
/MemorySlot2/MEMADDRESS_4: J11.6; also elsewhere on the board
/MemorySlot2/MEMADDRESS_5: J11.7; also elsewhere on the board
/MemorySlot2/MEMADDRESS_6: J11.8; also elsewhere on the board
/MemorySlot2/MEMADDRESS_7: J11.9; also elsewhere on the board
/MemorySlot2/MEMADDRESS_8: J11.10; also elsewhere on the board
/MemorySlot2/MEMADDRESS_9: J11.11; also elsewhere on the board
/MemorySlot2/MEMADDRESS_10: J11.12; also elsewhere on the board
/MemorySlot2/MEMADDRESS_11: J11.13; also elsewhere on the board
/MemorySlot2/MEMADDRESS_12: J11.14; also elsewhere on the board
/MemorySlot2/MEMADDRESS_13: J11.15; also elsewhere on the board
/MemorySlot2/MEMADDRESS_14: J11.16; also elsewhere on the board
/MemorySlot2/MEMADDRESS_15: J11.17; also elsewhere on the board
GND: C33.2, C34.2, J11.1; also elsewhere on the board

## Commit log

2020-01-09 initial upload
    [5530843-2.stp, 5650473-5.stp, AddressCounter.sch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]
2020-02-21 License info on silks
    [Project_GCM-B_Cu.gbr, Project_GCM-B_Mask.gbr, Project_GCM-B_SilkS.gbr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]
2020-03-09 Adding copyright and license notice
    [AddressCounter.sch, AddressExchanger.sch, ClockGenerator.sch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]
2020-04-11 Adding schematic in PDF
2020-04-11 Adding schematics (.pdf)
2020-09-24 Applying V5.0 and license to files
    [AddressCounter.sch, AddressExchanger.sch, ClockGenerator.sch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]
2020-09-24 Renaming and cleaning, documents folder
    [GCMV4_material.ods, RomTiming.xlsx, Timer32bit.xlsx]
2020-09-28 Multiple change : Replacing old custom "LTC6994-1" symbol with the Kicad symbol "LTC6994xS6-1" Replacing old custom "LM810" symbol with the Kicad symbol "LM810" Replacing all hidden power pins symbol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
    [AddressCounter.sch, Connector.sch, MemoryController.sch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]
2020-09-29 replacing 74LVC1G74 symbol
    [MemoryController.sch]
2020-09-29 adding a potential oscillator
    [ClockGenerator.sch]
2020-11-15 see CHANGELOG
    [AddressCounter.sch, AddressExchanger.sch, ClockGenerator.sch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]
2020-11-16 Update materials list, begin to work on pcb
    [Project_GCM.kicad_pcb, Project_GCM.sch, fileAddressCounter.sch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]
2020-11-17 First pass on the PCB
    [Project_GCM.kicad_pcb, fileMemorySlot1.sch, fileMemorySlot2.sch]
2020-11-18 Second pass on pcb
    [Project_GCM.kicad_pcb]
2020-11-18 Add QRcode
    [Project_GCM.kicad_pcb]
2020-11-23 First generation of gerbert files
    [Project_GCM-B_Cu.gbr, Project_GCM-B_Mask.gbr, Project_GCM-B_SilkS.gbr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]
2020-11-23 Removing useless doc, renaming/cleaning
    [RomTiming.xlsx]
2020-11-23 Removing old weird timer file and replace it with a wavedrom file
    [Timer32bit.xlsx]
2020-11-23 Update schematics date, pdf export
    [Project_GCM.sch, fileAddressCounter.sch, fileAddressExchanger.sch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]
2020-11-23 update PCB date, export PCB top/bot placement pdf
    [Project_GCM.kicad_pcb]
2020-11-27 datasheet R1, cleaning
    [Project_GCM-B_Cu.gbr, Project_GCM-B_Mask.gbr, Project_GCM-B_SilkS.gbr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]
2021-10-13 V5.1 (#15)
    * Remove compatibility for 5.0, 4.x and add 5.1+
    * Fix switched pins on SN74LV393A #7
    * Removed capacitor on 12V #11
    * Add/Modify power decoupling capacitor #10
    * Removing ADDSCR_CLK delay #9
    * Schematics : set version 5.1, 2021 copyright and publish date
    * Put non-electrolytic capacitor #10
    * Set every capacitor size to 0805
    * Add new footprint for J7 TE_3-641124-6 #6
    * Schematic : set pinHeader on J12 #4
    * Netlist, apply change to board, clean track, #6 #4 #12 #10
    * Set version to 5.1, 2021 copyright and date, replace the missing QRcode
    * Back the MM1 connectors #8
    * Replace capacitor for U22 U23 U24 #13
    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
    [Project_GCM-B_Cu.gbr, Project_GCM-B_Mask.gbr, Project_GCM-B_SilkS.gbr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]

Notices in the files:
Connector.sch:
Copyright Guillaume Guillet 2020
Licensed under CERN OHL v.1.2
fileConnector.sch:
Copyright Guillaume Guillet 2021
